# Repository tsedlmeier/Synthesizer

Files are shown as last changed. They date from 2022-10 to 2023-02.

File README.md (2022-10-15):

# Projektarbeit-Synthesizer

Dieses Repo ist in erster Linie für den Austausch von Dateien (LTspice-Modelle, Simulationen, Bauteilbibs etc.) gedacht.
Die Ordnerstruktur ist wie folgt: \
[ltspice/lib](./ltspice/lib/): hier könnt ihr eure Bauteilmodelle eintragen. \
[ltspice/<Modul>](./ltspice/): hier kann jeder einen Ordner mit dem Namen seines Moduls (VCO,VCF,VCA,ASMR,Sequencer,Netzteil etc.) erstellen und Simu-Dateien ablegen. 

Ansonsten erstellt jeder einen Ordner mit dem Namen seines Moduls und packt dort
Sachen rein, von denen er denkt, dass andere das sehen sollten.

## Nutzung des Repositorys

### Git-Konfiguration

Falls ihr noch nicht so viel Erfahrung mit Git habt hier ein kleines Intro.
Der Git-Config müsst ihr euren Namen und eure E-Mail-Adresse hinzufügen.

```bash
git config --global user.name "<Vorname> <Nachname>"
git config --global user.email "<verwendete E-Mail>"
```

Ihr solltet noch mit `git remote add origin git@github.com:tsedlmeier/Synthesizer.git` das Repo
unter dem Namen "origin" speichern (wird im weiteren Verlauf einfacher).

### SSH-Key eurem Git-Account hinzufügen

Damit könnt ihr Commits und Pulls durchführen, ohne dabei jedesmal euren Benutzernamen und Passwort
eingeben zu müssen. Dafür gebt ihr im Terminal `ssh-keygen` ein und wählt Pfad zum Key und Paraphrase (kann leer sein also einfach 2x Enter).
Jetzt sollte in eurem Home-Verzeichnis in dem Ordner ".ssh" eine Datei "id_<NAME>.pub" liegen. Den Inhalt
dieser Datei kopiert ihr bei eurem Git-Account im Browser unter "Settings -> SSH and GPG-Keys -> New
SSH-Key". Gebt eurem Key noch einen Namen.

### Klonen des Repos

Um das Repository auf eurem lokalen Rechner zu ziehen, müsst ihr dieses erstmal klonen (vorher Git konfigurieren!!!).

Das geschieht mit `git clone git@github.com:tsedlmeier/Synthesizer.git`.

### Änderungen an den Dateien durchführen

Ihr könnt mit `git checkout -b <BRANCH>` einen neuen Branch erstellen. (Ist für LTspice-Modelle etc.) eventuell etwas Overkill.

Änderungen ins Repo ziehen:

1. `git add <files>` 
2. `git commit -m "<kurze Nachricht an die Anderen was geändert wurde>"`
3. `git push`

### Lokales Repo aktualisieren

Wenn ihr die aktuellen Änderungen runterziehen wollt, dann geht das mit

```bash
git fetch origin
git pull --ff-only origin main
```

Eventuell vorhandene Branches müssen demnach auch aktualisiert werden. Dafür geht ihr in den Branch
und führt den Befehl `git rebase main` aus.

## Häufige Git-Befehle

|Kommando|Beschreibung|
|---|---|
|`git add <Files or Directory>`|Aktualisiert den Index mit den neuen Files|
|`git rm <Files or Directory>`|Entfernt die Files oder Directories vom Index|
|`git commit -m "<Message>"`|Erstellt einen Commit mit der Message, die mit -m angeben wird|
|`git push origin <Branch>`|Pusht die Daten vom Branch zu origin (Remote-Repo). Es sollte ein Pull-Request erzeugt werden|
|`git fetch origin`|Holt sich die Änderungen aus dem Remote-Repo "origin" (aber keine Aktualisierung des lokalen Repos!)|
|`git pull --ff-only origin main`|Aktualisiert den main-Branch des lokalen Repos (**im main-Branch ausführen!**) im Fast-Forward-Mode|
|`git checkout <Branch>`|Wechselt in den angegebenen Branch|
|`git checkout -b <Branch>`|Erstellt den angegebenen Branch und wechselt in diesen|
|`git status`|Zeigt anstehende Änderungen im aktuellen Branch an|
|`git log`|Zeigt die Commit Logs an|

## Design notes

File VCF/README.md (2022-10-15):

# Voltage Controlled Filter 
Hier eine kurze Doku zu meinem VCF. Dieses Markdown wird laufend aktualisiert.
Die Schaltung ist von Ray Wilson und auf der Website [MFOS] (http://musicfromouterspace.com/index.php?MAINTAB=SYNTHDIY&VPW=1344&VPH=561)
zu finden.

- [Anforderungen](#anforderungen)
- [Tiefpass](#tiefpass)
- [Hochpass](#hochpass)
- [CV](#cv)
- [Bauteile](#bauteile)
	<!--- - [Thema 3](#thema3)	-->

# Anforderungen
Folgende Annamen wurden getroffen:
- Eingangs CV V<sub>pp</sub> =~ 10V

| Parameter | Wert |
| --- | --- |
| `Gain` | `1 (0dB)` |
| `Cut-Off Frequenz ` | `100Hz - 10kHz` |
| `Resonanz (Q-Faktor)` | `TBD` |

# Tiefpass
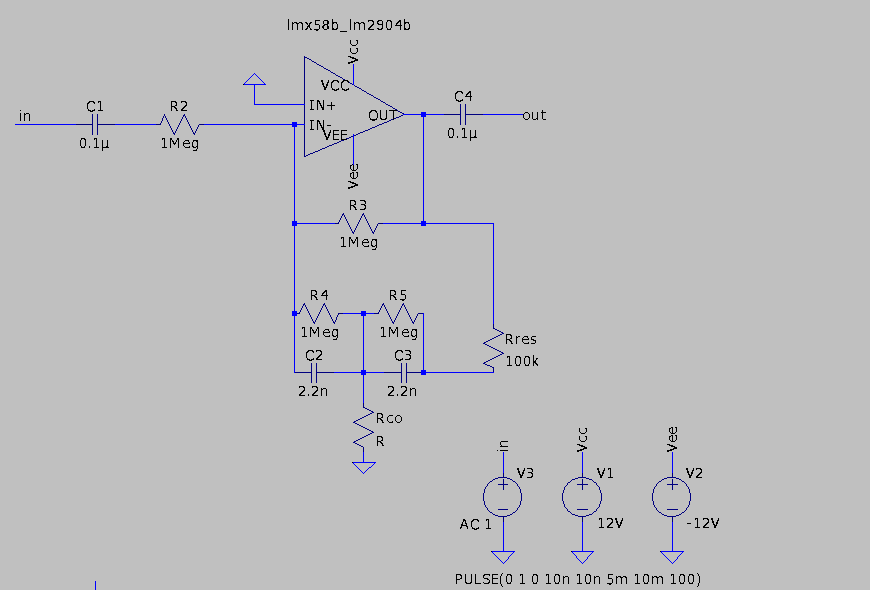
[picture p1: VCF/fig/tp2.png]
tp2

Es handelt sich um einen Aktiven Tiefpass 2. Ordnung mit einem Gain von 1.
Die Cut-Off Frequenz kann über den Rco eingestellt werden, indem er die Brücke aus den Kondensatoren C2 und C3 
näher bzw. weiter nach Ground zieht. Dieser wird später durch einen VCR (Voltage Controlled Resistor) ersetzt.
C1 wird für das Blocken von DC-Anteilen des Eingangssignals eingesetzt.
# Hochpass
# CV
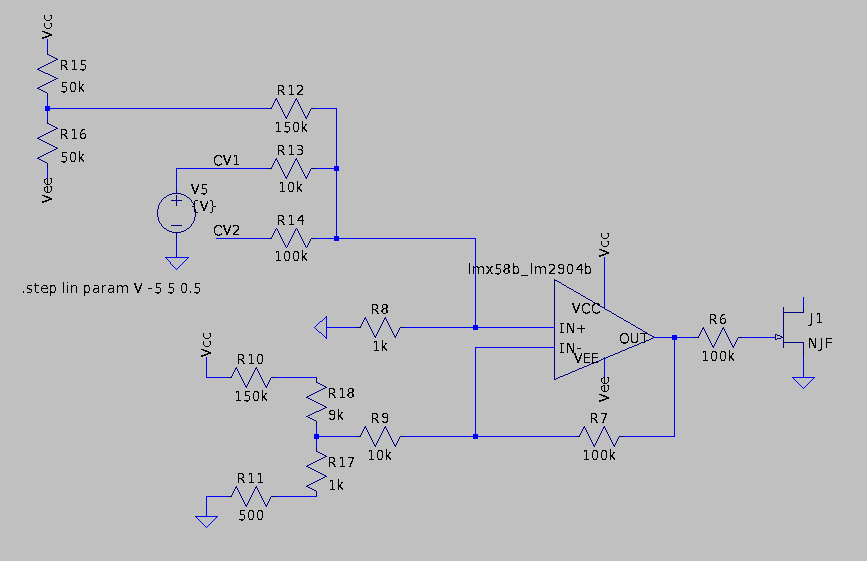
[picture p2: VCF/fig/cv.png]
cv

Hier handelt es sich um eine Schaltung für einen VCR (Voltage Controlled Resistor).
Dabei wird ein NJFET im ohmschen-Bereich betrieben.
Der 100k-Spannungsteiler aus R15 und R16 determinieren die Spannung V<sub>GS</sub> des NJFETs. 
Um den Spannungsbereich zu dieses Spannungsteilers einzustellen, wird ein weiterer Spannungsteiler aus R18 und R17 eingesetzt.
Zusammen mit R7 und R9, die den Verstärkunsfaktor des OPVs bestimmen, kann der Spannungsbereich von V<sub>GS</sub> eingestellt werden.
Diese Werte müssen auf den spezifisch verwendeten JFET abgestimmt werden.

# Bauteile
| Bauteil | Wert |
| --- | --- |
| `20x R` | `100 - 1MOhm` |
| `10x C` | `2.2nF - 1uF` |
| `4x OPV` | `LM358` |
| `1x NJFET` | `PN4391 NFET` |
| `4x Poti` | `100k` |
| `4x Klinke` | `3.5mm` |

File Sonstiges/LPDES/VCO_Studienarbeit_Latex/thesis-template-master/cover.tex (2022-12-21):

\thispagestyle{empty}
\pdfbookmark[1]{Cover}{cov}
\begin{titlepage}

\begin{center}

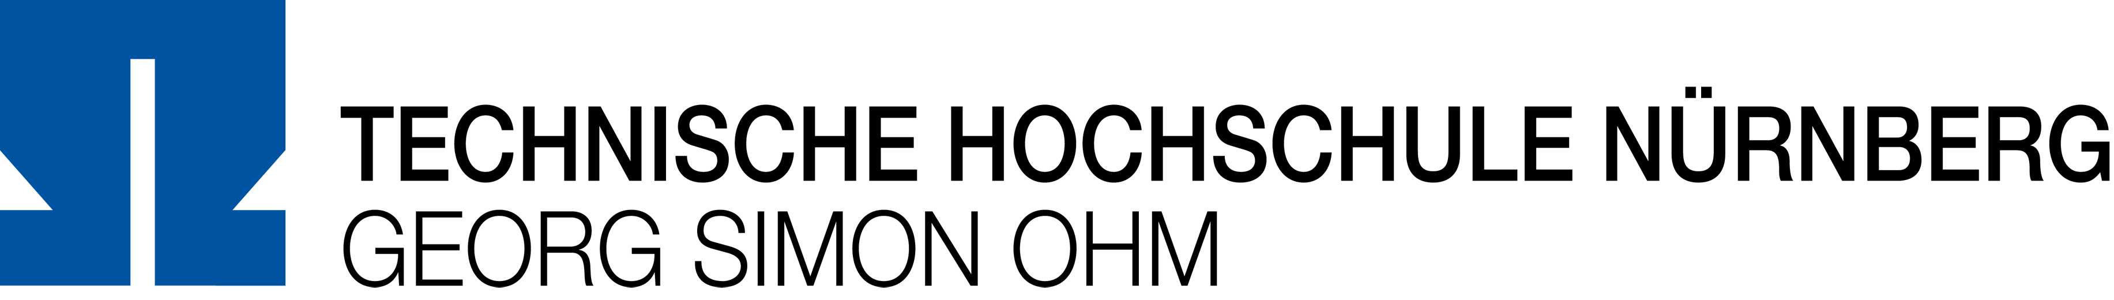
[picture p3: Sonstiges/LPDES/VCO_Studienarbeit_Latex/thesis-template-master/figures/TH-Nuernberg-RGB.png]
\\[1cm]
\LARGE{Fakultät Elektrotechnik Feinwerktechnik Informationstechnik}\\[2cm]

\huge
\textbf{\titel}\\[1cm]
%
\Large
\artderarbeit~im \studiengang\\[1cm]
%
\large
vorgelegt von

\Large
\autor\\[0.5cm]
\small

\vspace*{\fill}

\large
\begin{tabular}{p{3cm}p{8cm}}\\
%Ausgabe:  & \quad \ausgabe\\[1.2ex]
Abgabe: & \quad \abgabe\\[1.2ex]
Prüfer:  & \quad \erstgutachter\\[1.2ex]
%discomment "Betreuer" and "Unternehmen" for a thesis in a company
%Betreuer: & \quad \betreuer\\
%Unternehmen: & \quad \unternehmen
\end{tabular}
\end{center}

\begin{center}
\copyright\,\the\year
\end{center}

\vspace{-0.5cm}
\singlespacing
\small

\end{titlepage}

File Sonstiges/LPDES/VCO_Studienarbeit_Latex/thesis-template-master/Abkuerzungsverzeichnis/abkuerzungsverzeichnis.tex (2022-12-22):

\chapter{Abkürzungsverzeichnis}

%Erklärungen bündig
\setlist[description]{labelwidth=2cm}
\begin{acronym}
	\acro{ADSR}{\textit{Attack Decay Sustain Release}}
	 \acro{ERC}{\textit{Electrical Rule Check}}
	 \acro{DRC}{\textit{Design Rule Check}}
	\acro{LFO}{\textit{Low Frequency Oscillator}}
	\acro{VCA}{\textit{Voltage Controlled Amplifier}}
	\acro{VCF}{\textit{Voltage Controlled Filter}}
	\acro{VCO}{\textit{Voltage Controlled Oscillator}}
\end{acronym}

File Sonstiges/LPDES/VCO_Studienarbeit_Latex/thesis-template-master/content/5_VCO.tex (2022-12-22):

\chapter{VCO}
\label{ch:VCO}
\section{Allgemeines}

Der VCO stellt die Basis aller analogen Synthesizers da. 
Mit einem spannungsgesteuerten Oszillator lassen sich verschiedene Signale generieren, deren Frequenz sich mit der angelegten Steuerspannung verändert.
Analoge Synthesizer orientieren sich oft am 1V/Oktave-Standard.
Dieser besagt, dass sich die Frequenz des Signals mit jedem Volt verdoppelt.
Dies ist von Vorteil, da das Verhältnis zwischen Musiknoten und deren zugeordneten Frequenzen ebenfalls exponentiell ist.
Die tiefste C-Note entspricht beispielsweise einer Frequenz von 16,35 Hz.
Wenn man eine Oktave nach oben geht, verdoppelt sich die Frequenz beim nächsten C auf etwa 32 Hz. Typische Signale bei analogen Synthesizern können der Abbildung \ref{fig:Waveforms} entnommen werden. \cite{MakeSynth}

\begin{figure}[h]
	\centering
	\setlength{\fboxsep}{1pt} %Abstand der Linien zur Abbildung
	\setlength{\fboxrule}{1pt} %Dicke der Linie
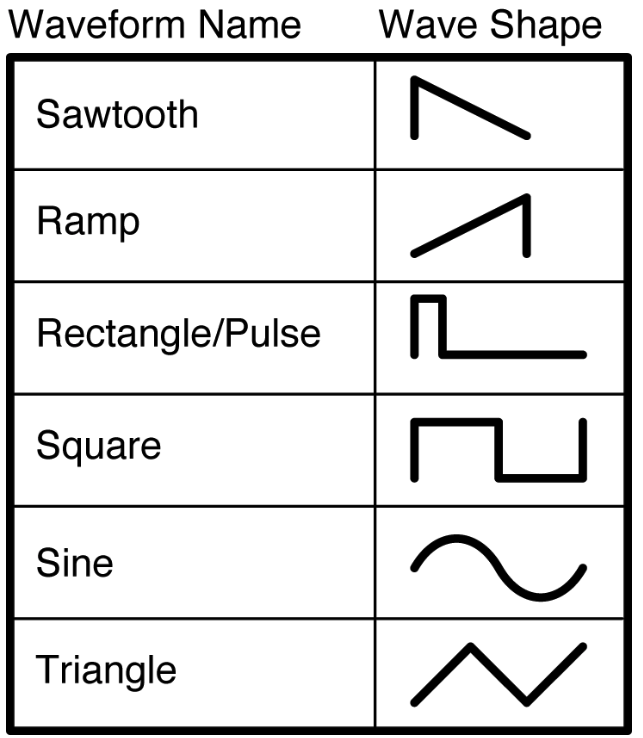
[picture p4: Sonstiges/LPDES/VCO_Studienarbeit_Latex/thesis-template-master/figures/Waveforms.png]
	\fbox{}
	\caption{Typische Signale bei analogen Synthesizern \cite{MakeSynth}}
	\label{fig:Waveforms}
\end{figure}

Bei dieser Umsetzung des VCOs wurde sich auf die Realisierung eines Sägezahn- und eines Rechtecksignals konzentriert, da diese aufgrund ihrem hohen Oberwellenanteil markant-hörbare Geräusche erzeugen.
Ein Sinussignal hingegen stellt einen harmonischen Verlauf dar, der sich ebenfalls im Klang äußert.
Hörbare Schwingungen werden mithilfe einer Oszillatorschaltung realisiert, auf die im Folgenden näher eingegangen wird.

\begin{figure}[h]
	\centering
	\setlength{\fboxsep}{1pt} %Abstand der Linien zur Abbildung
	\setlength{\fboxrule}{1pt} %Dicke der Linie
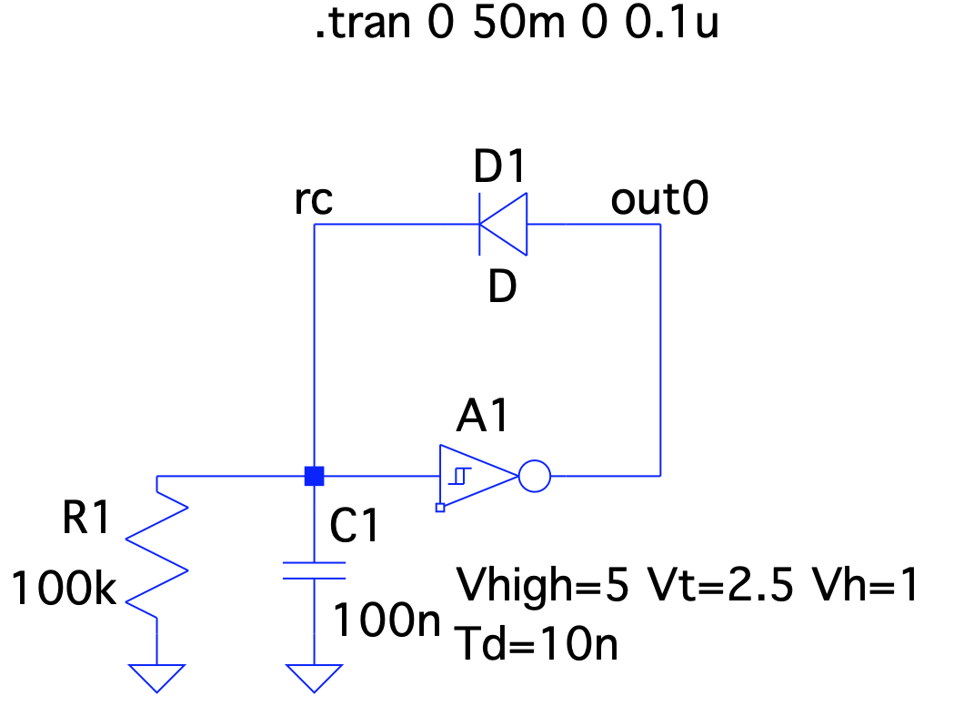
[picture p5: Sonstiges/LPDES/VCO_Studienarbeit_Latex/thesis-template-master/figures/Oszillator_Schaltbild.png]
	\fbox{}
	\caption{Oszillatorschaltung}
	\label{fig:Oszillatorschaltung}
\end{figure}

Um die Oszillatorschaltung (vgl. Abbildung \ref{fig:Oszillatorschaltung}), die den Kern des VCOs darstellt, zu verstehen, erfolgt die Betrachtung des Punktes \textit{rc}.
Zu Beginn liegt keine Spannung an, weil der Kondensator leer ist und noch kein Strom durch die Diode fließt. 
Das bedeutet, dass am Ausgang des Schmitt-Trigger-Inverters eine Spannung anliegt, da der Eingang unter dem unteren Eingangsschwellenwert liegt. 
Dadurch erfolgt ein Stromfluss vom Ausgang des Schmitt-Triggers über die Diode zu dem Punkt \textit{rc}. 
Da der Kondensator zunächst leer ist, fließt der ganze Strom in diesen hinein.
Während sich der Kondensator auflädt, steigt die Spannung an dem Punkt \textit{rc} rapide an.
Dieser Spannungsanstieg wird vom Schmitt-Trigger-Eingang registriert. 
Als Reaktion darauf fällt der Ausgang auf 0 V ab, sobald der Kondensator aufgeladen ist und die Spannung die obere Eingangsschwelle überschreitet.
Das bedeutet, dass kein zusätzlicher Strom durch die Diode fließt und sich der Kondensator wieder entlädt. 
Da der Widerstand die Strommenge begrenzt, die durchfließen kann, wird der Kondensator nicht sofort entladen. 
Auf dem Spannungsdiagramm entsteht also ein langsamer Abfall. 
Das geht so lange, bis der untere Schwellenwert des Schmitt-Trigger-Inverters erreicht wird. 
Sobald diese Schwelle auf dem Weg nach unten unterschritten ist, beginnt der Zyklus von neuem.
Die Simulation der Schaltung ergibt den Spannungsverlauf am Punkt \textit{rc} in Abbildung \ref{fig:Oszillator_Signalverlauf}.

\begin{figure}[h]
	\centering
	\setlength{\fboxsep}{1pt} %Abstand der Linien zur Abbildung
	\setlength{\fboxrule}{1pt} %Dicke der Linie
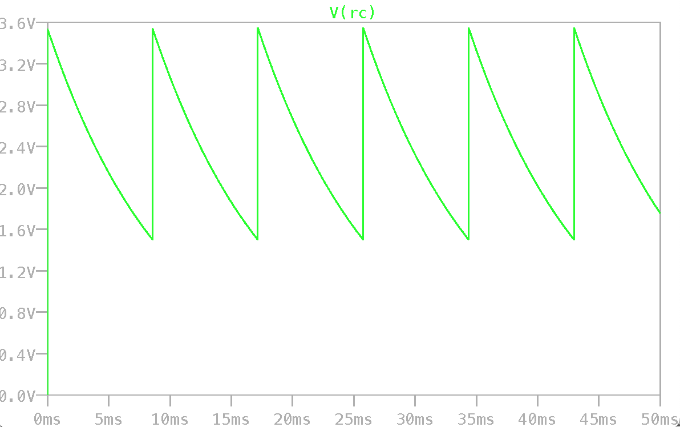
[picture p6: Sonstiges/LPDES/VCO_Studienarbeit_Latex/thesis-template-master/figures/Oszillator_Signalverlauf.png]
	\fbox{}
	\caption{Oszillator Signalverlauf}
	\label{fig:Oszillator_Signalverlauf}
\end{figure}

\newpage

Die Frequenz des entstandenen Sägezahnsignals hängt maßgeblich von dem Entladungsvorgang des Kondensators ab.
Die Geschwindigkeit dieses Entladungsvorganges wird widerum durch genau zwei Faktoren bestimmt: die Kapazität des Kondensators und der Wert des Widerstands.
Um den VCO an die Volt/Oktave-Norm anzupassen, muss die Beziehung zwischen Spannungseingang und Frequenzausgang ebenfalls exponentiell sein, da im Grunde genommen Spannungen auf Musiknoten abgebildet werden. 
Transistoren sind hier besonders geeignet, da das Verhältnis zwischen der an ihrer Basis angelegten Spannung und dem Strom, den sie zwischen Kollektor und Emitter fließen lassen, exponentiell ist.
Die Basisspannung kann mithilfe eines Potentiometers eingestellt werden.
Zu beachten ist allerdings, dass bei einem üblichen NPN-Transistor die Kollektor-Emitter Strecke ab etwa einer BasisSpannung von 600 -- 700 mV niederohmig wird und der Oszillator bei Anliegen dieser Schwellspannung nicht mehr schwingt. 
Liegt keine Spannung an, ist die Kollektor-Emitter Strecke hochohmig und der Oszillator kann ebenfalls nicht mehr schwingen.
Der durch Ausprobieren ermittelte nutzbare Spannungbereich beträgt etwa 350 -- 550 mV.
Dies wird mithilfe eines einstellbaren Spannungsteilers realisiert. 

Die verwendete Schaltung in Abbildung \ref{fig:VCO_Stromlaufplan} ist zu großen Teilen an ein \textit{DIY VCO Kit} von Moritz Klein und Erica Synths angelehnt und wird im Folgenden näher erklärt. \cite{vco_manual}

\section{Schaltplan}
Wie im vorherigen Kapitel erläutert, erfolgt die Veränderung der Frequenz der Sägezahnschwingung (vgl. Abbildung  \ref{fig:Oszillator_Signalverlauf}) mithilfe eines NPN-Transistors, welcher im ersten Bereich des Schaltplans zu sehen ist. 
Der davor geschaltene PNP-Transistor dient zur Temperaturkompensation und fungiert als Emitterfolger, indem die an seiner Basis anliegende Spannung an den Emitter kopiert wird.
Allerdings ist die am Emitter des PNP-Transistors anliegende Spannung um der Schwellspannung des Transistors höher.
Bei Versuchen an der realen Schaltung betrug diese etwa 500 mV.
Um den gewünschten Spannungsbereich an der Basis des NPN-Transistors von etwa 350 -- 550 mV zu erreichen, muss das Potentiometer für die Einstellung der Basisspannung der Transistoren auch negative Spannungswerte liefern.

Aus diesem Grund wird im zweiten Bereich des Schaltplans das Potentiometer VR1 für die grobe Einstellung der Frequenz zwischen der negativen und positiven Versorgunsspannung angeschlossen.
Da die Versorgungsspanung $\pm$12 V beträgt, wird diese mithilfe entsprechender Spannungteiler (R1, R2, R3, R7, R8) um etwa das 50-fache auf ca. -130 -- 20 mV verringert.
Für die Feineinstellung der Frequenz (VR2) wird durch einen größeren Widerstand (R4) ein Teilerfaktor von etwa 500 realisiert, der eine Spannung im Bereich von -10 -- 0 mV liefert.
Mithilfe dem Eingang \textit{CV\_IN} (\textit{Control Voltage In}) kann ein Sequencer mit einem Klinkenkabel angeschlossen werden, der eine Eingangsspannung von 0 -- 5 V liefert.
Um die Volt/Oktave-Norm anzuwenden wird aufgrund von Bauteiltoleranzen zusätzlich ein Präzisiondrehpotentiometer (R8) verwendet, damit das Verhältnis des Spannungsteilers justiert werden kann.
Die Klinkenbuchse \textit{FM\_IN} (\textit{Frequency Modulation In}) stellt im Prinzip einen weiteren \textit{Control Voltage}-Eingang dar, dessen Intensität zusätzlich durch ein Potentiometer eingestellt werden kann. 
An diesen kann beispielsweise ein LFO (\textit{Low Frequency Oscillator}) angeschlossen werden.
Um die Temperaturabhängigkeit der Schaltung zu verbessern, wird weiterhin an allen Eingängen ein NTC-Widerstand angebracht.

Um die resultierende Sägezahnschwingung nach außen führen zu können, wird ein entsprechender Buffer benötigt, der durch einen Operationsverstärker realisiert wird.
Dies ist zwingend notwendig, da ansonsten in die Funktionsweise der Oszillatorschaltung eingegriffen wird. 
Dieser Buffer befindet sich im dritten Bereich des Schaltplans.
Weiterhin wird eine AC-Kopplung mithilfe des Kondensators C2 und dem Widerstand R10 realisiert. 
Diese wird benötigt um eine eventuelle Offset-Spannung der Sägezahnspannung zu entfernen, damit das Signal um den definierten Pegel von 0 V schwingt.

Im vierten Bereich des Schaltplans wird das Rechtecksignal generiert. 
Dies erfolgt durch eine Komperatorschaltung.
An den invertierenden Eingang des Operationsverstärker wird die zu vergleichende Schwellspannung angelegt. 
Wird diese überschritten, liefert der Operationsverstärker 12 V. 
Bei Unterschreitung der Schwellspannung liefert dieser -12 V.
Wird die zu vergleichende Spannung variiert, ändert sich das Pulsbreitenverhältnis.
Zu beachten ist, dass die einstellbare Schwellspannung nicht höher als die Spannung des Signals selber sein darf, da dadurch der Ausgang einen festen Pegel erhält und kein oszillierendes Signal mehr darstellt.
Die Spannung des Sägezahnsignals beträgt an diesem Punkt etwa $\pm$1,5 V.
Durch das Potentiometer VR4 kann die Pulsbreite des Rechtecksignals eingestellt werden.
Mithilfe dem Spannungsteiler (R14, R17) wird die einstellbare Schwellspannung von $\pm$12 V auf etwa $\pm$1,5 V begrenzt, damit sichgerstellt wird, dass die Schwellspannung nicht höher als das Signal ist.
Mithilfe dem Eingang \textit{PWM\_In} kann die Pulsbreite durch ein anderes Signal wie beispielsweise eines LFOs extern moduliert werden.

Im fünften Bereich des Schaltplans erfolgt die Anpassung auf einen definierten Pegel von 10 V peak-to-peak. 
Da die Sägezahnschwingung eine geringe Spannung aufweist, wird diese mithilfe einer nicht invertierenden Verstärkerschaltung vergrößert und an den Klinkenbuchsenausgang \textit{SAW\_OUT} geführt. 
Da der Spannungspegel des Rechtecksignals durch die Komperatorschaltung verstärkt wurde, muss dieser mithilfe eines Spannungsteilers (R15, R18) entsprechend reduziert werden. 
Schließlich wird das Ausgangssignal durch einen Buffer an den Ausgang \textit{PULSE\_OUT} geführt.

Der nicht eingerahmte Bereich im Schaltplan umfasst die Spannungsversorgung. 
Mihilfe von Schottky-Dioden (D2, D3) wird der Verpolungsschutz der Eingangsspannung von $\pm$12 V gewährleistet. 
Durch die Stützkondensatoren (C3 -- C7) wird die Versorgungsspannung sowohl am Eingang der Spannungsversorgung am Wannenstecker als auch an den IC-Pins stabilisiert.
Weiterhin werden nicht verwendete Eingänge des Schmitt-Triggers mit Masse verbunden.

In der folgenden Tabelle werden die Ein- und Ausgabeelemente des VCOs zusammengefasst:

\begin{table}[h]
	\centering
	\caption{Zusammenfassung der Ein- und Ausgabeelemente des VCOs}
	\begin{tabular}{|c|c|p{8cm}|}
		\hline
		Bauteilbezeichnung & Kurzbeschreibung & Funktion \\
		\hline
		VR1 & \textit{Coarse} & Grobeinstellung der Frequenz \\
		\hline
		VR2 & \textit{Fine} & Feineinstellung der Frequenz \\
		\hline
		VR3 & \textit{FM LVL} & Einstellung der Intensität des FM-Eingangs \\
		\hline
		VR4 & \textit{PWM} & Einstellung der Pulsweite\\
		\hline
		VR5 & \textit{PWM LVL} &  Einstellung der Intensität des externen Signals zur Pulsweitenmodulation \\
		\hline
		J2 &  \textit{CV IN} & Eingang der Steuerspannung \\
		\hline
		J3 & \textit{FM IN} & Eingang der Steuerspannung \newline zusätzliche Einstellmöglichkeit der Intensität durch VR3 \\
		\hline
		J4 & \textit{PWM IN} &  Eingang des externen Signals zur Pulsweitenmodulation\\
		\hline
		J5 & \textit{Saw Out} &  Ausgang des generierten Sägezahnsignals\\
		\hline
		J5 & \textit{Pulse Out} &  Ausgang des generierten Rechtecksignals \\
		\hline
	\end{tabular}
\end{table}

Nachdem die Funktionsweise der Schaltung auf einem Breadboard verifiziert wurde, wird ein Platinenlayout erstellt.
Auf die Vorgehensweise bei der Layouterstellung wird im folgenden Kapitel näher eingegangen.

\newpage
\begin{figure}[h]
\centering
\includepdf[angle=270, clip, trim=1cm 0.8cm 0.8cm 0.8cm, scale=0.8] {figures/VCO_Stromlaufplan_v2_unterteilt.pdf}
%\caption{In Bereiche unterteilter Schaltplan des Sequenzers}
\caption{Schaltplan VCO}
\label{fig:VCO_Stromlaufplan}
\end{figure}

\newpage

\section{Platine}
Nachdem der Schaltplan in Fusion 360 erstellt wurde und mit dem ERC (Electrical Rule Check)-Tool validiert wurde, erfolgt die Erstellung des Platinenlayouts (siehe Abbildung \ref{fig:VCO Layout}).
Die äußeren Abmaße der Platine sind in Bezug auf die Höhe eines \textit{Euro Racks} von 128,5 mm beschränkt. 
Gewählt wurde eine Platinenhöhe von 100 mm, damit ausreichend Platz zur Befestigung der Leiterplatte gewährleistet ist.

\begin{figure}[h]
	\centering
	\setlength{\fboxsep}{1pt} %Abstand der Linien zur Abbildung
	\setlength{\fboxrule}{1pt} %Dicke der Linie
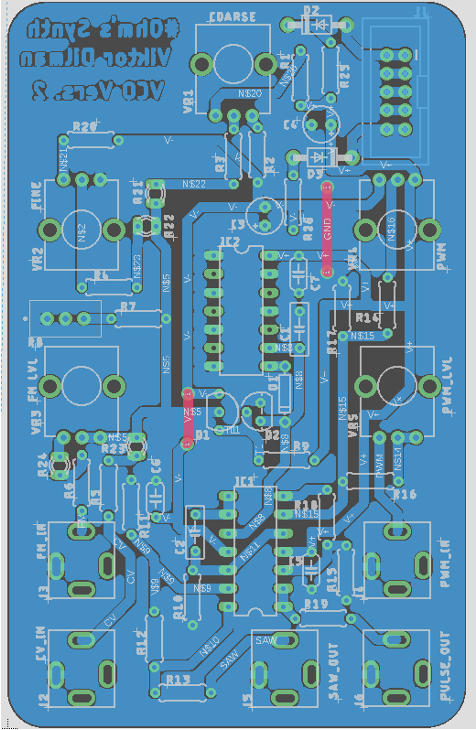
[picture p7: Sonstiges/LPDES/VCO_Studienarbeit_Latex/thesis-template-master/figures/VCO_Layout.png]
	\fbox{}
	\caption{VCO Layout in Fusion 360}
	\label{fig:VCO Layout}
\end{figure}

Die Bauteile wurden einerseits so positioniert, dass die Leiterbahnen möglichst kurz und überschneidungsfrei verlegt werden können.
Andererseits wurden die Potentiometer und Klinkenbuchsen logisch so angeordnet dass die zu einer Einbauklinkenbuchse gehörenden Potentiometer übereinander liegen.
Weiterhin wurde darauf geachtet, dass die Transistoren für die Temperaturkompensation möglichst nah aneinander positioniert werden.
Zudem sind die Stützkondensatoren der ICs möglichst nah an den Versorgungspins der Bauteile zu positionieren.

Bei der Erstellung der Platine wurde darauf geachtet möglichst eine Layer zu verwenden, um die Platine mit einer Platinenfräse herstellen zu können.
Dies ist von Vorteil, da bei der professionellen Anfertigung von Platinen von der Bestellung bis zur Lieferung einige Wochen vergehen können.
Ist der Zugang zu einer Fräse gegeben, kann die erstellte Platine sofort getestet und eventuelle Fehler ausgebessert werden.

Damit die Leiterplatte mit einer Platinenfräse angefertigt werden kann, ist eine relativ dicke Leiterbahnbreite erforderlich. 
Gewählt wurde deshalb eine Leiterbrahnbreite von 50 mil.
An den Stellen, an denen die Leiterbahnen nicht überschneidungsfrei verlegt werden konnten, wurden \textit{Vias} hinzugefügt und die Leiterbahn auf der anderen Seite fortgeführt.
Auf der gefrästen Platinen können diese \textit{Vias} mit Brücken verbunden werden.

Da für die verwendeten Einbauklinkenbuchsen keine passende Bibliothek existiert, musste diese manuell angelegt werden.
Dafür wurde ein Symbol einer ähnlichen Klinkenbuchse verwendet und das Footprint nach dem Datenblatt des Herstellers erstellt wie in Abbildung \ref{fig:Einbauklinkenbuchse in Fusion 360} zu sehen. \cite{cliff}

\begin{figure}[h]

\end{figure}

\begin{figure}[h]
	\centering
	\begin{subfigure}{.5\textwidth}
	\centering
	\setlength{\fboxsep}{1pt} %Abstand der Linien zur Abbildung
	\setlength{\fboxrule}{1pt} %Dicke der Linie
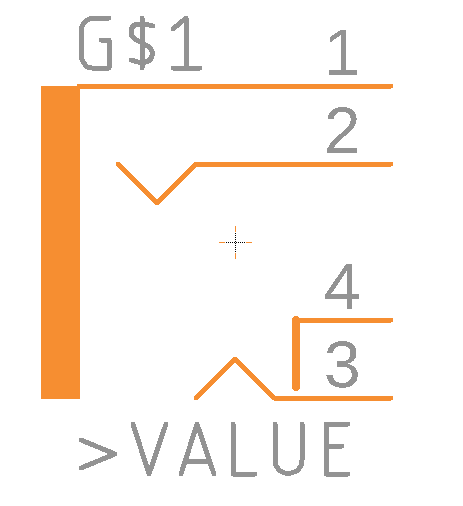
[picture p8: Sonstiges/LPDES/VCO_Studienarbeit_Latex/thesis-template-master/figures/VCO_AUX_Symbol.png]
	\fbox{}
	\caption{Verwendetes Symbol}
	\label{fig:Klinkenbuchse Symbol}
	\end{subfigure}%
	\begin{subfigure}{.5\textwidth}
	\centering
	\setlength{\fboxsep}{1pt} %Abstand der Linien zur Abbildung
	\setlength{\fboxrule}{1pt} %Dicke der Linie
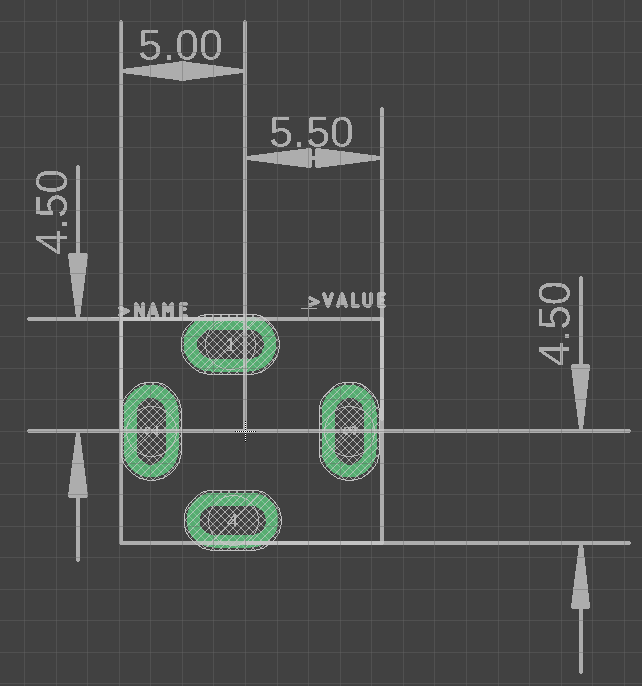
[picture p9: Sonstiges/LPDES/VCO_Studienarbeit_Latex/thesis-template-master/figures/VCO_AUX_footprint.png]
	\fbox{}
	\caption{Erstelltes Footprint}
	\label{fig:Klinkenbuchse Footprint}
	\end{subfigure}
	\caption{Erstellung der Einbauklinkenbuchse in Fusion 360}
	\label{fig:Einbauklinkenbuchse in Fusion 360}
\end{figure}

Nachdem die erstellte Leiterplatte mit dem DRC (\textit{Design Rule Check})-Tool in \textit{Fusion 360} auf Fehlerfreiheit geprüft wurde, erfolgt der Export der \textit{Gerber-Files}.
%\begin{figure}[h]
%	\centering
%	\setlength{\fboxsep}{1pt} %Abstand der Linien zur Abbildung
%	\setlength{\fboxrule}{1pt} %Dicke der Linie
%	\fbox{\includegraphics[width=0.5\textwidth]{figures/Fusion Export Gerber}}
%	\caption{Fusion 360 Gerber Export}
%	\label{fig:Gerber}
%\end{figure}
Die Leiterplatte wurde dabei mit einer Platinenfräse von \textit{Bantam Tools} hergestellt.
%\begin{figure}[h]
%	\centering
%	\setlength{\fboxsep}{1pt} %Abstand der Linien zur Abbildung
%	\setlength{\fboxrule}{1pt} %Dicke der Linie
%	\fbox{\includegraphics[width=0.5\textwidth]{figures/VCO_gefraest}}
%	\caption{VCO Platine gefräst}
%	\label{fig:VCO Fräse}
%\end{figure}
%\newpage
Anschließend erfolgt die Bestückung der Leiterplatte mit den im Stromlaufplan verwendeten Komponenten und das Testen der Platine. 
Ist die Funktion der gefrästen Leiterplatte geprüft, erfolgt die Bestellung bei dem Platinenhersteller \textit{Aisler}. 
In Abbildung \ref{fig:VCO_Front} ist die Vorderseite der Platine zu sehen.
Die Abbildung \ref{fig:VCO_Back} zeigt hingegen die Rückseite der VCO-Leiterplatte. 

\begin{figure}[h]
	\centering
	\begin{subfigure}{.5\textwidth}
		\centering
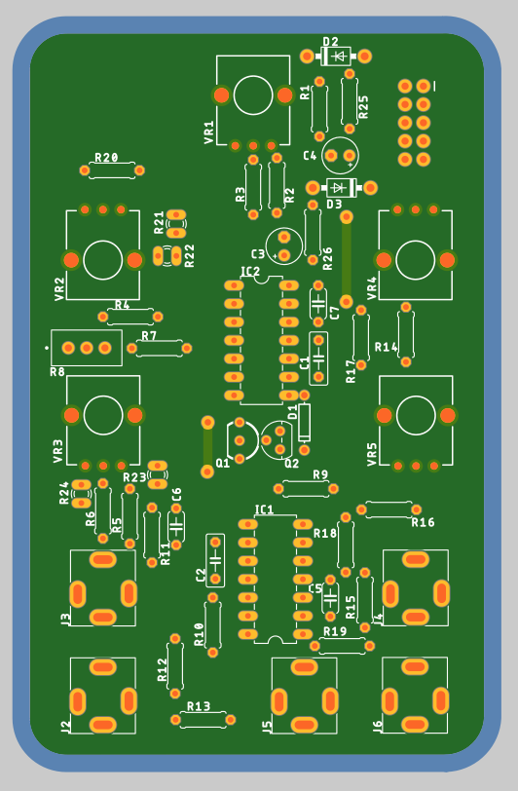
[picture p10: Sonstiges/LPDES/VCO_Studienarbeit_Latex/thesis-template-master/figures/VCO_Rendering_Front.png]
		
		\caption{Vorderseite}
		\label{fig:VCO_Front}
	\end{subfigure}%
	\begin{subfigure}{.5\textwidth}
		\centering
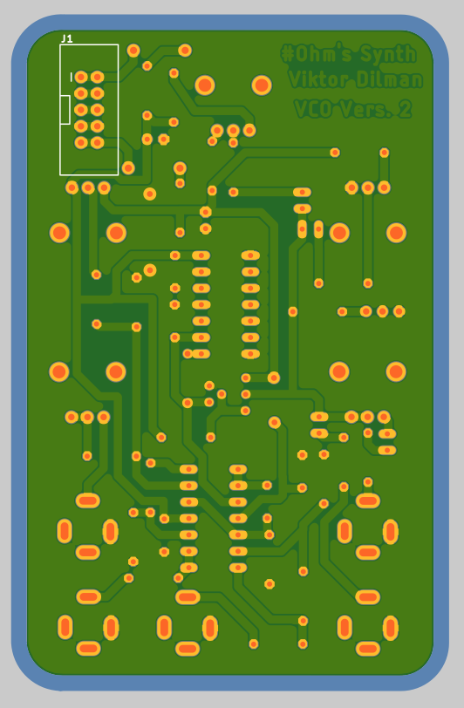
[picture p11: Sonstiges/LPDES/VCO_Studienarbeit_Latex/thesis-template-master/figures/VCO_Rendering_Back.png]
		
		\caption{Rückseite}
		\label{fig:VCO_Back}
	\end{subfigure}
	\caption{VCO Leiterplatte}
	\label{fig:VCO Leiterplatte}
\end{figure}

\newpage
\section{Mechanischer Aufbau}
Mithilfe der \textit{Fusion 360}-Funktionalität der Übertragung einer 2D- auf eine 3D-Leiterplatte wurde eine Abdeckung konstruiert (siehe Abbildung \ref{fig:VCO Frontplattemit 3D-Leiterplatte}).
Dies hat den Vorteil, dass für die Potentiometer und Klinkenbuchsen die Aussparungen an der Frontplatte exakt positioniert werden können.
Die Abdeckplatte wird mithilfe von Gewindeschrauben der Einbauklinkenbuchsen an die Platine befestigt.
Weiterhin werden auf die Potentiometer Abdeckkappen angebracht, die zusätzlichen Halt bieten.
An den Ecken der Frontplatte werden Aussparungen vorhergesehen, um das Modul in einem Eurorack-Gehäuse befestigen zu können.
Schließlich wird die Frontplatte aus Plexiglas mit einem \textit{Laser-Cutter} gefertigt.

\begin{figure}[h]
	\centering
	\setlength{\fboxsep}{1pt} %Abstand der Linien zur Abbildung
	\setlength{\fboxrule}{1pt} %Dicke der Linie
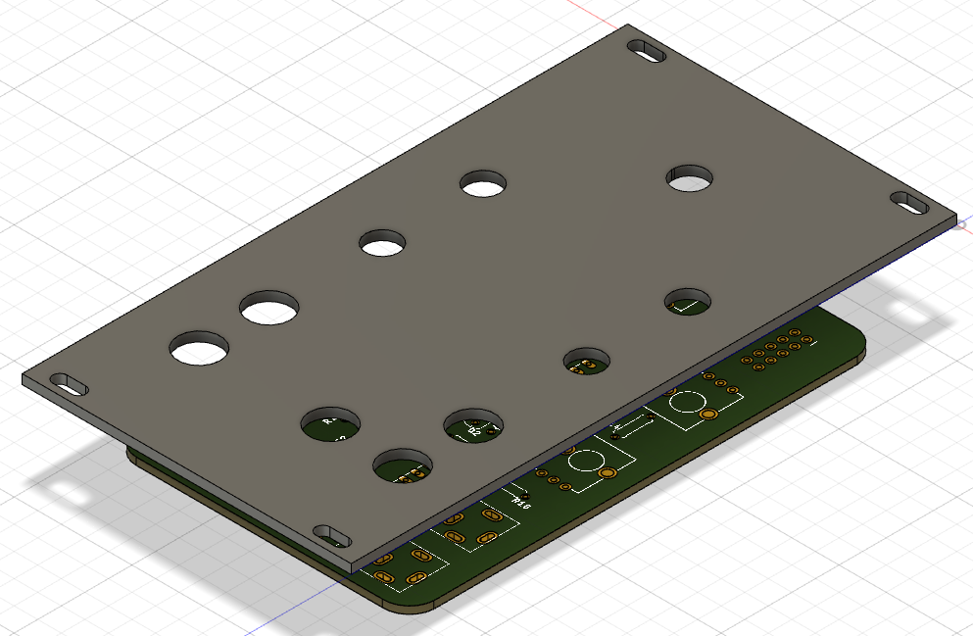
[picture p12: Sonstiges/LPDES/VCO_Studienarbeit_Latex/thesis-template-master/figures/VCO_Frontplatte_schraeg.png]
	\fbox{}
	\caption{VCO Frontplatte}
	\label{fig:VCO Frontplattemit 3D-Leiterplatte}
\end{figure}

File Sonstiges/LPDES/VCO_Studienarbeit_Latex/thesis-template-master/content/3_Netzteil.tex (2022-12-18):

\chapter{Netzteil}
\label{ch:Netzteil}

\section{Allgemeines}
Um eine fehlerfreie Funktion aller weiteren Module zu gewährleisten, ist es wichtig, dass eine geeignete Spannungsversorgung bereitgestellt wird. 
Insbesondere für die Opamp-Schaltungen ist es wichtig, dass eine störfreie symmetrische Spannung bereitgestellt wird. 
Im Bereich der modularen Synthesizer wird hier typischerweise eine Spannung von +/- 12 V benötigt. Diese Spannungspegel werden durch eine geignete Beschaltung von Dioden und Kondensatoren generiert, welche in Abschnitt \ref{sec:netzteil_schaltplan} bzw. \ref{sec:netzteil_umsetzung} genauer erläutert wird. Hierbei wird die für modulare Synthesizer typischerweise eingesetzte Wannenstecker-Belegung verwendet. Diese wird entsprechend in allen Modulen eingesetzt!

\section{Schaltplan}
\label{sec:netzteil_schaltplan}
bla bla bla

\section{Umsetzung}
\label{sec:netzteil_umsetzung}
bla bla bla

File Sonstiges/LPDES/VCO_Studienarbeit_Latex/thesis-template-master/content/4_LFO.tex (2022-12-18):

\chapter{LFO}
\label{ch:LFO}

\section{Allgemeines}
Wie bereits in Kapitel \label{ch:concept} beschrieben, wird der LFO genutzt, um niederfrequente Signale zu erzeugen. 
Diese Signale werden typischerweise zur Steuerung von nachgelagerten Modulen, wie etwa dem LFO (siehe Kapitel \ref{ch:VCO}), verwendet.
Hierdurch kann beispielsweise die Frequenz des VCO angepasst werden. 
Neben der Frequenz, die der LFO ausgibt, ist auch die entsprechende Signalform für den Klang entscheidend. Hier sind beispielsweise Signalformen, wie Dreieck oder Rechteck möglich.

\section{Schaltplan}
Im Folgenden wird näher auf den Schaltplan des LFO eingegangen, welcher in Abbildung \ref{fig:LFO_Stromlaufplan} zu sehen ist. 
Ein Bauteil von zentraler Bedeutung ist hierbei der Vierfach-Operationsverstärker TL074P. In der gezeigten Schaltung wird dieser als Integrator, Schmitt Trigger, Buffer und LED-Treiber verwendet.
Die grundlegende Funktionsweise dieser Funktionsgruppen wurde bereits in Abschnitt \ref{sec:AnalogePrinzipien} erläutert und wird deshalb nicht erneut aufgezeigt.

\newpage
\begin{figure}[h]
\centering
\includepdf[angle=270, clip, trim=1cm 0.8cm 0.8cm 0.8cm, scale=0.8] {figures/Schaltplan_LFO_Kirschner_08_12_22.pdf}
\caption{Fusion360 Schaltplan des LFO}
\label{fig:LFO_Stromlaufplan}
\end{figure}
 
\newpage

\section{Platine}
bla bla bla

\section{Mechanischer Aufbau}
bla bla bla

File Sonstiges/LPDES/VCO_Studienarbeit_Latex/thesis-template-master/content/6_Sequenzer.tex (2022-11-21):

\chapter{Sequenzer}
\label{ch:Sequenzer}
\section{Allgemeines}
Bei dieser Umsetzung eines Sequenzers wurde sich für maximal fünf alternierende Spannungspegel entschieden. In der Literatur ist diese Unterart als 5-Step-Sequencer bekannt, welche wegen ihrer markanten Charakteristik zum Beispiel im bekannten >>Hier Name des Syntis im Labor einsetzten<< Synthesizer eingesetzt wird. >>Als Quelle Manual von genanntem Synti nennen<<. Über zwei in der Handebene verbaute Kippschalter kann alternativ zwischen 3- bzw. 4-Stufen-Betrieb gewählt werden. Welcher Schritt aktuell aktiv ist wird durch Status-LEDs in der Frontplatte angezeigt.\\
Als Spannungsversorgung erhält der Sequenzer \textpm 12 Volt durch das verbaute Netzteil (vgl. Kapitel \ref{ch:Netzteil}). Optional kann ein externes Clock-Signal, beispielsweise von einem LFO (vgl. Kapitel \ref{ch:LFO}), angeschlossen werden. Der eigene Takt wird dadurch überbrückt, wodurch das Modul flexibel eingesetzt werden kann. Des Weiteren kann die Sequenz durch ein externes Signal zurückgesetzt werden. Dadurch wird automatisch wieder bei der ersten Stufe der Sequenz begonnen, wodurch dem Nutzer weiterer musikalischer Freiraum freigeräumt wird.\\
Das Sequenzer-Modul verfügt über drei abgreifbare Ausgangssignale. Ein Clock-Signal, welches über ein Potentiometer in der Handebene parametrisiert werden kann, gibt den internen Takt des Moduls vor, und kann von außerhalb abgegriffen werden. Dessen Spannung toggelt dabei zwischen -12 und +12 Volt. Die Control Voltage (CV) wird zumeist dem VCO (vgl. Kapitel \ref{ch:VCO}) zur weiteren Verarbeitung überreicht. Dabei handelt es sich um eine alternierende Spannungsfolge, welche zwischen 0 und 5 Volt schwanken kann. Die einzelnen Spannungspegel der bis zu fünf Stufen werden durch ein jeweiliges Potentiometer in der Handebene eingestellt. Das dritte Ausgangssignal des Sequenzers bildet der Gate. Ähnlich dem CV wird eine alternierende Spannungsfolge von bis zu fünf Stufen ausgegeben, wobei eine Stufe in zwei Abschnitte geteilt wird. Der erste Abschnitt beträgt, abhängig dem jeweiligen Kippschalter in der Handebene, entweder +12 oder 0 Volt. Der zweite Abschnitt führt immer 0 Volt. Der Gate verhält sich somit ähnlich dem Clock-Signal. Er führt jedoch niemals eine Negative Spannung und seine Stufen sind manuell zuschaltbar. In der Regel wird der Gate als Eingangssignal für den ADSR (vgl. Kapitel xxx) hergenommen.

\section{Schaltplan}
\newpage	%Seite leer beenden und Umbruch

\begin{figure}[h]
	\centering
	\includepdf[angle=270, clip, trim=1.7cm 0.85cm 0.8cm 1.65cm, scale=0.9] {figures/Schaltplan_Sequenzer_Christoph_Kirschner_unterteilt.pdf}
	%\caption{In Bereiche unterteilter Schaltplan des Sequenzers}
	\label{fig:In_Bereiche_unterteilter_Schaltplan_des_Sequenzers}
\end{figure}

\newpage	%Seite leer beenden und Umbruch
Der Schaltplan des Sequenzers lässt sich, wie in Abbildung \ref{fig:In_Bereiche_unterteilter_Schaltplan_des_Sequenzers} gezeigt, in sechs Bereiche unterteilen. Der Bereich eins ist zuständig für das Durchschalten der Zustände. Die wesentliche Komponente ist dabei das Bauteil U1G1. Es handelt sich dabei um einen CD4017 Dekadenzähler, der durch das Toggeln des Clock-Signals die verschiedenen Zustände durchschaltet. Der Sequenzer ist für eine Sequenz von maximal 5 Stufen ausgelegt. Durch die beiden Schalter J11 und J12 kann diese jedoch auf 4 bzw. 3 Stufen reduziert werden, was sich an der Rückführung der jeweiligen Stufen auf den RESET-Pin erkennen lässt. Durch den RESET-Eingang J13 lässt sich zusätzlich ein externes Signal einbinden, was einen Fremd-RESET ermöglicht.\\
Der zweite Bereich des Schaltplans kümmert sich um das Clock-Signal. Dafür wird der Operationsverstärker (OPV) IC1A sowohl über eine Mitkopplung durch R23, als auch über eine Gegenkopplung durch R27 und VR2 betrieben. Der dadurch realisierte Negativ-Impedanz-Konverter läd bzw. entläd den Kondensator C3 in Abhängigkeit des Potentiometers VR2. Das daraus entstehende Clock-Signal wird über einen Buffer (IC1D) geführt und unter anderem über den Klinkenausgang J9 nach außen zur Verfügung gestellt. Der Klinkeneingang J10 ist zusätzlich in der Lage das interne Clock-Signal durch ein extern angelegtes zu übersteuern.\\
Im dritten Abschnitt werden den verschieden Zuständen ihre jeweiligen Spannungen zugewiesen. Um das zu erreichen wird jedes Zustandssignal über ein separates Potentiometer gegen Masse geführt. Der Abgriff wird anschließend durch jeweilige Dioden vor rückfließenden Strömen geschützt und zusammengeführt. Um das Spannungssignal nun zu limitieren, wurden zwei Spannungsteiler R1 und R3 für 0 - 5 Volt sowie R1 und R4 für 0 - 2.5 Volt eingesetzt. Um Bauteiltoleranzen kompensieren zu können wurden zusätzlich zwei Trimmer R5 und R6 verbaut. Zwischen den Spannungsbereichen kann über den Schalter J2 gewechselt werden (default: 0 - 5 Volt). Danach kommt wieder ein Buffer (IC1C) und in Reihe dazu der Widerstand R2. Dieser Widerstand sorgt dafür, dass im Falle eines Kurzschlusses der Fehlerstrom begrenzt und dadurch kein Schaden in der Schaltung entsteht. Der so entstandene CV kann über den Klinkenausgang J5 abgegriffen werden.\\
Der vierte Bereich des Schaltplans (vgl. Abbildung \ref{fig:In_Bereiche_unterteilter_Schaltplan_des_Sequenzers}) ermöglicht das Ablesen des aktiven Zustandes über die Frontplatte. Dafür wird für jeden möglichen Zustand eine LED (D6 - D10) angeschaltet, welche nach außen geführt ist. Die LEDs werden durch eine Emitterschaltung eines 2N3904 NPN Transistor angesteuert. Somit werden die Spannungssignale entlastet und möglichem Schaden vorgebeugt.\\
Die Funktionalität des Gate-Ausgangs wird in Bereich fünf umgesetzt. Die verschiedenen Stufenspannungen des Dekadenzählers aus Bereich eins werden jeweils über einen Kippschalter sowie eine Diode geführt und danach vereint. Die Schalter ermöglichen ein manuelles Zu- bzw. Wegschalten der einzelnen Stufe im resultierenden Gate-Signal. Die Dioden verhindern, wie auch bei der Umsetzung des CV, ein rückfließen der Ströme in die anderen Stufensignale. Nach der Zusammenführung der Signale folgt der Widerstand R20, sowie das über eine Diode begrenzte Clock-Signal. Das Clock-Signal sorgt dafür das der Gate in jedem Zyklus für die halbe Zeit auf 0 Volt gesetzt wird. Durch den Widerstand R20 wird einem Kurzschluss in diesem Pfad vorgebeugt. Der Widerstand R19 verhindert einen undefinierten Zustand sobald ein Stufe durch einen Kippschalter weggeschaltet wird. Allerdings bilden R19 und R20 einen ungewollten Spannungsteiler, der aus den gewünschten +12 Volt +6 Volt macht. Aus diesem Grund wurde ein weiterer OPV als einfacher Komparator verbaut. Die Widerstände R17 und R18 sorgen für eine Vergleichsspannung von 3.8 Volt am nicht-invertierenden Eingang, weshalb bei den anliegenden +6 Volt problemlos durchgeschaltet wird. Der negative Teil der Spannung wird anschließend durch die Diode D17 sowie den Pulldown-Widerstand R21 unterbunden. Um der resultierenden hohen Impedanz sowie der begrenzt möglichen Stromentnahme der aktuellen Schaltung entgegenzuwirken, wurde der Ausgang mit einem BC547 NPN Transistor versehen. Dieser wurde als Kollektorschaltung implementiert sowie, um Kurzschlüsse zu vermeiden, mit einem weiteren Widerstand R32 verbaut. Der Gate kann somit über den Klinkenausgang J14 von außen abgegriffen werden.\\
Der letzte Bereich ist zuständig für die Spannungsversorgung des gesamten Moduls. Das Netzteil (vgl. Kapitel \ref{ch:Netzteil}) versorgt den Sequenzer mit \textpm 12 Volt durch den Euro-Rack-Stecker. Um Verpolung vorzubeugen, wurden zwei Dioden D21 und D22 verbaut. Anschließend werden die beiden Spannungen mit den Kondensatoren C6 und C7 gegen Masse gepuffert. Weitere Pufferkondensatoren wurden in der Versorgung der OPV als auch in der Versorgung des Dekadenzählers vorgesehen. (Quellen: EricaSynt:Sequenzer, elektronik-kompendium.de(Emitterschaltung, Kollektorschaltung))

\section{Platine}
bla bla bla

\section{Mechanischer Aufbau}
bla bla bla

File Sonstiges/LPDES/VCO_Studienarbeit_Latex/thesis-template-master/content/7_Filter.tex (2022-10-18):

\chapter{Filter}
\label{ch:concept}
\section{Allgemeines}

\section{Schaltplan}
bla bla bla

\section{Platine}
bla bla bla

\section{Mechanischer Aufbau}
bla bla bla

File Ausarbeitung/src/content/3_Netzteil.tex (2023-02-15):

\chapter{Netzteil}
\label{ch:Netzteil}

\section{Allgemeines}
Um eine fehlerfreie Funktion aller weiteren Module zu gewährleisten, ist es wichtig, dass eine geeignete Spannungsversorgung bereitgestellt wird. 
Insbesondere für die Opamp-Schaltungen ist es wichtig, dass eine störfreie symmetrische Spannung bereitgestellt wird. 
Im Bereich der modularen Synthesizer wird hier typischerweise eine Spannung von +/- 12 V benötigt. Diese Spannungspegel werden durch eine geignete Beschaltung von Dioden und Kondensatoren generiert, welche in Abschnitt \ref{sec:Netzteil_Schaltplan} bzw. \ref{sec:Netzteil_Umsetzung} bildlich erläutert werden. Hierbei wird die für modulare Synthesizer typischerweise eingesetzte Wannenstecker-Belegung verwendet. Diese wird entsprechend in allen weiteren Modulen eingesetzt!

\newpage

\FloatBarrier
\section{Schaltplan}
\label{sec:Netzteil_Schaltplan}

\begin{figure}[h]
\centering
\setlength{\fboxsep}{1pt} %Abstand der Linien zur Abbildung
\setlength{\fboxrule}{1pt} %Dicke der Linie
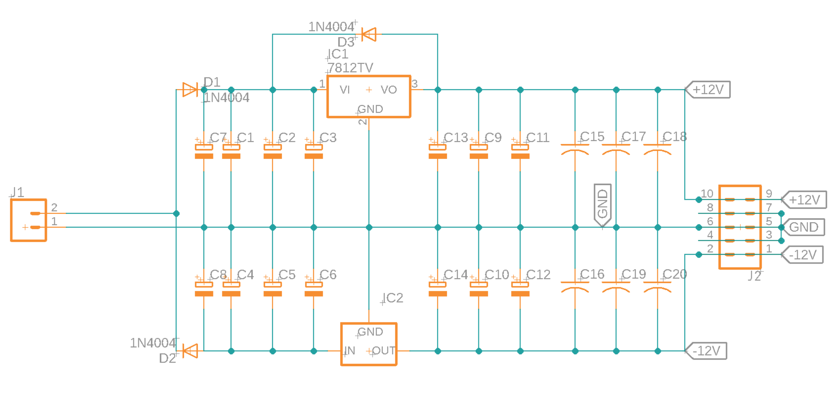
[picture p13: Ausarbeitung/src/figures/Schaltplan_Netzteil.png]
\fbox{}
\caption{Fusion360 Schaltplan des Netzteils}
\label{fig:Netzteil_Schaltplan}
\end{figure}
\FloatBarrier

\FloatBarrier
\section{Umsetzung}
\label{sec:Netzteil_Umsetzung}

\begin{figure}[h]
\setlength{\fboxsep}{1pt} %Abstand der Linien zur Abbildung
\setlength{\fboxrule}{1pt} %Dicke der Linie
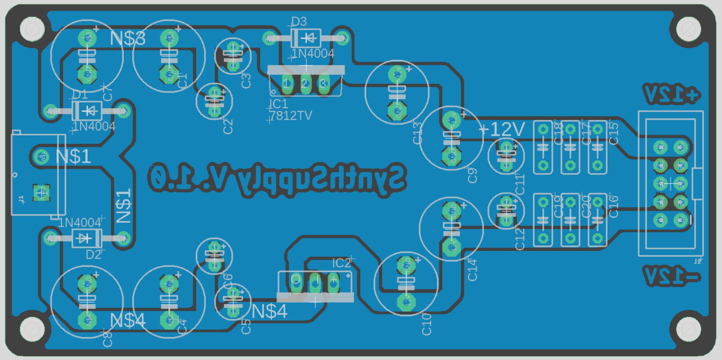
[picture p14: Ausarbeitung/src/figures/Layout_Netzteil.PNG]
\fbox{}
\caption{Fusion360 Schaltplan des Netzteils}
\label{fig:Netzteil_Layout}
\end{figure}
\FloatBarrier

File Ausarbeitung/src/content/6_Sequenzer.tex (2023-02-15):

\chapter{Sequenzer}
\label{ch:Sequenzer}
\section{Allgemeines}
Bei dieser Umsetzung eines Sequenzers wurde sich für maximal fünf alternierende Spannungspegel entschieden. In der Literatur ist diese Unterart als 5-Step-Sequencer bekannt, welcher wegen seiner markanten Charakteristik zum Beispiel auch im bekannten 'Buchla Easel Command ECM-X7' Synthesizer verbaut ist. Über zwei in der Handebene verbaute Kippschalter kann alternativ zwischen 3- bzw. 4-Stufen-Betrieb gewählt werden. Welcher Schritt aktuell aktiv ist wird durch Status-LEDs in der Frontplatte angezeigt.\\
Als Spannungsversorgung erhält der Sequenzer \textpm 12 Volt durch das verbaute Netzteil. Optional kann ein externes Clock-Signal, beispielsweise von einem LFO (vgl. Kapitel \ref{ch:LFO}), angeschlossen werden. Der eigene Takt wird dadurch überbrückt, wodurch das Modul flexibel eingesetzt werden kann. Des Weiteren kann die Sequenz durch ein externes Signal zurückgesetzt werden. Dadurch wird automatisch wieder bei der ersten Stufe der Sequenz begonnen, wodurch dem Nutzer weiterer musikalischer Freiraum freigeräumt wird.\\
Das Sequenzer-Modul verfügt über drei abgreifbare Ausgangssignale. Ein Clock-Signal, welches über ein Potentiometer in der Handebene parametrisiert werden kann, gibt den internen Takt des Moduls vor, und kann von außerhalb abgegriffen werden. Dessen Spannung toggelt dabei zwischen -12 und +12 Volt. Die Control Voltage (CV) wird zumeist dem VCO (vgl. Kapitel \ref{ch:VCO}) zur weiteren Verarbeitung überreicht. Dabei handelt es sich um eine alternierende Spannungsfolge, welche zwischen 0 und 5 Volt schwanken kann. Die einzelnen Spannungspegel der bis zu fünf Stufen werden durch ein jeweiliges Potentiometer in der Handebene eingestellt. Das dritte Ausgangssignal des Sequenzers bildet der Gate. Ähnlich dem CV wird eine alternierende Spannungsfolge von bis zu fünf Stufen ausgegeben, wobei eine Stufe in zwei Abschnitte geteilt wird. Der erste Abschnitt beträgt, abhängig dem jeweiligen Kippschalter in der Handebene, entweder +12 oder 0 Volt. Der zweite Abschnitt führt immer 0 Volt. Der Gate verhält sich somit ähnlich dem Clock-Signal. Er führt jedoch niemals eine Negative Spannung und seine Stufen sind manuell zuschaltbar. In der Regel wird der Gate als Eingangssignal für den ADSR hergenommen.

\newpage
\section{Schaltplan}
Der Schaltplan des Sequenzers lässt sich, wie in Abbildung \ref{fig:Schaltplan_des_Sequenzers} gezeigt, in sechs Bereiche unterteilen. Der Bereich eins ist zuständig für das Durchschalten der Zustände.
Die wesentliche Komponente ist dabei das Bauteil U1G1. Es handelt sich dabei um einen CD4017 Dekadenzähler, der durch das Toggeln des Clock-Signals die verschiedenen Zustände durchschaltet. Der Sequenzer ist für eine Sequenz von maximal 5 Stufen ausgelegt. Durch die beiden Schalter J11 und J12 kann diese jedoch auf 4 bzw. 3 Stufen reduziert werden, was sich an der Rückführung der jeweiligen Stufen auf den RESET-Pin erkennen lässt. Durch den RESET-Eingang J13 lässt sich zusätzlich ein externes Signal einbinden, was einen Fremd-RESET ermöglicht.\\
Der zweite Bereich des Schaltplans kümmert sich um das Clock-Signal. Dafür wird der Operationsverstärker (OPV) IC1A sowohl über eine Mitkopplung durch R23, als auch über eine Gegenkopplung durch R27 und VR2 betrieben. Der dadurch realisierte Negativ-Impedanz-Konverter läd bzw. entläd den Kondensator C3 in Abhängigkeit des Potentiometers VR2. Das daraus entstehende Clock-Signal wird über einen Buffer (IC1D) geführt und unter anderem über den Klinkenausgang J9 nach außen zur Verfügung gestellt. Der Klinkeneingang J10 ist zusätzlich in der Lage das interne Clock-Signal durch ein extern angelegtes zu übersteuern.\\
Im dritten Abschnitt werden den verschieden Zuständen ihre jeweiligen Spannungen zugewiesen. Um das zu erreichen wird jedes Zustandssignal über ein separates Potentiometer gegen Masse geführt. Der Abgriff wird anschließend durch jeweilige Dioden vor rückfließenden Strömen geschützt und zusammengeführt. Um das Spannungssignal nun zu limitieren, wurden zwei Spannungsteiler R1 und R3 für 0 - 5 Volt sowie R1 und R4 für 0 - 2.5 Volt eingesetzt. Um Bauteiltoleranzen kompensieren zu können wurden zusätzlich zwei Trimmer R5 und R6 verbaut. Zwischen den Spannungsbereichen kann über den Schalter J2 gewechselt werden (default: 0 - 5 Volt). Danach kommt wieder ein Buffer (IC1C) und in Reihe dazu der Widerstand R2. Dieser Widerstand sorgt dafür, dass im Falle eines Kurzschlusses der Fehlerstrom begrenzt und dadurch kein Schaden in der Schaltung entsteht. Der so entstandene CV kann über den Klinkenausgang J5 abgegriffen werden.\\
Der vierte Bereich des Schaltplans (vgl. Abbildung \ref{fig:Schaltplan_des_Sequenzers}) ermöglicht das Ablesen des aktiven Zustandes über die Frontplatte. 
Dafür wird für jeden möglichen Zustand eine LED (D6 - D10) angeschaltet, welche nach außen geführt ist. 
Die LEDs werden durch eine Emitterschaltung eines 2N3904 NPN Transistor angesteuert. Somit werden die Spannungssignale entlastet und möglichem Schaden vorgebeugt.\\
Die Funktionalität des Gate-Ausgangs wird in Bereich fünf umgesetzt. Die verschiedenen Stufenspannungen des Dekadenzählers aus Bereich eins werden jeweils über einen Kippschalter sowie eine Diode geführt und danach vereint. Die Schalter ermöglichen ein manuelles Zu- bzw. Wegschalten der einzelnen Stufe im resultierenden Gate-Signal. Die Dioden verhindern, wie auch bei der Umsetzung des CV, ein rückfließen der Ströme in die anderen Stufensignale. Nach der Zusammenführung der Signale folgt der Widerstand R20, sowie das über eine Diode begrenzte Clock-Signal. Das Clock-Signal sorgt dafür das der Gate in jedem Zyklus für die halbe Zeit auf 0 Volt gesetzt wird. Durch den Widerstand R20 wird einem Kurzschluss in diesem Pfad vorgebeugt. Der Widerstand R19 verhindert einen undefinierten Zustand sobald ein Stufe durch einen Kippschalter weggeschaltet wird. Allerdings bilden R19 und R20 einen ungewollten Spannungsteiler, der aus den gewünschten +12 Volt +6 Volt macht. Aus diesem Grund wurde ein weiterer OPV als einfacher Komparator verbaut. Die Widerstände R17 und R18 sorgen für eine Vergleichsspannung von 3.8 Volt am nicht-invertierenden Eingang, weshalb bei den anliegenden +6 Volt problemlos durchgeschaltet wird. Der negative Teil der Spannung wird anschließend durch die Diode D17 sowie den Pulldown-Widerstand R21 unterbunden. Um der resultierenden hohen Impedanz sowie der begrenzt möglichen Stromentnahme der aktuellen Schaltung entgegenzuwirken, wurde der Ausgang mit einem BC547 NPN Transistor versehen. Dieser wurde als Kollektorschaltung implementiert sowie, um Kurzschlüsse zu vermeiden, mit einem weiteren Widerstand R32 verbaut. Der Gate kann somit über den Klinkenausgang J14 von außen abgegriffen werden.\\
Der letzte Bereich ist zuständig für die Spannungsversorgung des gesamten Moduls. Das Netzteil (vgl. Kapitel \ref{ch:Netzteil}) versorgt den Sequenzer mit \textpm 12 Volt durch den Euro-Rack-Stecker. Um Verpolung vorzubeugen, wurden zwei Dioden D21 und D22 verbaut. Anschließend werden die beiden Spannungen mit den Kondensatoren C6 und C7 gegen Masse gepuffert. Weitere Pufferkondensatoren wurden in der Versorgung der OPV als auch in der Versorgung des Dekadenzählers vorgesehen \cite{seq_manual}.

\newpage	%Seite leer beenden und Umbruch

%\begin{figure}[h]
%	\centering
%	\includepdf[angle=270, clip, trim=1.7cm 0.85cm 0.8cm 1.65cm, scale=0.8] {figures/Schaltplan_Sequenzer_Christoph_Kirschner_unterteilt.pdf}
%	\caption{Schaltplan der Sequenzer-Platine}
%	\label{fig:Schaltplan_des_Sequenzers}
%\end{figure}
%\FloatBarrier
%\newpage	%Seite leer beenden und Umbruch

\begin{figure}[h]
	\centering
	\setlength{\fboxsep}{1pt} %Abstand der Linien zur Abbildung
	\setlength{\fboxrule}{1pt} %Dicke der Linie
	\fbox{\includegraphics[angle=270, clip, trim=1.25cm 1.48cm 1.20cm 0.95cm, scale=0.8, width=1\textwidth] {figures/Schaltplan_Sequenzer_Christoph_Kirschner_unterteilt.pdf}}
	\caption{Schaltplan der Sequenzer-Platine}
	\label{fig:Schaltplan_des_Sequenzers}
\end{figure}
\FloatBarrier
\newpage	%Seite leer beenden und Umbruch

\section{Platine}
\begin{figure}[h]
	\centering
	\setlength{\fboxsep}{1pt} %Abstand der Linien zur Abbildung
	\setlength{\fboxrule}{1pt} %Dicke der Linie
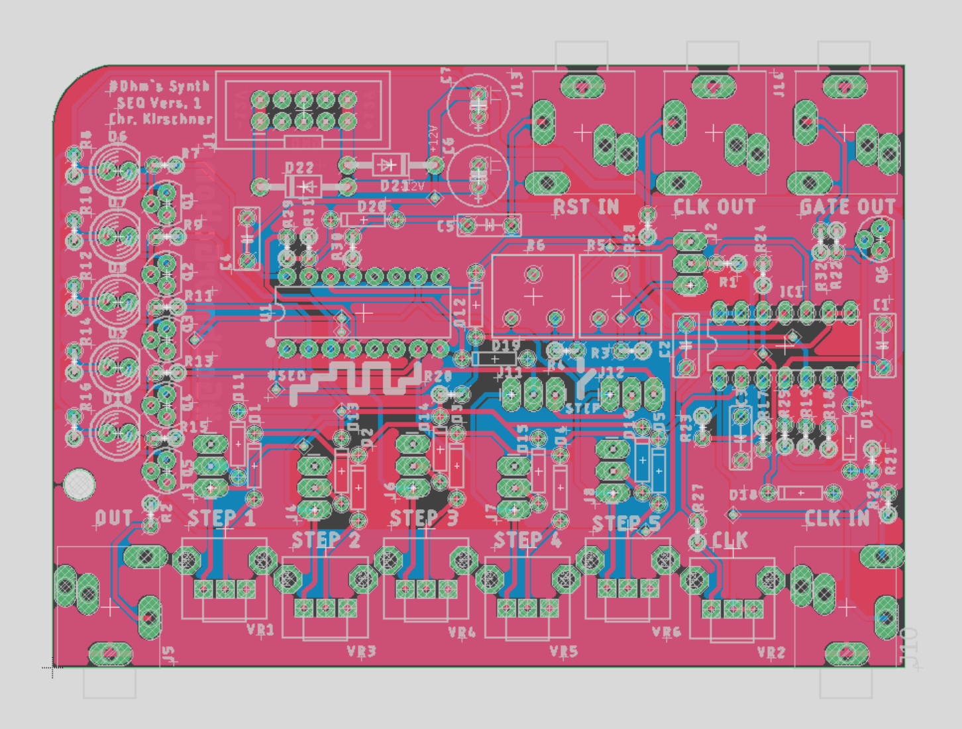
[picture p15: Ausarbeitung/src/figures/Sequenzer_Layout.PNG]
	\fbox{}
	\caption{Ausschnitt des Sequenzer-Platinen-Layouts aus Fusion360}
	\label{fig:PCB_SEQ}
\end{figure}
\FloatBarrier

\section{Mechanischer Aufbau}
\begin{figure}[h]
	\centering
	\setlength{\fboxsep}{1pt} %Abstand der Linien zur Abbildung
	\setlength{\fboxrule}{1pt} %Dicke der Linie
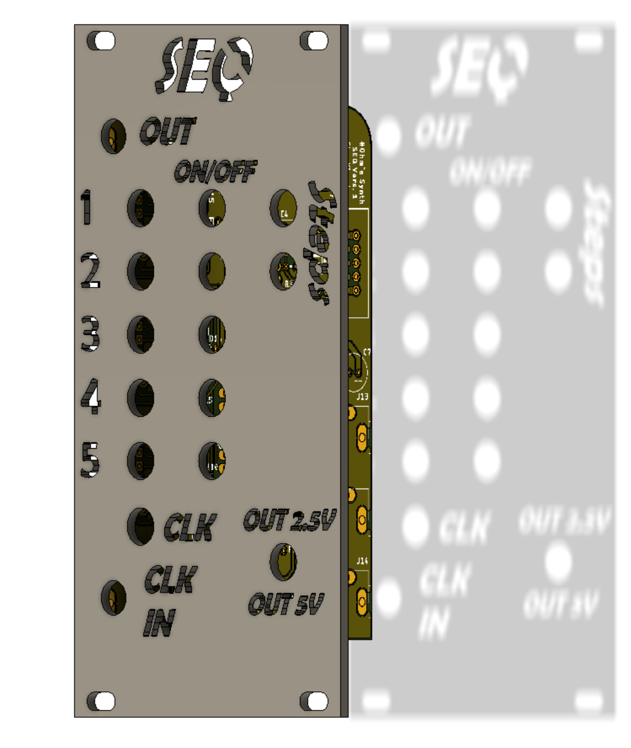
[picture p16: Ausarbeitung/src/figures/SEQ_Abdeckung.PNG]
	\fbox{}
	\caption{3D-Darstellung der Sequenzer-Frontplatte}
	\label{fig:Frontplatte_SEQ}
\end{figure}
\FloatBarrier

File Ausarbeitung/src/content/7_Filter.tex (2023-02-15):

\chapter{Filter}
\label{ch:concept}
\section{Allgemeines}
Neben Oszillatoren wie VCO und LFO stellen der Filter ein wichtiges Element der Klangsynthese dar.
In diesem Kapitel wird eine Realisierungsform eines spanungsgesteuerten Filters VCF vorgestellt. 
Grundsätzlich kann ein Filter bestimmte Frequenzanteile eines Signals ungehindert passieren lassen, während andere Anteile
abgeschwächt werden.
Man unterscheidet zwischen dem sogennanten Durchlassbereich, Übergansbereich und Sperrbereich.

\begin{figure}[h]
	\centering
	\setlength{\fboxsep}{1pt} %Abstand der Linien zur Abbildung
	\setlength{\fboxrule}{1pt} %Dicke der Linie
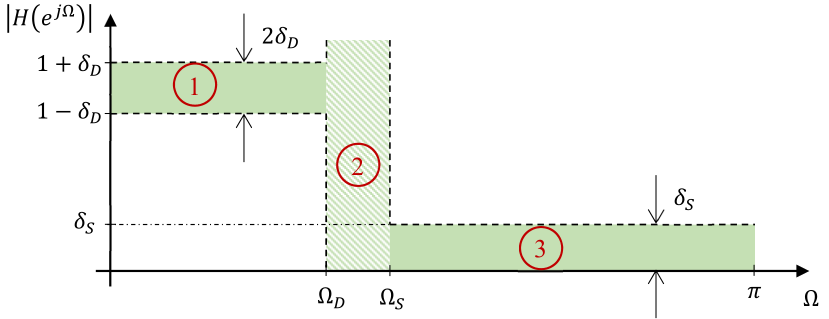
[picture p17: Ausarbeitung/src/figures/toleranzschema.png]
	\fbox{}
	\caption{Frequenzgang eines digitalen Filters}
	\label{fig:toleranzschema}
\end{figure}
Abbildung \ref{fig:toleranzschema} zeigt ein schematisches Schaubild für einen digitalen Filterentwurf, der hier analog adaptiert werden kann.

\textbf{Durchlassbereich:}\\
Der Durchlassbereich wird bis zur Grenzfrequenz $f_{3dB}$ (engl. Cut-Off Frequency) definiert.
Beim VCF kann diese Grenzfrequenz mit einer Steuerspannung und einem Potentiometer verändert werden. \\

\textbf{Übergangsbereich:}\\
Im Übergansbereich will man grundsätzlich meist eines steile Flanke realisieren. Die Flankensteilheit wird normalerweise in dB/Dec bzw. dB/Oct angegeben.
Steile Flanken können ohne weitere tiefergehende Entwurfsmethoden (z.B Cauer, Tschebychef o.Ä) nur mit einer höheren Filterordnung realisiert werden.
Im Übergangsbereich ist außer der Flankensteilheit noch das Resonanzverhalten interessant. Um die Resonanzfrequenz $f_r$ werden Frequenzanteile um einen Faktor Q (Güte) erhöht.  
Es gilt: 
\begin{equation}  \label{eq:1}
  |H(f_r)| = H_0 \cdot Q
\end{equation}
Für Audiofilter hat das Resonanzverhalten eine große Bedeutung, da dieser Fall besonders voll und interessant klingt.\\
\\
\textbf{Sperrbereich:}\\
Frequenzanteile, die sich im Sperrbereich befinden werden werden dann je nach Frequenzwert mit der entsprechenden Flankensteilheit abgeschwächt.

\section{Schaltplan}
Das Eingangssignal geht über die Audiobuchse J3 über einen Eingangskondensator C2, der den DC-Offset des Signals herausfiltert in den Eingang des OPVs.
Der OPV hat eine Leerlaufverstärkung im Durchlassbereich von $-\frac{R2}{R1+R7} = 0.3 = 20 log_{10}(0.3) = -10.456 dB$. Dieser Wert wurde so gewählt,
um bei starker Resonanz keine Eingänge von nachfolgenden Modulen zu zerstören. Das eigentliche Tiefpass-Verhalten wird durch die Kondensatoren C3 und C4, sowie die Widerstände R3 und R4 realisiert. 
Die Grenzfrequenz kann über den einen JFET justiert werden. Dieser fungiert als spanungsgesteuerter Widerstand. Der Drain des JFET liegt Potenzialmäßig zwischen C3 und C4 bzw. R3 und R4 und Ground.
Somit kann das Potenzial dieses Knotens Nieder- bis Hochohmig Richtung Ground gezogen werden. Bei einer Niederhomigen Verbindung (JFET durchgeschalten mit $R_{on} = 100\Omega$) ist die Grenzfrequenz maximal.\\
Mit dem Potentiometer VR2 kann zusätzlich das Resonanzverhalten eingestellt werden. Je niederhomiger der Widerstandswert, desto höher die Resonanzüberhöhung.
Somit muss der JFET in einem sinnvollen Bereich angesteuert werden, indem er auch als Widerstand fungiert. Laut Datenblatt fängt der J113 ab -3V $U_{GS}$ langsam das Leiten an und ist bei -0.5V voll durchgeschalten.
Tests mit dem Steckbrett haben gezeigt, dass der JFET erst bei -1.3V das Leiten anfängt. Es muss also eine Steuerspannung in einem Bereich von +- 4V auf einen Spannungsbereich von -0.5V bis -1.3V abgebildet werden.
Das geschieht mit der Verstärkerschaltung um den 2. OPV. Da das genaue Dimensionieren hier Formelmäßig viel zu komplex wäre, wurde ein Trimmpotentiometer R10 eingesetzt, um den Verstärkungsfaktor des OPVs einzustellen
und somit die Steuerspannung CV auf den Spannungsbereich des JFETs abzustimmen.
Zuätzlich werden die Steuerspannungen CV1 und CV2 noch über R15 über R16 mit einem Offset VR1 gemischt.
Ist keine Steuerspannung angeschlossen kann über VR1 über den oben genannten Mechanismus die Grenzfrequenz des Filters eingestellt werden. \\
\\
Insgesamt ergiebt sich mit der Bauteildimmensionierung ein Tiefpassfilter 2. Ordnung mit einer Flankensteilheit von -20dB/Dec im Sperrbereich. Die Grenzfrequenz kann über das Potentiometer VR1 oder den CV-Eingang in einem Bereich von 100Hz - 6kHz eingestellt werden.

\begin{figure}[h]
	\centering
	\setlength{\fboxsep}{1pt} %Abstand der Linien zur Abbildung
	\setlength{\fboxrule}{1pt} %Dicke der Linie
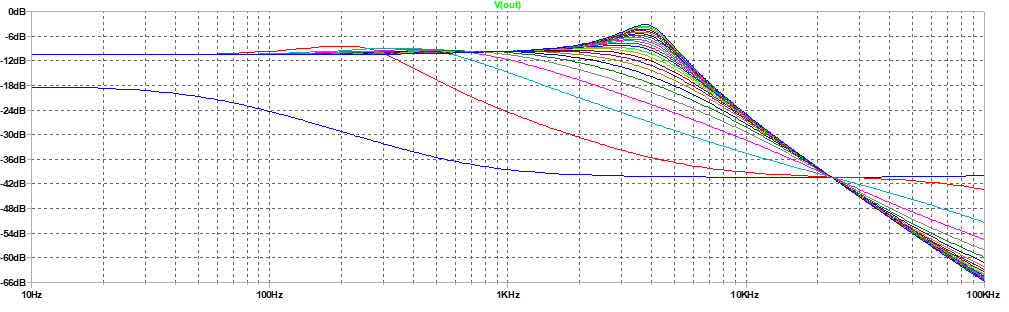
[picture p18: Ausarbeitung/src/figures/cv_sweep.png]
	\fbox{}
	\caption{Frequenzgang des Filters bei CV-Sweep CV1 -4V bis +4V}
	\label{fig:toleranzschema}
\end{figure}

\begin{figure}[h]
	\centering
	\setlength{\fboxsep}{1pt} %Abstand der Linien zur Abbildung
	\setlength{\fboxrule}{1pt} %Dicke der Linie
	\fbox{}
	\caption{Frequenzgang des Filters bei Potentiometer-Sweep VR1 0 bis 100k$\Omega$}
	\label{fig:toleranzschema}
\end{figure}

Hier ist auch gleich eine Schwäche des Filters sichtbar. Trotz des Maximalen Potentiometer-Werts von VR2 ("Resonanz-Poti") geht der Frequenzgang
zwischen 3kHz und 4kHz in eine Resonanz (ca. 6dB Überhöhung $\rightarrow Q = 2$). Die Einstellungen Resonanz und Grenzfrequenz können also nicht komplett unabhängig von einander eingestellt werden.

\begin{figure}[h]
	\centering
	\setlength{\fboxsep}{1pt} %Abstand der Linien zur Abbildung
	\setlength{\fboxrule}{1pt} %Dicke der Linie
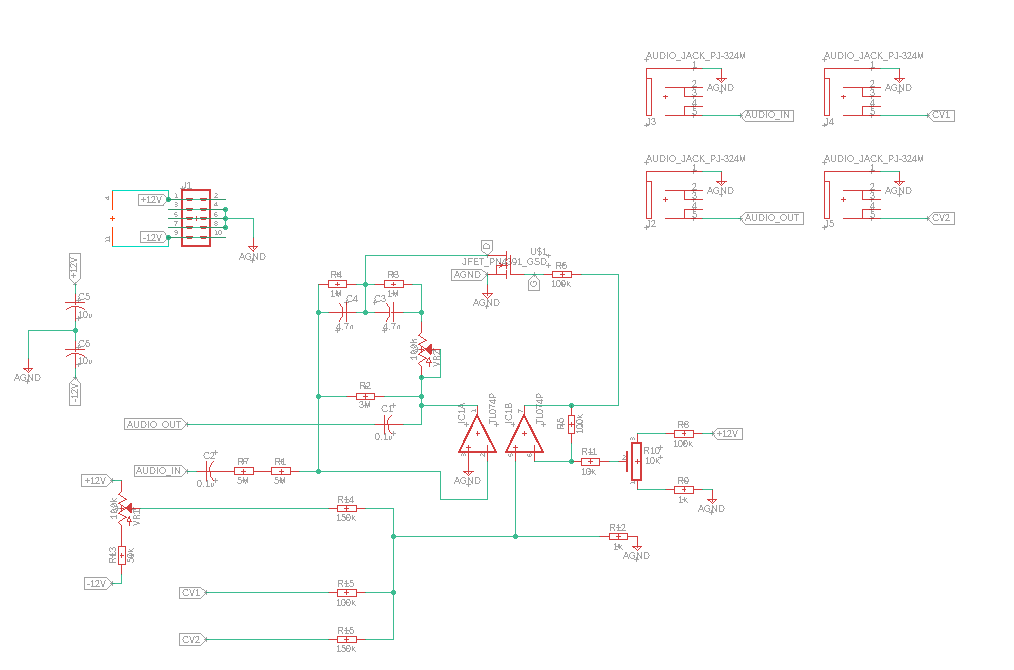
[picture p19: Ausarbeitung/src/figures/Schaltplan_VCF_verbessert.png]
	\fbox{}
	\caption{Schaltplan des VCF}
\end{figure}
\newpage
\section{Platine}
\begin{figure}[h]
	\centering
	\setlength{\fboxsep}{1pt} %Abstand der Linien zur Abbildung
	\setlength{\fboxrule}{1pt} %Dicke der Linie
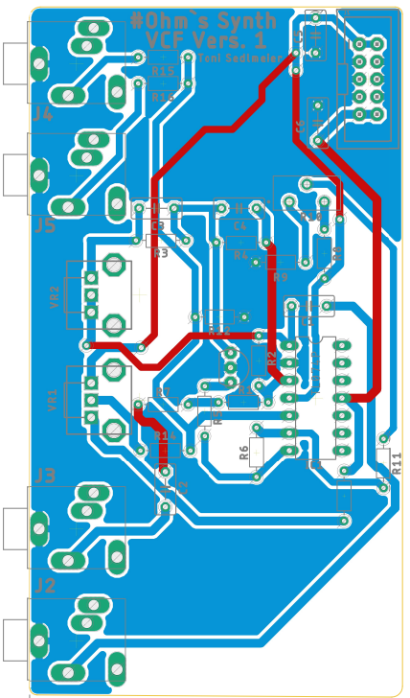
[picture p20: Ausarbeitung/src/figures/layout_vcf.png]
	\fbox{}
	\caption{Platinen-Layout des VCF}
\end{figure}

\section{Mechanischer Aufbau}
\begin{figure}[h]
	\centering
	\setlength{\fboxsep}{1pt} %Abstand der Linien zur Abbildung
	\setlength{\fboxrule}{1pt} %Dicke der Linie
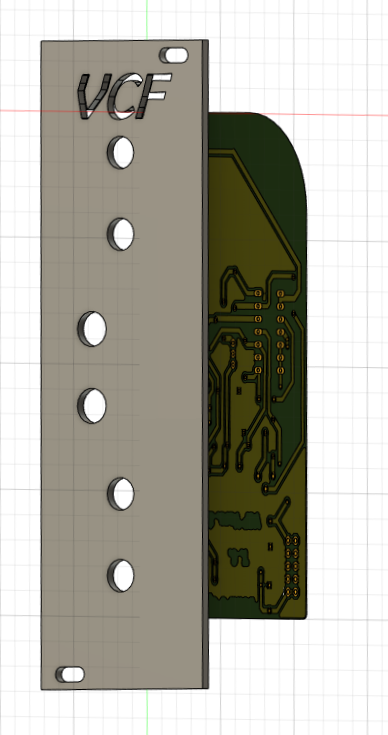
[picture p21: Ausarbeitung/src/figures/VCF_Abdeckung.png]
	\fbox{}
	\caption{3D-Darstellung der VCF-Frontplatte}
\end{figure}

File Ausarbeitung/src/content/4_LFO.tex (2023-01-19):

\chapter{LFO}
\label{ch:LFO}

\section{Allgemeines}
Wie bereits in Kapitel \label{ch:concept} beschrieben, wird der LFO genutzt, um niederfrequente Signale zu erzeugen. 
Diese Signale werden typischerweise zur Steuerung von nachgelagerten Modulen, wie etwa dem LFO (siehe Kapitel \ref{ch:VCO}), verwendet.
Hierdurch kann beispielsweise die Frequenz des VCO angepasst werden. 
Neben der Frequenz, die der LFO ausgibt, ist auch die entsprechende Signalform für den Klang entscheidend. Hier sind beispielsweise Signalformen, wie Dreieck oder Rechteck möglich.

\section{Schaltplan}

Im Folgenden wird näher auf den Schaltplan des LFO eingegangen, welcher in Abbildung \ref{fig:LFO_Stromlaufplan} zu sehen ist \cite{lfo_manual}. 
Ein Bauteil von zentraler Bedeutung ist hierbei der Vierfach-Operationsverstärker TL074P. In der gezeigten Schaltung wird dieser als Integrator, Schmitt Trigger, Buffer und LED-Treiber verwendet.
Die grundlegende Funktionsweise dieser Funktionsgruppen wird in Abschnitt \ref{ch:VCO} erläutert. Aus diesem Grund wird nicht weiter auf die Funktionsweise eines Oszillators eingegangen.

\newpage
\begin{figure}[h]
\centering
\includepdf[angle=270, clip, trim=1cm 0.8cm 0.8cm 0.8cm, scale=0.8] {figures/Schaltplan_LFO_Kirschner_08_12_22.pdf}
\caption{Fusion360 Schaltplan des LFO}
\label{fig:LFO_Stromlaufplan}
\end{figure}
\FloatBarrier
 
\newpage

\section{Platine}

In Abbildung \ref{fig:PCB_LFO_bottom} ist die untere Lage der Leiterplatte in blau dargestellt. 
Beim Erstellen der Platine wurde der Fokus auf die Produzierbarkeit mittels CNC-Fräße gelegt. 
Hierbei ist die Lagenzahl der Platine auf maximal  zwei Lagen begrenzt, wobei nur einlagiges Platinenrohmaterial zur Verfügung stand. 
Um diese Limitation zu umgehen wurde versucht alle Leiterbahnen auf eine Platinen-Lage zu entflechten. 
Da manche Leiterbahnen nicht auf der Unterseite platziert werden konnten, wurden für die restlichen Bahnen auf der Oberseite Verbindungsdrähte verwendet. 
Hierfür wurden jeweils Via-Verbindungen mit größerem Bohrungsdurchmesser vorgesehen.
Der Vorteil dieser Methode ist, dass die Platine ohne Mehraufwand auch professionell produziert werden kann. 
Die beschriebene Vorgehensweise wurde auch bei den übrigen Platinen dieser Projektarbeit angewendet.

\begin{figure}[h]
	\centering
	\setlength{\fboxsep}{1pt} %Abstand der Linien zur Abbildung
	\setlength{\fboxrule}{1pt} %Dicke der Linie
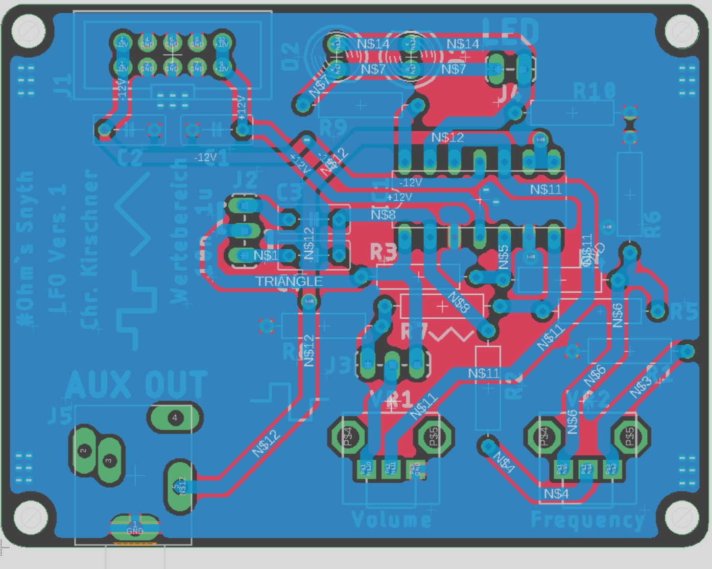
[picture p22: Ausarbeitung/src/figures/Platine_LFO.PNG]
	\fbox{}
	\caption{Ausschnitt des LFO-Platinen-Layouts aus Fusion360 (Unterseite)}
	\label{fig:PCB_LFO_bottom}
\end{figure}
\FloatBarrier

\newpage

Wie bereits beschrieben, wurde die Platine mit einer Platinenfräße angefertigt. Hierbei wurde die CNC-Fräße \grqq{}Othermachine\grqq{} von \grqq{}Bantam Tools\grqq{} verwendet. In Abbildung \ref{fig:bantam_tools_lfo} is ein Ausschnitt aus der Steuer-Software von \grqq{}Bantam Tools\grqq{} gezeigt. Mit Hilfe dieser Software können Gerber-Dateien oder brd-Dateien (Eagle) importiert werden und Fräßabläufe erzeugt werden.

\begin{figure}[h]
	\centering
	\setlength{\fboxsep}{1pt} %Abstand der Linien zur Abbildung
	\setlength{\fboxrule}{1pt} %Dicke der Linie
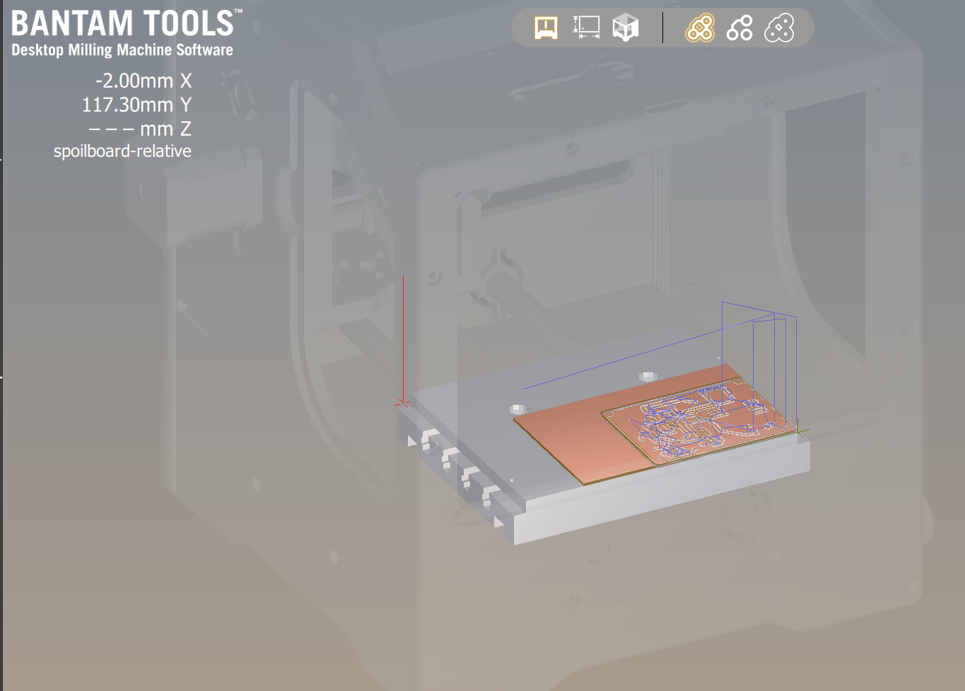
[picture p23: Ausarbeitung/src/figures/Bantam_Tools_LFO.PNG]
	\fbox{}
	\caption{3D-Ansicht der LFO-Platine in Bantam-Tools-Software (Platinen-Fräße) \cite{bantam}}
	\label{fig:bantam_tools_lfo}
\end{figure}
\FloatBarrier

\newpage

\section{Mechanischer Aufbau}
Um die LFO-Platine in einem Rack-System befestigen zu können, ist es nötig eine entsprechende Abdeckplatte mit Montagelöchern an der Platine anzubringen. 
Die Befestigung der Frontplatte an der LFO-Platine wird über das Gewinde an der AUX-Buchse realisiert. Dies hat sich bei lediglich einer Buchse als nicht ausreichend herausgestellt. Aus diesem Grund wurde die Platine zusätzlich mit Epoxit-Kleber an der Abdeckplatte fixiert.

\begin{figure}[h]
	\centering
	\setlength{\fboxsep}{1pt} %Abstand der Linien zur Abbildung
	\setlength{\fboxrule}{1pt} %Dicke der Linie
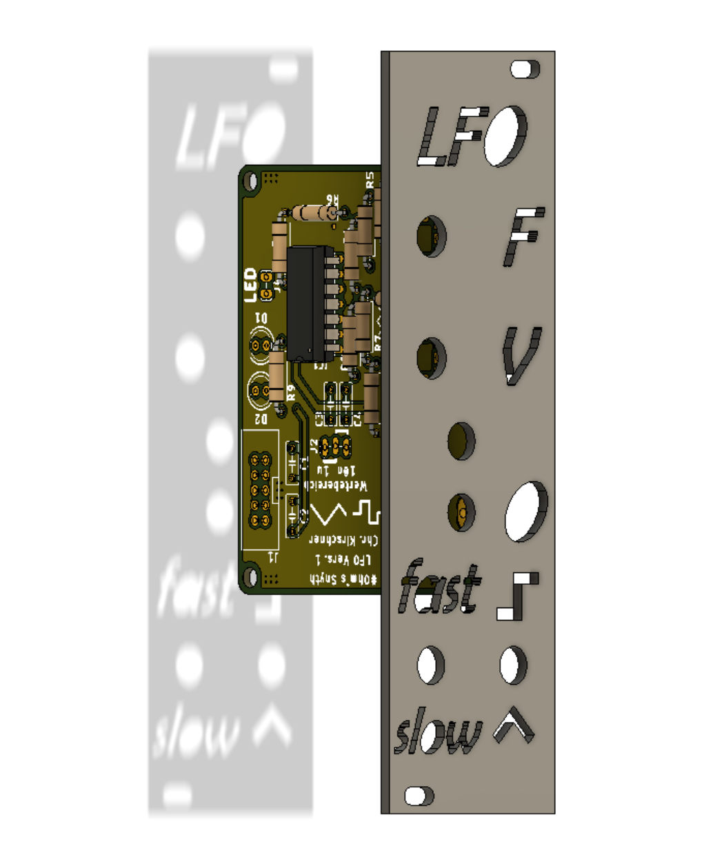
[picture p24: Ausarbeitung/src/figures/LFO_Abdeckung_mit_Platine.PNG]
	\fbox{}
	\caption{3D-Darstellung der LFO-Platine mit Frontplatte}
	\label{fig:Frontplatte_LFO}
\end{figure}
\FloatBarrier

Wie in \ref{fig:Frontplatte_LFO} abgebildet, wurden die Beschriftungen als Ausschnitte in der Frontplatte angebracht. Hierdurch kann die Frontplatte mit einem Lasercutter kostengünstig produziert werden und es ist somit keine weiter Nachbearbeitung der Frontplatte nötig.

Um bereits vor dem Lasercutten der Frontplatte die grundsätzliche Tauglichkeit der Konstruktion erproben zu können, wurde mittels eines 3D-Drucker die Frontplatte gedruckt. Hierbei wurde ein \grqq{}Prusa Mini\grqq{} und die dazugehörende \grqq{}Prusa Sliver\grqq{}-Software verwendet. Ein Ausschnitt dieser Software ist in Abbildung \ref{fig:3DDruck_LFO} zusehen.

\begin{figure}[h]
	\centering
	\setlength{\fboxsep}{1pt} %Abstand der Linien zur Abbildung
	\setlength{\fboxrule}{1pt} %Dicke der Linie
	\fbox{}
	\caption{Ausschnitt aus \grqq{}Prusa Slicer\grqq{} beim Vorbereiten des 3D-Drucks für die LFO-Platine \cite{prusa}}
	\label{fig:3DDruck_LFO}
\end{figure}
\FloatBarrier

Die in diesem Abschnitt aufgezeigte Vorgehensweise beim Prototypen der Abdeckplatte ist exemplarisch für alle Module dieser Projektarbeit. Aus diesem Grund wird in den folgenden Kapiteln nicht näher darauf eingegangen.

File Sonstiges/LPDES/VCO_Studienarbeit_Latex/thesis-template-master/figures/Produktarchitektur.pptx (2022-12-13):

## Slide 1

Funktionsstruktur

Produktstruktur

Erzeugung von Signalen

Sägezahn

Sägezahngenerator

VCO (Voltage Controlled Oscillator)

Rechteck

Rechteckgenerator

Lautstärke

Verstärker

VCA (Voltage Controlled Amplifier)

ADSR
(Attack, Decay, Sustain, Release)

VCF (Voltage Controlled Filter)

Erzeugung verschiedener Klänge

Veränderung von Klangparametern

Hüllkurvengenerator

Synthesizer

Klangform

Tiefpassfilter

Hochpassfilter

Mischer

Audio Mixer

Steuerung von Modulen

Sequenziell

Zähler

Sequencer

LFO (Low Frequency Oscillator)

Periodisch

Oszillator

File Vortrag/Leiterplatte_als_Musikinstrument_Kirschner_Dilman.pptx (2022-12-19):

## Die Leiterplatte als Musikinstrument

Disk Jockey männlich mit einfarbiger Füllung
Stimmgabel Silhouette

von Viktor Dilman
und Christoph Kirschner

Notenschrift mit einfarbiger Füllung

## Agenda

1. Projektvorstellung
2. Architektur eines Synthesizer
3. Exemplarischer Aufbau
4. Low Frequency Oscillator
5. Rapid-Prototyping mit Fusion 360

Technische Hochschule Nürnberg Georg Simon Ohm
www.th-nuernberg.de

Vortrag LPDES – Viktor Dilman, Christoph Kirschner

## 1. Projektvorstellung

- Titel: Entwicklung eines modularen Synthesizers
- Ziel: Erzeugung von Tönen auf elektronischem Wege
- Motivation: Erweiterung des Kenntnisstands bezüglich analoger Schaltungstechnik und Leiterplattendesign


Abb. 1.: Beispielfoto eines modularen Synthesizers [1]

Vortrag LPDES – Viktor Dilman, Christoph Kirschner

## 2. Architektur eines Synthesizer

Produktstruktur

Funktionsstruktur

Erzeugung von Signalen

Sägezahn

Sägezahngenerator

VCO (Voltage Controlled Oscillator)

Rechteck

Rechteckgenerator

VCA (Voltage Controlled Amplifier)

Erzeugung verschiedener Klänge

Lautstärke

Verstärker

Hochpassfilter

Veränderung von Klangparametern

Klangform

Tiefpassfilter

VCF (Voltage Controlled Filter)

Audio Mixer

Synthesizer

Sequenziell

Zähler

Mischer

Sequencer

LFO (Low Frequency Oscillator)

Steuerung von Modulen

Periodisch

Oszillator

Vortrag LPDES – Viktor Dilman, Christoph Kirschner

## 3. Exemplarischer Aufbau

Lautsprecher

Sequencer

VCO

VCF

VCA

LFO

Vortrag LPDES – Viktor Dilman, Christoph Kirschner

## 4.1 Low Frequency Oszillator


Abb. 2.: Schaltplan des LFO aus Fusion 360

Vortrag LPDES – Viktor Dilman, Christoph Kirschner

## 4.1 Low Frequency Oscillator


Abb. 3: Layout des LFO in Fusion 360


Abb. 4: Rendering der LFO-Platine (AISLER)

Vortrag LPDES – Viktor Dilman, Christoph Kirschner

## 3.1 Rapid-Prototyping mit Fusion360


Abb. 5: Export der Gerber-Datei in Fusion 360

Gerber
-Export


Abb. 6: Import der Gerber-Datei in Bantam Tools


Abb. 7: Fertige Prototypen-Platine

Abb. 6: Import der Gerber-Datei in Bantam Tools

Vortrag LPDES – Viktor Dilman, Christoph Kirschner

## 3.1 Rapid-Prototyping mit Fusion360


Video 1: Vorführung Bantam Tools [3]

Vortrag LPDES – Viktor Dilman, Christoph Kirschner

## 3.1 Rapid-Prototyping mit Fusion360


Frontplatten design in Fusion

Abb. 8: Konstruktion der Frontplatte mit 3D-Model der Platine

Vortrag LPDES – Viktor Dilman, Christoph Kirschner

## 3.2 Rapid-Prototyping mit Fusion360


Abb. 9: Export der stl-Datei


Abb. 10: Import der stl-Datei in Prusa Slicer

Vortrag LPDES – Viktor Dilman, Christoph Kirschner

## 3.2 Rapid-Prototyping mit Fusion360


Abb. 11: Moodle-Kurs des CWS [2]

Vortrag LPDES – Viktor Dilman, Christoph Kirschner

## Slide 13

Vielen Dank für Ihre Aufmerksamkeit!
Bock auf Synthie-Sounds ?

Vortrag LPDES – Viktor Dilman, Christoph Kirschner

## Quellen

[1] https://www.ericasynths.lv/shop/diy-kits-1/mki-x-esedu-diy-system
[2] https://elearning.ohmportal.de/course/view.php?id=10566
[3] https://www.youtube.com/watch?v=MNw2Ce_t8-g

Vortrag LPDES – Viktor Dilman, Christoph Kirschner

## Anhang: VCO


Abb.12.: Schaltplan des VCO aus Fusion 360

Vortrag LPDES – Viktor Dilman, Christoph Kirschner

## Anhang: Oszillator


Abb.12.: Oszillatorschaltung


Abb.13.: Simulation der Oszillatorschaltung in LTSpice

Vortrag LPDES – Viktor Dilman, Christoph Kirschner

## Anhang: VCO


Abb. 14: Layout des VCO in Fusion 360


Abb. 15: Rendering der VCO-Platine (AISLER)

Vortrag LPDES – Viktor Dilman, Christoph Kirschner

## Anhang: SEQ


Abb. 16: Schaltplan des Sequencers aus Fusion 360

Vortrag LPDES – Viktor Dilman, Christoph Kirschner

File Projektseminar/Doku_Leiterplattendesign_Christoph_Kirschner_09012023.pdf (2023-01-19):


## Fakultät Elektrotechnik Feinwerktechnik Informationstechnik

# Entwicklung eines modularen Synthesizers

## Dokumentation für das Fach Leiterplattendesign im MSY

vorgelegt von

## Dilman Viktor, Kirschner Christoph

Ausgabe: | 18.10.2022
Abgabe: | 09.01.2023
Prüfer: | Eduard Bluoss

## Inhaltsverzeichnis

ii

## Abkürzungsverzeichnis

ADSR | Attack Decay Sustain Release
ERC | Electrical Rule Check
DRC | Design Rule Check
LFO | Low Frequency Oscillator
VCA | Voltage Controlled Amplifier
VCF | Voltage Controlled Filter
VCO | Voltage Controlled Oscillator

iii

## Abbildungsverzeichnis

2.1 Architektur eines modularen Synthesizers | | 3
3.1 Fusion360 Schaltplan des LFO | | 5
3.2 Ausschnitt des LFO-Platinen-Layouts aus Fusion360 (Unterseite) | | 6
3.3 3D-Ansicht der LFO-Platine in Bantam-Tools-Software (Platinen-Fräße) [6] | | 7
3.4 3D-Darstellung der LFO-Platine mit Frontplatte | | 8
3.5 Ausschnitt aus “Prusa Slicer“ beim Vorbereiten des 3D-Drucks für die LFO-Platine [4] | 9
4.1 Typische Signale bei analogen Synthesizern [7] | | 10
4.2 Oszillatorschaltung | | 11
4.3 Oszillator Signalverlauf | | 12
4.4 Schaltplan VCO | | 15
4.5 VCO Layout in Fusion 360 | | 16
4.6 Erstellung der Einbauklinkenbuchse in Fusion 360 | | 17
4.7 VCO Leiterplatte | | 17
4.8 VCO Frontplatte | | 18
5.1 Schaltplan der Sequenzer-Platine | | 20
5.2 Ausschnitt des SEQ-Platinen-Layouts aus Fusion360 | | 22
5.3 3D-Darstellung der SEQ-Platine mit Frontplatte | | 23

iv

## Tabellenverzeichnis

4.1 Zusammenfassung der Ein- und Ausgabeelemente des VCOs | 14

v

## Kapitel 1

## Einleitung

Die Welt der Elektrotechnik ist mehr denn je im Umbruch und Wandel. Um für diese Herausforderungen gerüstet zu sein, ist es fundamental mit den Grundlagen dieses breitgefächerten Themengebietes bestens vertraut zu sein. Besonders im Bereich der analogen Schaltungstechnik ist es jedoch oft schwierig ein tieferes Verständnis für Vorgänge in komplexen Aufbauten zu erlangen. Die Mathematik bietet zwar meist sehr akkurate Mittel, um eine Schaltung ausreichend zu beschreiben, oft reicht dies jedoch für Anfänger nicht aus, um das Verhalten greifbar zu machen. Abhilfe kann hier die Visualisierung oder Simulation der entsprechenden Spannungsverläufe schaffen. Neben der visuellen Analyse kann jedoch auch der Klang von Signalverläufen tieferes Verständnis aufbauen. Durch die Durchführung dieser Projektarbeit soll besonders dieser Aspekt vertieft werden und somit der Wissensstand bezüglich analoger Schaltungstechnik im Allgemeinen ausgebaut werden. Darüber hinaus soll Elektrotechnik durch die elektronische Klangerzeugung für Außenstehende besser erfahrbar gemacht werden.

## Kapitel 2

## Konzepte

## 2.1 Zielsetzung

Wie bereits in Kapitel 1 beschrieben, dient diese Projektarbeit zur Wissenserweiterung im Bereich der analogen Schaltungstechnik. Darüber hinaus soll im Zuge dieser Arbeit ein einsetzbarer modularer Synthesizer gebaut werden, der zu elektronischen Klangerzeugung genutzt werden kann. Der Synthesizer soll aus verschiedenen Modulen bestehen, welche unabhängig von einander genutzt werden können. Der weitere Aufbau wird in Abschnitt 2.2 genauer beschrieben.

## 2.2 Aufbau eines modularen Synthesizers

Wie bereits in Abschnitt 2.1 erläutert, besteht ein modularer Synthesizer aus mehreren vereinzelten Modulen. Diese Module können mit Kabeln verbunden und somit in Interaktion miteinander gebracht werden.

Um eine grundlegende Funktion zu ermöglichen, ist ein Basisumfang an Modulen nötig. Die hierfür nötigen Komponenten oder Module werden im Folgenden aufgelistet und kurz erläutert.

- Netzteil:
Das Netzteil ist elementarer Bestandteil des Synthesizers und stellt die benötigten Spannungslevel zur Versorgung der einzelnen Module bereit. Insbesondere für den Einsatz von Operationsverstärkern sind symmetrische Spannungsversorgungen erforderlich.
- VCO:
Der VCO (Voltage Controlled Oscillator) ist ein spannungsgesteuerter Oszillator und stellt die Basis bei analogen Synthesizern dar. Über eine Steuerspannung kann die Frequenz des

erzeugten Signals und somit die Tonhöhe verändert werden.

- VCA:
Der VCA (Voltage Controlled Amplifier) stellt einen spannungsgesteuerten Verstärker da.

Dieser ermöglicht durch Veränderung der Steuerspannung die Beeinflussung der Lautstärke des Signals.

- ADSR:
ADSR steht für die vier Phasen einer Hüllkurve: Attack, Decay, Sustain und Release. Eingesetzt werden ADSR-Hüllkurven, um den Verlauf von Lautstärke von Tönen zu steuern. Üblicherweise legt man die Hüllkurve an den Steuereingang eines spannungsgesteuerten

Verstärkers (VCA).

Kapitel 2. Konzepte | 3
- VCF:
Der VCF (Voltage Controlled Filter) ermöglicht durch Veränderung der Steuerspannung

die Steuerung des Filterverhaltens. Durch Variieren der Eingangsspannung erfolgt die Veränderung der Filtereckfrequenz. Die Filterung verschiedener Frequenzanteile beeinflusst den Klang des Signals.

- Audio Mixer:
Der Audio Mixer verknüpft verschiedene Signale miteinandern, wodurch neue Signalformen und Klänge generiert werden können.
- Sequenzer:
Der Sequenzer erzeugt seriell alternierende Spannungsfolgen, die durch verschiedene Kippschalter und Potentiometer sowohl die einzelnen Spannungspegel als auch die gesamte Geschwindigkeit des Signals variieren. In der Regel werden die Ausgangssignale des Sequenzers zur Ansteuerung weiterer Module – den sogenannten spannungsgesteuerten-Modulen – hergenommen. Neben den Oszillatoren bildet der Sequenzer somit die Basis der Synthesizer-Module.
- LFO:
Ein LFO (Low Frequency Oscillator) wird genutzt, um niederfrequente Signale zu erzeugen.

Typischerweise wird er LFO genutzt, um andere Module anzusteuern.

Um den groben Aufbau und die dahinter liegende Struktur zu verdeutlichen, ist in Abbildung 2.1 die Architektur eines modularen Synthesizers aufgezeigt.

Erzeugung verschiedener Klänge; Funktionsstruktur; Produktstruktur; Erzeugung von Signalen; Klangform; Periodisch; VCO (Voltage Controlled Oscillator); LFO (Low Frequency Oscillator); Sequencer; VCF (Voltage Controlled Filter); Hochpassfilter; Tiefpassfilter; Rechteck; Rechteckgenerator; Sägezahn; Sägezahngenerator; Veränderung von Klangparametern; Mischer; Audio Mixer; Steuerung von Modulen; Oszillator; Sequenziell; Zähler; Synthesizer; Hüllkurvengenerator; ADSR (Attack, Decay, Sustain, Release); Lautstärke; Verstärker; VCA (Voltage; Controlled Amplifier)

Abbildung 2.1: Architektur eines modularen Synthesizers

## Kapitel 3

## LFO

## 3.1 Allgemeines

Wie bereits in Kapitel beschrieben, wird der LFO genutzt, um niederfrequente Signale zu erzeugen. Diese Signale werden typischerweise zur Steuerung von nachgelagerten Modulen, wie etwa dem LFO (siehe Kapitel 4), verwendet. Hierdurch kann beispielsweise die Frequenz des

VCO angepasst werden. Neben der Frequenz, die der LFO ausgibt, ist auch die entsprechende Signalform für den Klang entscheidend. Hier sind beispielsweise Signalformen, wie Dreieck oder Rechteck möglich.

## 3.2 Schaltplan

Im Folgenden wird näher auf den Schaltplan des LFO eingegangen, welcher in Abbildung 3.1 zu sehen ist [1]. Ein Bauteil von zentraler Bedeutung ist hierbei der Vierfach-Operationsverstärker

TL074P. In der gezeigten Schaltung wird dieser als Integrator, Schmitt Trigger, Buffer und LED-Treiber verwendet. Die grundlegende Funktionsweise dieser Funktionsgruppen wird in Abschnitt 4 erläutert. Aus diesem Grund wird nicht weiter auf die Funktionsweise eines Oszillators

eingegangen.


Abbildung 3.1: Fusion360 Schaltplan des LFO

08.12.2022 10:47 f=0.70 C:\WINDOWS\TEMP\Neutron\ElectronFileOutput\8468\sch-1a7677a2-da2a-4e61-bc71-1ba3b3569b34\LFO_Vers_1 v22.sch (Sheet: 1/1)

Kapitel 3. LFO | 6

## 3.3 Platine

In Abbildung 3.2 ist die untere Lage der Leiterplatte in blau dargestellt. Beim Erstellen der Platine wurde der Fokus auf die Produzierbarkeit mittels CNC-Fräße gelegt. Hierbei ist die Lagenzahl der Platine auf maximal zwei Lagen begrenzt, wobei nur einlagiges Platinenrohmaterial zur Verfügung stand. Um diese Limitation zu umgehen wurde versucht alle Leiterbahnen auf eine Platinen-Lage zu entflechten. Da manche Leiterbahnen nicht auf der Unterseite platziert werden konnten, wurden für die restlichen Bahnen auf der Oberseite Verbindungsdrähte verwendet. Hierfür wurden jeweils Via-Verbindungen mit größerem Bohrungsdurchmesser vorgesehen. Der Vorteil dieser Methode ist, dass die Platine ohne Mehraufwand auch professionell produziert werden kann. Die beschriebene Vorgehensweise wurde auch bei den übrigen Platinen dieser Projektarbeit angewendet.


Abbildung 3.2: Ausschnitt des LFO-Platinen-Layouts aus Fusion360 (Unterseite)

Kapitel 3. LFO | 7

Wie bereits beschrieben, wurde die Platine mit einer Platinenfräße angefertigt. Hierbei wurde die CNC-Fräße “Othermachine“ von “Bantam Tools“ verwendet. In Abbildung 3.3 is ein Ausschnitt aus der Steuer-Software von “Bantam Tools“ gezeigt. Mit Hilfe dieser Software können Gerber-Dateien oder brd-Dateien (Eagle) importiert werden und Fräßabläufe erzeugt werden.


Abbildung 3.3: 3D-Ansicht der LFO-Platine in Bantam-Tools-Software (Platinen-Fräße) [6]

Kapitel 3. LFO | 8

## 3.4 Mechanischer Aufbau

Um die LFO-Platine in einem Rack-System befestigen zu können, ist es nötig eine entsprechende Abdeckplatte mit Montagelöchern an der Platine anzubringen. Die Befestigung der Frontplatte an der LFO-Platine wird über das Gewinde an der AUX-Buchse realisiert. Dies hat sich bei lediglich einer Buchse als nicht ausreichend herausgestellt. Aus diesem Grund wurde die Platine zusätzlich mit Epoxit-Kleber an der Abdeckplatte fixiert.


Abbildung 3.4: 3D-Darstellung der LFO-Platine mit Frontplatte

Wie in 3.4 abgebildet, wurden die Beschriftungen als Ausschnitte in der Frontplatte angebracht. Hierdurch kann die Frontplatte mit einem Lasercutter kostengünstig produziert werden und es ist somit keine weiter Nachbearbeitung der Frontplatte nötig.

Um bereits vor dem Lasercutten der Frontplatte die grundsätzliche Tauglichkeit der Konstruktion erproben zu können, wurde mittels eines 3D-Drucker die Frontplatte gedruckt. Hierbei wurde ein “Prusa Mini“ und die dazugehörende “Prusa Sliver“-Software verwendet. Ein Ausschnitt dieser Software ist in Abbildung 3.5 zusehen.

Kapitel 3. LFO | 9


Abbildung 3.5: Ausschnitt aus “Prusa Slicer“ beim Vorbereiten des 3D-Drucks für die LFO-Platine [4]

Die in diesem Abschnitt aufgezeigte Vorgehensweise beim Prototypen der Abdeckplatte ist exemplarisch für alle Module dieser Projektarbeit. Aus diesem Grund wird in den folgenden Kapiteln nicht näher darauf eingegangen.

## Kapitel 4

## VCO

## 4.1 Allgemeines

Der VCO stellt die Basis aller analogen Synthesizers da. Mit einem spannungsgesteuerten Oszillator lassen sich verschiedene Signale generieren, deren Frequenz sich mit der angelegten Steuerspannung verändert. Analoge Synthesizer orientieren sich oft am 1V/Oktave-Standard. Dieser

besagt, dass sich die Frequenz des Signals mit jedem Volt verdoppelt. Dies ist von Vorteil, da das Verhältnis zwischen Musiknoten und deren zugeordneten Frequenzen ebenfalls exponentiell ist. Die tiefste C-Note entspricht beispielsweise einer Frequenz von 16,35 Hz. Wenn man eine Oktave nach oben geht, verdoppelt sich die Frequenz beim nächsten C auf etwa 32 Hz. Typische Signale bei analogen Synthesizern können der Abbildung 4.1 entnommen werden. [7]


Abbildung 4.1: Typische Signale bei analogen Synthesizern [7]

Bei dieser Umsetzung des VCOs wurde sich auf die Realisierung eines Sägezahn- und eines Rechtecksignals konzentriert, da diese aufgrund ihrem hohen Oberwellenanteil markant-hörbare Geräusche erzeugen. Ein Sinussignal hingegen stellt einen harmonischen Verlauf dar, der sich ebenfalls im Klang äußert. Hörbare Schwingungen werden mithilfe einer Oszillatorschaltung realisiert, auf die im Folgenden näher eingegangen wird.

Kapitel 4. VCO | 11


Abbildung 4.2: Oszillatorschaltung

Um die Oszillatorschaltung (vgl. Abbildung 4.2), die den Kern des VCOs darstellt, zu verstehen,

erfolgt die Betrachtung des Punktes rc. Zu Beginn liegt keine Spannung an, weil der Kondensator leer ist und noch kein Strom durch die Diode fließt. Das bedeutet, dass am Ausgang des Schmitt-Trigger-Inverters eine Spannung anliegt, da der Eingang unter dem unteren Eingangsschwellenwert liegt. Dadurch erfolgt ein Stromfluss vom Ausgang des Schmitt-Triggers über die Diode zu dem Punkt rc. Da der Kondensator zunächst leer ist, fließt der ganze Strom in diesen hinein. Während sich der Kondensator auflädt, steigt die Spannung an dem Punkt rc rapide an. Dieser Spannungsanstieg wird vom Schmitt-Trigger-Eingang registriert. Als Reaktion darauf fällt der Ausgang auf 0 V ab, sobald der Kondensator aufgeladen ist und die Spannung die obere Eingangsschwelle überschreitet. Das bedeutet, dass kein zusätzlicher Strom durch die Diode fließt und sich der Kondensator wieder entlädt. Da der Widerstand die Strommenge begrenzt, die durchfließen kann, wird der Kondensator nicht sofort entladen. Auf dem Spannungsdiagramm entsteht also ein langsamer Abfall. Das geht so lange, bis der untere Schwellenwert des Schmitt-Trigger-Inverters erreicht wird. Sobald diese Schwelle auf dem Weg nach unten unterschritten ist, beginnt der Zyklus von neuem. Die Simulation der Schaltung ergibt den Spannungsverlauf am Punkt rc in Abbildung 4.3.

Kapitel 4. VCO | 12


Abbildung 4.3: Oszillator Signalverlauf

Die Frequenz des entstandenen Sägezahnsignals hängt maßgeblich von dem Entladungsvorgang des Kondensators ab. Die Geschwindigkeit dieses Entladungsvorganges wird widerum durch genau zwei Faktoren bestimmt: die Kapazität des Kondensators und der Wert des Widerstands. Um den VCO an die Volt/Oktave-Norm anzupassen, muss die Beziehung zwischen Spannungs-

eingang und Frequenzausgang ebenfalls exponentiell sein, da im Grunde genommen Spannungen auf Musiknoten abgebildet werden. Transistoren sind hier besonders geeignet, da das Verhältnis zwischen der an ihrer Basis angelegten Spannung und dem Strom, den sie zwischen Kollektor und Emitter fließen lassen, exponentiell ist. Die Basisspannung kann mithilfe eines Potentiometers eingestellt werden. Zu beachten ist allerdings, dass bei einem üblichen NPN-Transistor die Kollektor-Emitter Strecke ab etwa einer BasisSpannung von 600 – 700 mV niederohmig wird und der Oszillator bei Anliegen dieser Schwellspannung nicht mehr schwingt. Liegt keine Spannung an, ist die Kollektor-Emitter Strecke hochohmig und der Oszillator kann ebenfalls nicht mehr schwingen. Der durch Ausprobieren ermittelte nutzbare Spannungbereich beträgt etwa 350 – 550 mV. Dies wird mithilfe eines einstellbaren Spannungsteilers realisiert.

Die verwendete Schaltung in Abbildung 4.4 ist zu großen Teilen an ein DIY VCO Kit von Moritz Klein und Erica Synths angelehnt und wird im Folgenden näher erklärt. [3]

## 4.2 Schaltplan

Wie im vorherigen Kapitel erläutert, erfolgt die Veränderung der Frequenz der Sägezahnschwingung (vgl. Abbildung 4.3) mithilfe eines NPN-Transistors, welcher im ersten Bereich des Schalt-

plans zu sehen ist. Der davor geschaltene PNP-Transistor dient zur Temperaturkompensation und fungiert als Emitterfolger, indem die an seiner Basis anliegende Spannung an den Emitter kopiert wird. Allerdings ist die am Emitter des PNP-Transistors anliegende Spannung um der Schwellspannung des Transistors höher. Bei Versuchen an der realen Schaltung betrug diese etwa 500 mV. Um den gewünschten Spannungsbereich an der Basis des NPN-Transistors von etwa

Kapitel 4. VCO | 13

350 – 550 mV zu erreichen, muss das Potentiometer für die Einstellung der Basisspannung der Transistoren auch negative Spannungswerte liefern.

Aus diesem Grund wird im zweiten Bereich des Schaltplans das Potentiometer VR1 für die grobe Einstellung der Frequenz zwischen der negativen und positiven Versorgunsspannung angeschlossen. Da die Versorgungsspanung ±12 V beträgt, wird diese mithilfe entsprechender Spannungteiler (R1, R2, R3, R7, R8) um etwa das 50-fache auf ca. -130 – 20 mV verringert. Für die Feineinstellung der Frequenz (VR2) wird durch einen größeren Widerstand (R4) ein Teilerfaktor von

etwa 500 realisiert, der eine Spannung im Bereich von -10 – 0 mV liefert. Mithilfe dem Eingang CV_IN (Control Voltage In) kann ein Sequencer mit einem Klinkenkabel angeschlossen werden, der eine Eingangsspannung von 0 – 5 V liefert. Um die Volt/Oktave-Norm anzuwenden wird aufgrund von Bauteiltoleranzen zusätzlich ein Präzisiondrehpotentiometer (R8) verwendet, damit das Verhältnis des Spannungsteilers justiert werden kann. Die Klinkenbuchse FM_IN (Frequency Modulation In) stellt im Prinzip einen weiteren Control Voltage-Eingang dar, dessen Intensität

zusätzlich durch ein Potentiometer eingestellt werden kann. An diesen kann beispielsweise ein LFO (Low Frequency Oscillator) angeschlossen werden. Um die Temperaturabhängigkeit der

Schaltung zu verbessern, wird weiterhin an allen Eingängen ein NTC-Widerstand angebracht.

Um die resultierende Sägezahnschwingung nach außen führen zu können, wird ein entsprechender Buffer benötigt, der durch einen Operationsverstärker realisiert wird. Dies ist zwingend notwendig, da ansonsten in die Funktionsweise der Oszillatorschaltung eingegriffen wird. Dieser Buffer befindet sich im dritten Bereich des Schaltplans. Weiterhin wird eine AC-Kopplung mithilfe des Kondensators C2 und dem Widerstand R10 realisiert. Diese wird benötigt um eine eventuelle Offset-Spannung der Sägezahnspannung zu entfernen, damit das Signal um den definierten Pegel von 0 V schwingt.

Im vierten Bereich des Schaltplans wird das Rechtecksignal generiert. Dies erfolgt durch eine Komperatorschaltung. An den invertierenden Eingang des Operationsverstärker wird die zu vergleichende Schwellspannung angelegt. Wird diese überschritten, liefert der Operationsverstärker 12 V. Bei Unterschreitung der Schwellspannung liefert dieser -12 V. Wird die zu vergleichende Spannung variiert, ändert sich das Pulsbreitenverhältnis. Zu beachten ist, dass die einstellbare Schwellspannung nicht höher als die Spannung des Signals selber sein darf, da dadurch der Ausgang einen festen Pegel erhält und kein oszillierendes Signal mehr darstellt. Die Spannung des Sägezahnsignals beträgt an diesem Punkt etwa ±1,5 V. Durch das Potentiometer VR4 kann die Pulsbreite des Rechtecksignals eingestellt werden. Mithilfe dem Spannungsteiler (R14, R17) wird die einstellbare Schwellspannung von ±12 V auf etwa ±1,5 V begrenzt, damit sichgerstellt

wird, dass die Schwellspannung nicht höher als das Signal ist. Mithilfe dem Eingang PWM_In kann die Pulsbreite durch ein anderes Signal wie beispielsweise eines LFOs extern moduliert werden.

Im fünften Bereich des Schaltplans erfolgt die Anpassung auf einen definierten Pegel von 10 V peak-to-peak. Da die Sägezahnschwingung eine geringe Spannung aufweist, wird diese mithilfe einer nicht invertierenden Verstärkerschaltung vergrößert und an den Klinkenbuchsenausgang SAW_OUT geführt. Da der Spannungspegel des Rechtecksignals durch die Komperatorschaltung verstärkt wurde, muss dieser mithilfe eines Spannungsteilers (R15, R18) entsprechend re-

Kapitel 4. VCO | 14

duziert werden. Schließlich wird das Ausgangssignal durch einen Buffer an den Ausgang PUL-SE_OUT geführt.

Der nicht eingerahmte Bereich im Schaltplan umfasst die Spannungsversorgung. Mihilfe von Schottky-Dioden (D2, D3) wird der Verpolungsschutz der Eingangsspannung von ±12 V gewährleistet. Durch die Stützkondensatoren (C3 – C7) wird die Versorgungsspannung sowohl

am Eingang der Spannungsversorgung am Wannenstecker als auch an den IC-Pins stabilisiert. Weiterhin werden nicht verwendete Eingänge des Schmitt-Triggers mit Masse verbunden.

In der folgenden Tabelle werden die Ein- und Ausgabeelemente des VCOs zusammengefasst:

Tabelle 4.1: Zusammenfassung der Ein- und Ausgabeelemente des VCOs

Bauteilbezeichnung | Kurzbeschreibung | Funktion
VR1 | Coarse | Grobeinstellung der Frequenz
VR2 | Fine | Feineinstellung der Frequenz
VR3 | FM LVL | Einstellung der Intensität des FM-Eingangs
VR4 | PWM | Einstellung der Pulsweite
VR5 | PWM LVL | Einstellung der Intensität des externen Signals zur Pulsweitenmodulation
J2 | CV IN | Eingang der Steuerspannung
J3 | FM IN | Eingang der Steuerspannung zusätzliche Einstellmöglichkeit der Intensität durch VR3
J4 | PWM IN | Eingang des externen Signals zur Pulsweitenmo-dulation
J5 | Saw Out | Ausgang des generierten Sägezahnsignals
J5 | Pulse Out | Ausgang des generierten Rechtecksignals

Nachdem die Funktionsweise der Schaltung auf einem Breadboard verifiziert wurde, wird ein Platinenlayout erstellt. Auf die Vorgehensweise bei der Layouterstellung wird im folgenden Kapitel näher eingegangen.


mit Pufferkondensatoren und Verpolungsschutz

Spannungversorgung Spannungsversorgung ICs mit Abblockkondensatoren

zur feinen Ansteuerung des Transistors

Frequency Modulation Eingang (LFO)

Control Voltage Eingang (Sequencer)

Externe Modulation der Pulsbreite

Manuelle Veränderung der Pulsbreite

Digitaleingänge des Scmitt-Triggers auf festes Potenzial setzen (GND)

Anpassung auf 10V peak to peak Generierung des Rechtecksignals

Anpassung auf 10V peak to peak

Kapitel 4. VCO | 16

## 4.3 Platine

Nachdem der Schaltplan in Fusion 360 erstellt wurde und mit dem ERC (Electrical Rule Check)-Tool validiert wurde, erfolgt die Erstellung des Platinenlayouts (siehe Abbildung 4.5). Die äuße-

ren Abmaße der Platine sind in Bezug auf die Höhe eines Euro Racks von 128,5 mm beschränkt. Gewählt wurde eine Platinenhöhe von 100 mm, damit ausreichend Platz zur Befestigung der Leiterplatte gewährleistet ist.


Abbildung 4.5: VCO Layout in Fusion 360

Die Bauteile wurden einerseits so positioniert, dass die Leiterbahnen möglichst kurz und überschneidungsfrei verlegt werden können. Andererseits wurden die Potentiometer und Klinkenbuchsen logisch so angeordnet dass die zu einer Einbauklinkenbuchse gehörenden Potentiometer übereinander liegen. Weiterhin wurde darauf geachtet, dass die Transistoren für die Temperaturkompensation möglichst nah aneinander positioniert werden. Zudem sind die Stützkondensatoren der ICs möglichst nah an den Versorgungspins der Bauteile zu positionieren.

Bei der Erstellung der Platine wurde darauf geachtet möglichst eine Layer zu verwenden, um die Platine mit einer Platinenfräse herstellen zu können. Dies ist von Vorteil, da bei der professionellen Anfertigung von Platinen von der Bestellung bis zur Lieferung einige Wochen vergehen können. Ist der Zugang zu einer Fräse gegeben, kann die erstellte Platine sofort getestet und eventuelle Fehler ausgebessert werden.

Kapitel 4. VCO | 17

Damit die Leiterplatte mit einer Platinenfräse angefertigt werden kann, ist eine relativ dicke Leiterbahnbreite erforderlich. Gewählt wurde deshalb eine Leiterbrahnbreite von 50 mil. An den Stellen, an denen die Leiterbahnen nicht überschneidungsfrei verlegt werden konnten, wurden Vias hinzugefügt und die Leiterbahn auf der anderen Seite fortgeführt. Auf der gefrästen Platinen können diese Vias mit Brücken verbunden werden.

Da für die verwendeten Einbauklinkenbuchsen keine passende Bibliothek existiert, musste diese manuell angelegt werden. Dafür wurde ein Symbol einer ähnlichen Klinkenbuchse verwendet und das Footprint nach dem Datenblatt des Herstellers erstellt wie in Abbildung 4.6 zu sehen. [5]


(a) Verwendetes Symbol | (b) Erstelltes Footprint

Abbildung 4.6: Erstellung der Einbauklinkenbuchse in Fusion 360

Nachdem die erstellte Leiterplatte mit dem DRC (Design Rule Check)-Tool in Fusion 360 auf

Fehlerfreiheit geprüft wurde, erfolgt der Export der Gerber-Files. Die Leiterplatte wurde dabei mit einer Platinenfräse von Bantam Tools hergestellt. Anschließend erfolgt die Bestückung der Leiterplatte mit den im Stromlaufplan verwendeten Komponenten und das Testen der Platine. Ist die Funktion der gefrästen Leiterplatte geprüft, erfolgt die Bestellung bei dem Platinenhersteller Aisler. In Abbildung 4.7a ist die Vorderseite der Platine zu sehen. Die Abbildung 4.7b zeigt hingegen die Rückseite der VCO-Leiterplatte.


(a) Vorderseite | (b) Rückseite

Abbildung 4.7: VCO Leiterplatte

Kapitel 4. VCO | 18

## 4.4 Mechanischer Aufbau

Mithilfe der Fusion 360 -Funktionalität der Übertragung einer 2D- auf eine 3D-Leiterplatte wur-

de eine Abdeckung konstruiert (siehe Abbildung 4.8). Dies hat den Vorteil, dass für die Poten-

tiometer und Klinkenbuchsen die Aussparungen an der Frontplatte exakt positioniert werden können. Die Abdeckplatte wird mithilfe von Gewindeschrauben der Einbauklinkenbuchsen an die Platine befestigt. Weiterhin werden auf die Potentiometer Abdeckkappen angebracht, die zusätzlichen Halt bieten. An den Ecken der Frontplatte werden Aussparungen vorhergesehen, um das Modul in einem Eurorack-Gehäuse befestigen zu können. Schließlich wird die Frontplatte aus Plexiglas mit einem Laser-Cutter gefertigt.


Abbildung 4.8: VCO Frontplatte

## Kapitel 5

## Sequenzer

## 5.1 Allgemeines

Bei dieser Umsetzung eines Sequenzers wurde sich für maximal fünf alternierende Spannungspegel entschieden. In der Literatur ist diese Unterart als 5-Step-Sequencer bekannt, welche wegen ihrer markanten Charakteristik zum Beispiel im bekannten »Hier Name des Syntis im Labor einsetzten« Synthesizer eingesetzt wird. »Als Quelle Manual von genanntem Synti nennen«. Über

zwei in der Handebene verbaute Kippschalter kann alternativ zwischen 3- bzw. 4-Stufen-Betrieb gewählt werden. Welcher Schritt aktuell aktiv ist wird durch Status-LEDs in der Frontplatte angezeigt.
Als Spannungsversorgung erhält der Sequenzer ±12 Volt durch das verbaute Netzteil. Optional kann ein externes Clock-Signal, beispielsweise von einem LFO (vgl. Kapitel 3), angeschlossen

werden. Der eigene Takt wird dadurch überbrückt, wodurch das Modul flexibel eingesetzt werden kann. Des Weiteren kann die Sequenz durch ein externes Signal zurückgesetzt werden. Dadurch wird automatisch wieder bei der ersten Stufe der Sequenz begonnen, wodurch dem Nutzer weiterer musikalischer Freiraum freigeräumt wird.
Das Sequenzer-Modul verfügt über drei abgreifbare Ausgangssignale. Ein Clock-Signal, welches über ein Potentiometer in der Handebene parametrisiert werden kann, gibt den internen Takt des Moduls vor, und kann von außerhalb abgegriffen werden. Dessen Spannung toggelt dabei zwischen -12 und +12 Volt. Die Control Voltage (CV) wird zumeist dem VCO (vgl. Kapitel 4)

zur weiteren Verarbeitung überreicht. Dabei handelt es sich um eine alternierende Spannungsfolge, welche zwischen 0 und 5 Volt schwanken kann. Die einzelnen Spannungspegel der bis zu fünf Stufen werden durch ein jeweiliges Potentiometer in der Handebene eingestellt. Das dritte Ausgangssignal des Sequenzers bildet der Gate. Ähnlich dem CV wird eine alternierende Span-

nungsfolge von bis zu fünf Stufen ausgegeben, wobei eine Stufe in zwei Abschnitte geteilt wird. Der erste Abschnitt beträgt, abhängig dem jeweiligen Kippschalter in der Handebene, entweder +12 oder 0 Volt. Der zweite Abschnitt führt immer 0 Volt. Der Gate verhält sich somit ähnlich dem Clock-Signal. Er führt jedoch niemals eine Negative Spannung und seine Stufen sind manuell zuschaltbar. In der Regel wird der Gate als Eingangssignal für den ADSR hergenommen.

## 5.2 Schaltplan


Abbildung 5.1: Schaltplan der Sequenzer-Platine

Versorgung-Op-Amp: Euro-Rack-Stecker: Versorgung-Dekaden-Zähler:

Kapitel 5. Sequenzer | 21

Der Schaltplan des Sequenzers lässt sich, wie in Abbildung 5.1 gezeigt, in sechs Bereiche unterteilen. Der Bereich eins ist zuständig für das Durchschalten der Zustände. Die wesentliche Komponente ist dabei das Bauteil U1G1. Es handelt sich dabei um einen CD4017 Dekadenzähler, der durch das Toggeln des Clock-Signals die verschiedenen Zustände durchschaltet. Der Sequenzer ist für eine Sequenz von maximal 5 Stufen ausgelegt. Durch die beiden Schalter J11 und J12 kann diese jedoch auf 4 bzw. 3 Stufen reduziert werden, was sich an der Rückführung der jeweiligen Stufen auf den RESET-Pin erkennen lässt. Durch den RESET-Eingang J13 lässt sich zusätzlich ein externes Signal einbinden, was einen Fremd-RESET ermöglicht.
Der zweite Bereich des Schaltplans kümmert sich um das Clock-Signal. Dafür wird der Operationsverstärker (OPV) IC1A sowohl über eine Mitkopplung durch R23, als auch über eine Gegen-

kopplung durch R27 und VR2 betrieben. Der dadurch realisierte Negativ-Impedanz-Konverter läd bzw. entläd den Kondensator C3 in Abhängigkeit des Potentiometers VR2. Das daraus entstehende Clock-Signal wird über einen Buffer (IC1D) geführt und unter anderem über den

Klinkenausgang J9 nach außen zur Verfügung gestellt. Der Klinkeneingang J10 ist zusätzlich in der Lage das interne Clock-Signal durch ein extern angelegtes zu übersteuern.
Im dritten Abschnitt werden den verschieden Zuständen ihre jeweiligen Spannungen zugewiesen. Um das zu erreichen wird jedes Zustandssignal über ein separates Potentiometer gegen Masse geführt. Der Abgriff wird anschließend durch jeweilige Dioden vor rückfließenden Strömen geschützt und zusammengeführt. Um das Spannungssignal nun zu limitieren, wurden zwei Spannungsteiler R1 und R3 für 0 - 5 Volt sowie R1 und R4 für 0 - 2.5 Volt eingesetzt. Um Bauteiltoleranzen kompensieren zu können wurden zusätzlich zwei Trimmer R5 und R6 verbaut. Zwischen den Spannungsbereichen kann über den Schalter J2 gewechselt werden (default: 0 - 5 Volt). Danach kommt wieder ein Buffer (IC1C) und in Reihe dazu der Widerstand R2. Dieser

Widerstand sorgt dafür, dass im Falle eines Kurzschlusses der Fehlerstrom begrenzt und dadurch kein Schaden in der Schaltung entsteht. Der so entstandene CV kann über den Klinkenausgang J5 abgegriffen werden.
Der vierte Bereich des Schaltplans (vgl. Abbildung 5.1) ermöglicht das Ablesen des aktiven Zustandes über die Frontplatte. Dafür wird für jeden möglichen Zustand eine LED (D6 - D10)

angeschaltet, welche nach außen geführt ist. Die LEDs werden durch eine Emitterschaltung eines 2N3904 NPN Transistor angesteuert. Somit werden die Spannungssignale entlastet und möglichem Schaden vorgebeugt.
Die Funktionalität des Gate-Ausgangs wird in Bereich fünf umgesetzt. Die verschiedenen Stufenspannungen des Dekadenzählers aus Bereich eins werden jeweils über einen Kippschalter sowie eine Diode geführt und danach vereint. Die Schalter ermöglichen ein manuelles Zu- bzw. Wegschalten der einzelnen Stufe im resultierenden Gate-Signal. Die Dioden verhindern, wie auch bei der Umsetzung des CV, ein rückfließen der Ströme in die anderen Stufensignale. Nach der Zusammenführung der Signale folgt der Widerstand R20, sowie das über eine Diode begrenzte Clock-Signal. Das Clock-Signal sorgt dafür das der Gate in jedem Zyklus für die halbe Zeit auf 0 Volt gesetzt wird. Durch den Widerstand R20 wird einem Kurzschluss in diesem Pfad vorgebeugt. Der Widerstand R19 verhindert einen undefinierten Zustand sobald ein Stufe durch einen Kippschalter weggeschaltet wird. Allerdings bilden R19 und R20 einen ungewollten Spannungsteiler, der aus den gewünschten +12 Volt +6 Volt macht. Aus diesem Grund wurde ein weiterer OPV als einfacher Komparator verbaut. Die Widerstände R17 und R18 sorgen für eine Vergleichsspannung von 3.8 Volt am nicht-invertierenden Eingang, weshalb bei den anliegenden

Kapitel 5. Sequenzer | 22

+6 Volt problemlos durchgeschaltet wird. Der negative Teil der Spannung wird anschließend durch die Diode D17 sowie den Pulldown-Widerstand R21 unterbunden. Um der resultierenden hohen Impedanz sowie der begrenzt möglichen Stromentnahme der aktuellen Schaltung entgegenzuwirken, wurde der Ausgang mit einem BC547 NPN Transistor versehen. Dieser wurde als Kollektorschaltung implementiert sowie, um Kurzschlüsse zu vermeiden, mit einem weiteren Widerstand R32 verbaut. Der Gate kann somit über den Klinkenausgang J14 von außen abgegriffen werden.
Der letzte Bereich ist zuständig für die Spannungsversorgung des gesamten Moduls. Das Netzteil (vgl. Kapitel ??) versorgt den Sequenzer mit ±12 Volt durch den Euro-Rack-Stecker. Um Verpo-

lung vorzubeugen, wurden zwei Dioden D21 und D22 verbaut. Anschließend werden die beiden Spannungen mit den Kondensatoren C6 und C7 gegen Masse gepuffert. Weitere Pufferkondensatoren wurden in der Versorgung der OPV als auch in der Versorgung des Dekadenzählers vorgesehen [2].

## 5.3 Platine


Abbildung 5.2: Ausschnitt des SEQ-Platinen-Layouts aus Fusion360

Kapitel 5. Sequenzer | 23

## 5.4 Mechanischer Aufbau


Abbildung 5.3: 3D-Darstellung der SEQ-Platine mit Frontplatte

## Literaturverzeichnis

[1] David Haillant. LFO MANUAL. url: https : / / www . davidhaillant . com / category /

electronic-projects/simple-lfo/ (https://www.davidhaillant.com/category/electronic-projects/simple-lfo/) (besucht am 21. 12. 2022).

[2] Erica Synths Moritz Klein. SEQ MANUAL v1. url: https://www.ericasynths.lv/shop/

diy-kits-1/edu-diy-sequencer/ (https://www.ericasynths.lv/shop/diy-kits-1/edu-diy-sequencer/) (besucht am 21. 12. 2022).

[3] Erica Synths Moritz Klein. VCO MANUAL v2. url: https : / / www . ericasynths . lv /

media/VCO_MANUAL_v2.pdf (https://www.ericasynths.lv/media/VCO_MANUAL_v2.pdf) (besucht am 21. 12. 2022).

[4] Prusa. Prusa Printers Webseite. url: https : / / www . prusa3d . com / de/ (https://www.prusa3d.com/de/) (besucht am
21. 12. 2022).
[5] Reichelt. Datenblatt Einbau-Klinkenbuchse CLIFF FC681374V. url: https://cdn-reichelt.

de/documents/datenblatt/C160/CLIFFFC681374V.pdf (https://cdn-reichelt.de/documents/datenblatt/C160/CLIFFFC681374V.pdf) (besucht am 21. 12. 2022).

[6] Bantam Tools. Bantam Tools Webseite. url: https://www.bantamtools.com/ (besucht am 21. 12. 2022).
[7] Ray Wilson. Make: Analog Synthesizers. 2013.

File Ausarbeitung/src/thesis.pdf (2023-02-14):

## Fakultät Elektrotechnik Feinwerktechnik Informationstechnik

# Entwicklung eines modularen Synthesizers

## Projektarbeit im MSY

vorgelegt von

Altaher Ahmad, Balbach Thomas, Dilman Viktor, Kirschner Christoph,

## Sedlmeier Toni

Ausgabe: | 18.10.2022
Abgabe: | –
Prüfer: | Prof. Dr.Alexander von Hoffmann

## Inhaltsverzeichnis

ii

Inhaltsverzeichnis | iii

iii

## Abkürzungsverzeichnis

ADSR | Attack Decay Sustain Release
ERC | Electrical Rule Check
DRC | Design Rule Check
LFO | Low Frequency Oscillator
VCA | Voltage Controlled Amplifier
VCF | Voltage Controlled Filter
VCO | Voltage Controlled Oscillator
VCR | Voltage Controlled Resistor

iv

## Abbildungsverzeichnis

2.1 Architektur eines modularen Synthesizers | | 3
4.1 Fusion360 Schaltplan des LFO | | 6
4.2 Ausschnitt des LFO-Platinen-Layouts aus Fusion360 (Unterseite) | | 7
4.3 3D-Ansicht der LFO-Platine in Bantam-Tools-Software (Platinen-Fräße) [7] | | 8
4.4 3D-Darstellung der LFO-Platine mit Frontplatte | | 9
4.5 Ausschnitt aus “Prusa Slicer“ beim Vorbereiten des 3D-Drucks für die LFO-Platine [5] 10
5.1 Typische Signale bei analogen Synthesizern [8] | | 11
5.2 Oszillatorschaltung | | 12
5.3 Oszillator Signalverlauf | | 13
5.4 Schaltplan VCO | | 16
5.5 VCO Layout in Fusion 360 | | 17
5.6 Erstellung der Einbauklinkenbuchse in Fusion 360 | | 18
5.7 VCO Leiterplatte | | 18
5.8 VCO Frontplatte | | 19
6.1 Schaltplan der Sequenzer-Platine | | 21
6.2 Ausschnitt des SEQ-Platinen-Layouts aus Fusion360 | | 23
6.3 3D-Darstellung der SEQ-Platine mit Frontplatte | | 24
7.1 Frequenzgang eines digitalen Filters | | 25
7.2 Frequenzgang des Filters bei CV-Sweep CV1 -4V bis +4V | | 26
7.3 Frequenzgang des Filters bei Potentiometer-Sweep VR1 0 bis 100kΩ | | 27
7.4 Scaltplan des VCF | | 27
7.5 Platinen-Layout des VCF | | 28
7.6 3D-Darstellung der VCF-Frontplatte | | 28
8.1 Ausschnitt des Mischer-Schaltplanes aus Fusion360 [2] | | 30
8.2 Ausschnitt des Mischer-Platinen-Layouts aus Fusion360 (Unterseite) | | 31

v

## Tabellenverzeichnis

5.1 Zusammenfassung der Ein- und Ausgabeelemente des VCOs | 15

vi

## Kapitel 1

## Einleitung

Die Welt der Elektrotechnik ist mehr denn je im Umbruch und Wandel. Um für diese Herausforderungen gerüstet zu sein, ist es fundamental mit den Grundlagen dieses breitgefächerten Themengebietes bestens vertraut zu sein. Besonders im Bereich der analogen Schaltungstechnik ist es jedoch oft schwierig ein tieferes Verständnis für Vorgänge in komplexen Aufbauten zu erlangen. Die Mathematik bietet zwar meist sehr akkurate Mittel, um eine Schaltung ausreichend zu beschreiben, oft reicht dies jedoch für Anfänger nicht aus, um das Verhalten greifbar zu machen. Abhilfe kann hier die Visualisierung oder Simulation der entsprechenden Spannungsverläufe schaffen. Neben der visuellen Analyse kann jedoch auch der Klang von Signalverläufen tieferes Verständnis aufbauen. Durch die Durchführung dieser Projektarbeit soll besonders dieser Aspekt vertieft werden und somit der Wissensstand bezüglich analoger Schaltungstechnik im Allgemeinen ausgebaut werden. Darüber hinaus soll Elektrotechnik durch die elektronische Klangerzeugung für Außenstehende besser erfahrbar gemacht werden.

## Kapitel 2

## Konzepte

## 2.1 Zielsetzung

Wie bereits in Kapitel 1 beschrieben, dient diese Projektarbeit zur Wissenserweiterung im Bereich der analogen Schaltungstechnik. Darüber hinaus soll im Zuge dieser Arbeit ein einsetzbarer modularer Synthesizer gebaut werden, der zu elektronischen Klangerzeugung genutzt werden kann. Der Synthesizer soll aus verschiedenen Modulen bestehen, welche unabhängig von einander genutzt werden können. Der weitere Aufbau wird in Abschnitt 2.2 genauer beschrieben.

## 2.2 Aufbau eines modularen Synthesizers

Wie bereits in Abschnitt 2.1 erläutert, besteht ein modularer Synthesizer aus mehreren vereinzelten Modulen. Diese Module können mit Kabeln verbunden und somit in Interaktion miteinander gebracht werden.

Um eine grundlegende Funktion zu ermöglichen, ist ein Basisumfang an Modulen nötig. Die hierfür nötigen Komponenten oder Module werden im Folgenden aufgelistet und kurz erläutert.

- Netzteil:
Das Netzteil ist elementarer Bestandteil des Synthesizers und stellt die benötigten Spannungslevel zur Versorgung der einzelnen Module bereit. Insbesondere für den Einsatz von Operationsverstärkern sind symmetrische Spannungsversorgungen erforderlich.
- VCO:
Der VCO (Voltage Controlled Oscillator) ist ein spannungsgesteuerter Oszillator und stellt die Basis bei analogen Synthesizern dar. Über eine Steuerspannung kann die Frequenz des

erzeugten Signals und somit die Tonhöhe verändert werden.

- VCA:
Der VCA (Voltage Controlled Amplifier) stellt einen spannungsgesteuerten Verstärker da.

Dieser ermöglicht durch Veränderung der Steuerspannung die Beeinflussung der Lautstärke des Signals.

- ADSR:
ADSR steht für die vier Phasen einer Hüllkurve: Attack, Decay, Sustain und Release. Eingesetzt werden ADSR-Hüllkurven, um den Verlauf von Lautstärke von Tönen zu steuern. Üblicherweise legt man die Hüllkurve an den Steuereingang eines spannungsgesteuerten

Verstärkers (VCA).

Kapitel 2. Konzepte | 3
- VCF:
Der VCF (Voltage Controlled Filter) ermöglicht durch Veränderung der Steuerspannung

die Steuerung des Filterverhaltens. Durch Variieren der Eingangsspannung erfolgt die Veränderung der Filtereckfrequenz. Die Filterung verschiedener Frequenzanteile beeinflusst den Klang des Signals.

- Audio Mixer:
Der Audio Mixer verknüpft verschiedene Signale miteinandern, wodurch neue Signalformen und Klänge generiert werden können.
- Sequenzer:
Der Sequenzer erzeugt seriell alternierende Spannungsfolgen, die durch verschiedene Kippschalter und Potentiometer sowohl die einzelnen Spannungspegel als auch die gesamte Geschwindigkeit des Signals variieren. In der Regel werden die Ausgangssignale des Sequenzers zur Ansteuerung weiterer Module – den sogenannten spannungsgesteuerten-Modulen – hergenommen. Neben den Oszillatoren bildet der Sequenzer somit die Basis der Synthesizer-Module.
- LFO:
Ein LFO (Low Frequency Oscillator) wird genutzt, um niederfrequente Signale zu erzeugen.

Typischerweise wird er LFO genutzt, um andere Module anzusteuern.

Um den groben Aufbau und die dahinter liegende Struktur zu verdeutlichen, ist in Abbildung 2.1 die Architektur eines modularen Synthesizers aufgezeigt.

Erzeugung verschiedener Klänge; Funktionsstruktur; Produktstruktur; Erzeugung von Signalen; Klangform; Periodisch; VCO (Voltage Controlled Oscillator); LFO (Low Frequency Oscillator); Sequencer; VCF (Voltage Controlled Filter); Hochpassfilter; Tiefpassfilter; Rechteck; Rechteckgenerator; Sägezahn; Sägezahngenerator; Veränderung von Klangparametern; Mischer; Audio Mixer; Steuerung von Modulen; Oszillator; Sequenziell; Zähler; Synthesizer; Hüllkurvengenerator; ADSR (Attack, Decay, Sustain, Release); Lautstärke; Verstärker; VCA (Voltage; Controlled Amplifier)

Abbildung 2.1: Architektur eines modularen Synthesizers

## Kapitel 3

## Netzteil

## 3.1 Allgemeines

Um eine fehlerfreie Funktion aller weiteren Module zu gewährleisten, ist es wichtig, dass eine geeignete Spannungsversorgung bereitgestellt wird. Insbesondere für die Opamp-Schaltungen ist es wichtig, dass eine störfreie symmetrische Spannung bereitgestellt wird. Im Bereich der modularen Synthesizer wird hier typischerweise eine Spannung von +/- 12 V benötigt. Diese

Spannungspegel werden durch eine geignete Beschaltung von Dioden und Kondensatoren generiert, welche in Abschnitt ?? bzw. ?? genauer erläutert wird. Hierbei wird die für modulare Synthesizer typischerweise eingesetzte Wannenstecker-Belegung verwendet. Diese wird entsprechend in allen Modulen eingesetzt!

## Kapitel 4

## LFO

## 4.1 Allgemeines

Wie bereits in Kapitel beschrieben, wird der LFO genutzt, um niederfrequente Signale zu erzeugen. Diese Signale werden typischerweise zur Steuerung von nachgelagerten Modulen, wie etwa dem LFO (siehe Kapitel 5), verwendet. Hierdurch kann beispielsweise die Frequenz des

VCO angepasst werden. Neben der Frequenz, die der LFO ausgibt, ist auch die entsprechende Signalform für den Klang entscheidend. Hier sind beispielsweise Signalformen, wie Dreieck oder Rechteck möglich.

## 4.2 Schaltplan

Im Folgenden wird näher auf den Schaltplan des LFO eingegangen, welcher in Abbildung 4.1 zu sehen ist [1]. Ein Bauteil von zentraler Bedeutung ist hierbei der Vierfach-Operationsverstärker

TL074P. In der gezeigten Schaltung wird dieser als Integrator, Schmitt Trigger, Buffer und LED-Treiber verwendet. Die grundlegende Funktionsweise dieser Funktionsgruppen wird in Abschnitt 5 erläutert. Aus diesem Grund wird nicht weiter auf die Funktionsweise eines Oszillators

eingegangen.


Abbildung 4.1: Fusion360 Schaltplan des LFO

08.12.2022 10:47 f=0.70 C:\WINDOWS\TEMP\Neutron\ElectronFileOutput\8468\sch-1a7677a2-da2a-4e61-bc71-1ba3b3569b34\LFO_Vers_1 v22.sch (Sheet: 1/1)

Kapitel 4. LFO | 7
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

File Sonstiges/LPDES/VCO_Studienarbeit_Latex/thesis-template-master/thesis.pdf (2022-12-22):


## Fakultät Elektrotechnik Feinwerktechnik Informationstechnik

# Entwicklung eines modularen Synthesizers:

# Voltage Controlled Oscillator

## Studienarbeit im MSY

vorgelegt von

## Dilman Viktor

Abgabe: | 22.12.2022
Prüfer: | M.Eng. Eduard Bluoss

## Inhaltsverzeichnis

ii

## Abkürzungsverzeichnis

ADSR | Attack Decay Sustain Release
ERC | Electrical Rule Check
DRC | Design Rule Check
LFO | Low Frequency Oscillator
VCA | Voltage Controlled Amplifier
VCF | Voltage Controlled Filter
VCO | Voltage Controlled Oscillator

iii

## Abbildungsverzeichnis

2.1 Architektur eines modularen Synthesizers | | 3
3.1 Typische Signale bei analogen Synthesizern [3] | | 4
3.2 Oszillatorschaltung | | 5
3.3 Oszillator Signalverlauf | | 6
3.4 Schaltplan VCO | | 9
3.5 VCO Layout in Fusion 360 | | 10
3.6 Erstellung der Einbauklinkenbuchse in Fusion 360 | | 11
3.7 VCO Leiterplatte | | 11
3.8 VCO Frontplatte | | 12

iv

## Tabellenverzeichnis

3.1 Zusammenfassung der Ein- und Ausgabeelemente des VCOs | 8

v

## Kapitel 1
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

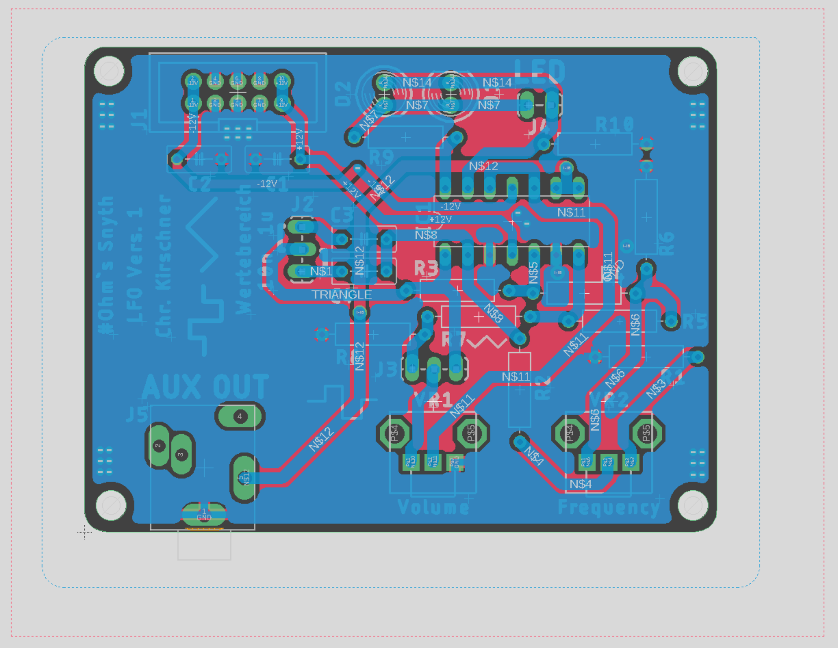
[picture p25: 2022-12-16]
Sonstiges/LPDES/VCO_Studienarbeit_Latex/thesis-template-master/figures/Platine_LFO.PNG

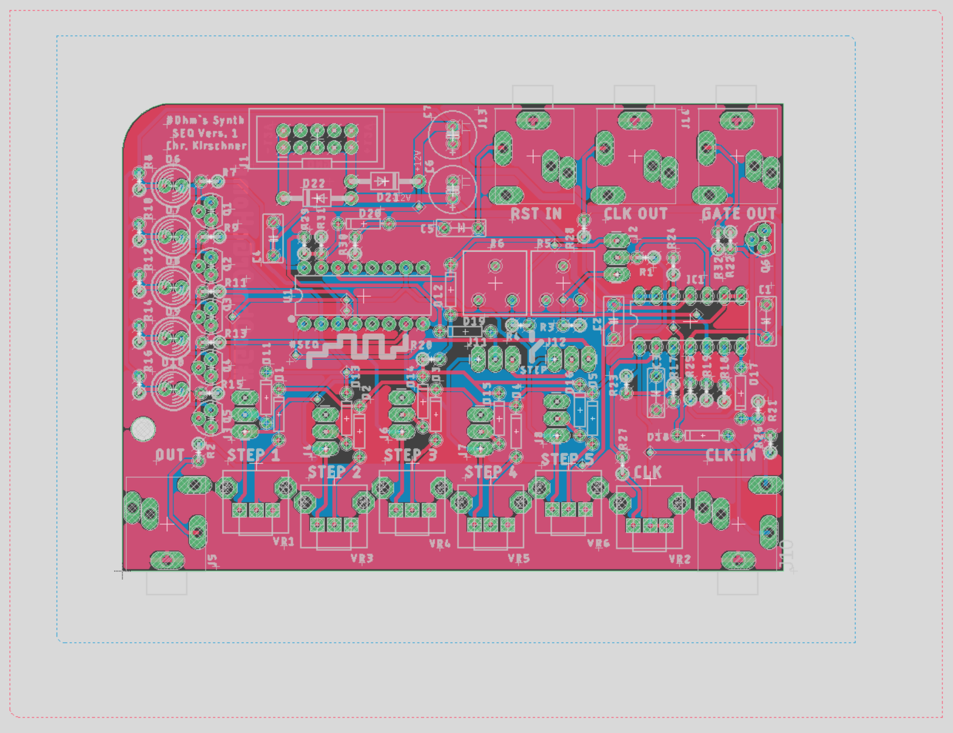
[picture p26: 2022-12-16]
Sonstiges/LPDES/VCO_Studienarbeit_Latex/thesis-template-master/figures/Sequenzer_Layout.PNG

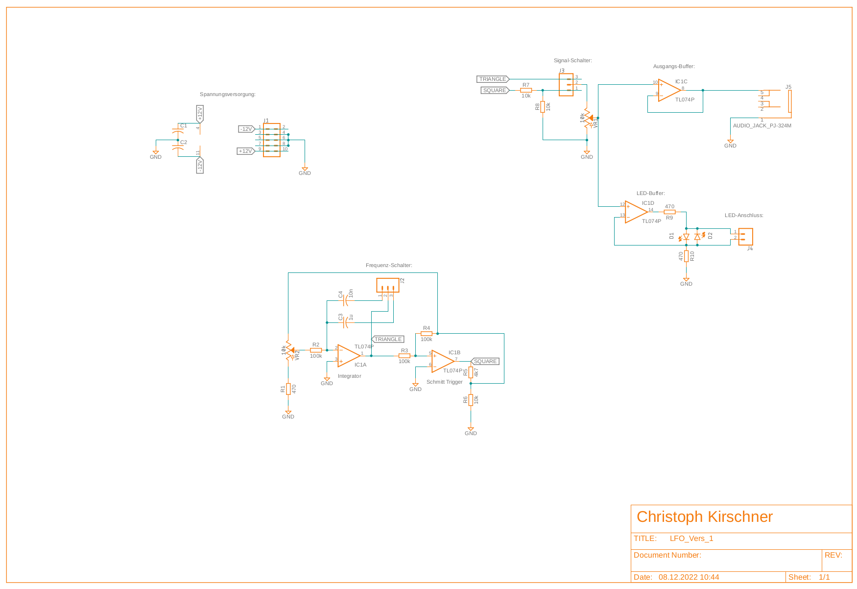
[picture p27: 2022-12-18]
Sonstiges/LPDES/VCO_Studienarbeit_Latex/thesis-template-master/figures/LFO_Schaltplan.png

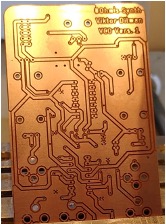
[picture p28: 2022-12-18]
Sonstiges/LPDES/VCO_Studienarbeit_Latex/thesis-template-master/figures/VCO_gefraest.jpg

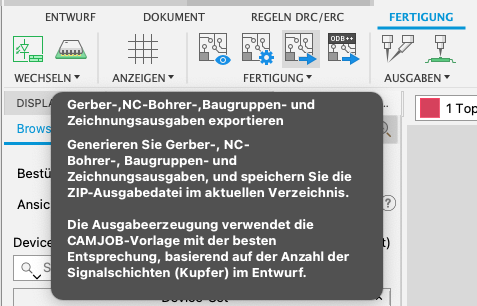
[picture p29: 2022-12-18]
Sonstiges/LPDES/VCO_Studienarbeit_Latex/thesis-template-master/figures/Fusion Export Gerber.png

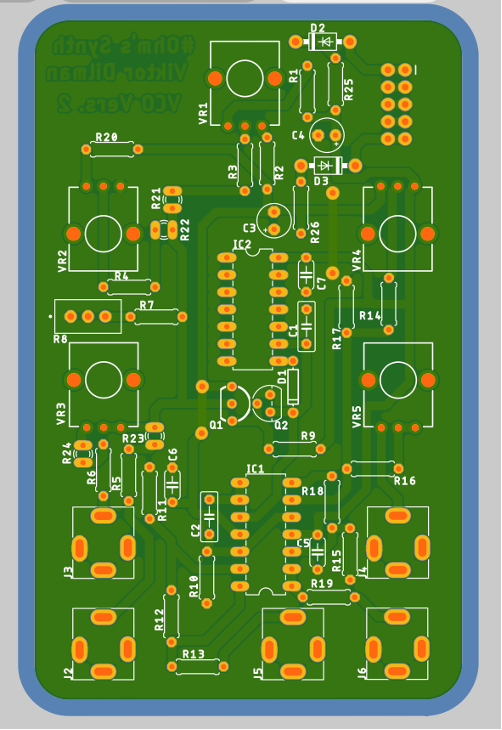
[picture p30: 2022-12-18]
Sonstiges/LPDES/VCO_Studienarbeit_Latex/thesis-template-master/figures/VCO_Rendering.png

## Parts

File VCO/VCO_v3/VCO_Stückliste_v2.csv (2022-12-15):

Part | Value | Device | Package | Description | CATEGORY | DESCRIPTION | IC_MAX | MANUFACTURER | MF | MPN | OC_FARNELL | OC_NEWARK | OPERATING_TEMP | OPERATING_TEMPERATURE | PART_STATUS | POPULARITY | PROD_ID | ROHS_COMPLIANCE | ROHS_COMPLIANT | SERIES | SF_ID | SF_SKU | SPICEPREFIX | SUB-CATEGORY | THERMALLOSS | TYPE | VALUE | VCEO_MAX
C1 | 2.2n | C-EU050-025X075 | C050-025X075 | CAPACITOR, European symbol |  |  |  |  |  |  |  |  |  |  |  | 29 |  |  |  |  |  |  | C
C2 | 1u | C-EU050-025X075 | C050-025X075 | CAPACITOR, European symbol |  |  |  |  |  |  |  |  |  |  |  | 29 |  |  |  |  |  |  | C
C3 | 47uFx16V | CPOL-EUE2.5-5 | E2,5-5 | POLARIZED CAPACITOR, European symbol |  |  |  |  |  |  |  |  |  |  |  | 16 |  |  |  |  |  |  | C
C4 | 47uFx16V | CPOL-EUE2.5-5 | E2,5-5 | POLARIZED CAPACITOR, European symbol |  |  |  |  |  |  |  |  |  |  |  | 16 |  |  |  |  |  |  | C
C5 | 0.1uF | C-EU050-024X044 | C050-024X044 | CAPACITOR, European symbol |  |  |  |  |  |  |  |  |  |  |  | 33 |  |  |  |  |  |  | C
C6 | 0.1uF | C-EU050-024X044 | C050-024X044 | CAPACITOR, European symbol |  |  |  |  |  |  |  |  |  |  |  | 33 |  |  |  |  |  |  | C
C7 | 0.1uF | C-EU050-024X044 | C050-024X044 | CAPACITOR, European symbol |  |  |  |  |  |  |  |  |  |  |  | 33 |  |  |  |  |  |  | C
D1 |  | DIODEDO-1N4148 | DO-1N4148 | Diode
D2 |  | SCHOTTKY-DIODEDO41-7 | DO41-7 | Schottky Diode
D3 |  | SCHOTTKY-DIODEDO41-7 | DO41-7 | Schottky Diode
IC1 | TL074P | TL074P | DIL14 | OP AMP |  |  |  |  |  |  |  |  |  |  |  | 0
IC2 | CD40106B | CD40106B | DIL14 | Hex schmitt trigger INVERTER | IC_Logic | CD40106BE |  |  |  |  |  |  |  |  |  |  |  |  |  |  |  |  |  | Inverter
J1 |  | CONN_05X2SHD | 2X5-SHROUDED | Multi connection point. Often used as Generic Header-pin footprint for 0.1 inch spaced/style header connections |  |  |  |  |  |  |  |  |  |  |  |  | CONN-08671 |  |  |  | PRT-08506
J2 |  | AUDIO_JACK_3.5MM_PTH | AUDIO-JACK | Audio Jack |  |  |  |  |  |  |  |  |  |  |  |  | CONN-08774 |  |  |  | PRT-08032
J3 |  | AUDIO_JACK_3.5MM_PTH | AUDIO-JACK | Audio Jack |  |  |  |  |  |  |  |  |  |  |  |  | CONN-08774 |  |  |  | PRT-08032
J4 |  | AUDIO_JACK_3.5MM_PTH | AUDIO-JACK | Audio Jack |  |  |  |  |  |  |  |  |  |  |  |  | CONN-08774 |  |  |  | PRT-08032
J5 |  | AUDIO_JACK_3.5MM_PTH | AUDIO-JACK | Audio Jack |  |  |  |  |  |  |  |  |  |  |  |  | CONN-08774 |  |  |  | PRT-08032
J6 |  | AUDIO_JACK_3.5MM_PTH | AUDIO-JACK | Audio Jack |  |  |  |  |  |  |  |  |  |  |  |  | CONN-08774 |  |  |  | PRT-08032
Q1 | BC558 | TRANSISTOR_PNPBC558 | TO-92-AMMO | Generic PNP BJT |  |  |  |  |  |  |  |  |  |  |  |  |  |  |  |  |  |  | Q
Q2 | NPN | NPN_TO92-EBC | TO92 | NPN - Generic | Transistor |  |  |  |  |  |  |  |  |  |  |  |  |  |  |  |  |  |  | BJT |  | NPN | NPN
R1 | 100k | R-EU_0207/7 | 0207/7 | RESISTOR, European symbol |  |  |  |  |  |  |  |  |  |  |  | 46 |  |  |  |  |  |  | R
R2 | 33k | R-EU_0207/7 | 0207/7 | RESISTOR, European symbol |  |  |  |  |  |  |  |  |  |  |  | 46 |  |  |  |  |  |  | R
R3 | 100k | R-EU_0207/7 | 0207/7 | RESISTOR, European symbol |  |  |  |  |  |  |  |  |  |  |  | 46 |  |  |  |  |  |  | R
R4 | 1M | R-EU_0207/7 | 0207/7 | RESISTOR, European symbol |  |  |  |  |  |  |  |  |  |  |  | 46 |  |  |  |  |  |  | R
R5 | 100k | R-EU_0207/7 | 0207/7 | RESISTOR, European symbol |  |  |  |  |  |  |  |  |  |  |  | 46 |  |  |  |  |  |  | R
R6 | 100k | R-EU_0207/7 | 0207/7 | RESISTOR, European symbol |  |  |  |  |  |  |  |  |  |  |  | 46 |  |  |  |  |  |  | R
R7 | 1k5 | R-EU_0207/7 | 0207/7 | RESISTOR, European symbol |  |  |  |  |  |  |  |  |  |  |  | 46 |  |  |  |  |  |  | R
R8 | 1k | PV36W | PV36W | Rectangular Trimmer Potentiometers - PV36 Series | Resistor | Lead Sealed Type Multiturn PV36 Series |  | BOURNS |  | PV36W |  |  |  | -55 to +125 °C | Active |  |  | RoHS Compliant |  | PV36 |  |  |  | Trimpot |  | Lead Sealed
R9 | 1M | R-EU_0207/7 | 0207/7 | RESISTOR, European symbol |  |  |  |  |  |  |  |  |  |  |  | 46 |  |  |  |  |  |  | R
R10 | 100k | R-EU_0207/7 | 0207/7 | RESISTOR, European symbol |  |  |  |  |  |  |  |  |  |  |  | 46 |  |  |  |  |  |  | R
R11 | 47k | R-EU_0207/7 | 0207/7 | RESISTOR, European symbol |  |  |  |  |  |  |  |  |  |  |  | 46 |  |  |  |  |  |  | R
R12 | 100k | R-EU_0207/7 | 0207/7 | RESISTOR, European symbol |  |  |  |  |  |  |  |  |  |  |  | 46 |  |  |  |  |  |  | R
R13 | 1k | R-EU_0207/7 | 0207/7 | RESISTOR, European symbol |  |  |  |  |  |  |  |  |  |  |  | 46 |  |  |  |  |  |  | R
R14 | 100k | R-EU_0207/7 | 0207/7 | RESISTOR, European symbol |  |  |  |  |  |  |  |  |  |  |  | 46 |  |  |  |  |  |  | R
R15 | 68k | R-EU_0207/7 | 0207/7 | RESISTOR, European symbol |  |  |  |  |  |  |  |  |  |  |  | 46 |  |  |  |  |  |  | R
R16 | 68k | R-EU_0207/7 | 0207/7 | RESISTOR, European symbol |  |  |  |  |  |  |  |  |  |  |  | 46 |  |  |  |  |  |  | R
R17 | 14k | R-EU_0207/7 | 0207/7 | RESISTOR, European symbol |  |  |  |  |  |  |  |  |  |  |  | 46 |  |  |  |  |  |  | R
R18 | 100k | R-EU_0207/7 | 0207/7 | RESISTOR, European symbol |  |  |  |  |  |  |  |  |  |  |  | 46 |  |  |  |  |  |  | R
R19 | 1k | R-EU_0207/7 | 0207/7 | RESISTOR, European symbol |  |  |  |  |  |  |  |  |  |  |  | 46 |  |  |  |  |  |  | R
R20 | 100k | R-EU_0207/7 | 0207/7 | RESISTOR, European symbol |  |  |  |  |  |  |  |  |  |  |  | 46 |  |  |  |  |  |  | R
R21 | 10k | NTC640 | P640 | PHILIPS NTC |  |  |  |  |  |  | unknown | unknown |  |  |  | 3
R22 | 10k | NTC640 | P640 | PHILIPS NTC |  |  |  |  |  |  | unknown | unknown |  |  |  | 3
R23 | 10k | NTC640 | P640 | PHILIPS NTC |  |  |  |  |  |  | unknown | unknown |  |  |  | 3
R24 | 10k | NTC640 | P640 | PHILIPS NTC |  |  |  |  |  |  | unknown | unknown |  |  |  | 3
R25 | 10 | R-EU_0207/7 | 0207/7 | RESISTOR, European symbol |  |  |  |  |  |  |  |  |  |  |  | 46 |  |  |  |  |  |  | R
R26 | 10 | R-EU_0207/7 | 0207/7 | RESISTOR, European symbol |  |  |  |  |  |  |  |  |  |  |  | 46 |  |  |  |  |  |  | R
VR1 | 100k | POTENTIOMETER-PTH-9MM-1/20W-20%-KIT | POT-PTH-ALPS-KIT | Potentiometer (Pot) |  |  |  |  |  |  |  |  |  |  |  |  | RES-09177 |  |  |  |  | COM-09288 |  |  |  |  | 10k
VR2 | 100k | POTENTIOMETER-PTH-9MM-1/20W-20%-KIT | POT-PTH-ALPS-KIT | Potentiometer (Pot) |  |  |  |  |  |  |  |  |  |  |  |  | RES-09177 |  |  |  |  | COM-09288 |  |  |  |  | 10k
VR3 | 1M | POTENTIOMETER-PTH-9MM-1/20W-20%-KIT | POT-PTH-ALPS-KIT | Potentiometer (Pot) |  |  |  |  |  |  |  |  |  |  |  |  | RES-09177 |  |  |  |  | COM-09288 |  |  |  |  | 10k
VR4 | 100k | POTENTIOMETER-PTH-9MM-1/20W-20%-KIT | POT-PTH-ALPS-KIT | Potentiometer (Pot) |  |  |  |  |  |  |  |  |  |  |  |  | RES-09177 |  |  |  |  | COM-09288 |  |  |  |  | 10k
VR5 | 250k | POTENTIOMETER-PTH-9MM-1/20W-20%-KIT | POT-PTH-ALPS-KIT | Potentiometer (Pot) |  |  |  |  |  |  |  |  |  |  |  |  | RES-09177 |  |  |  |  | COM-09288 |  |  |  |  | 10k

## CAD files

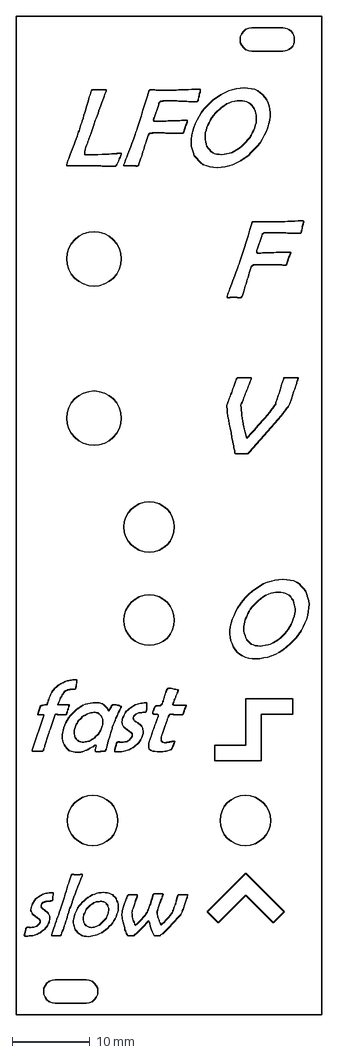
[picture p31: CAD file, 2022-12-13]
Frontplatte/LFO_Frontplatte_Vers_2.dxf
39.3 x 128.5 mm

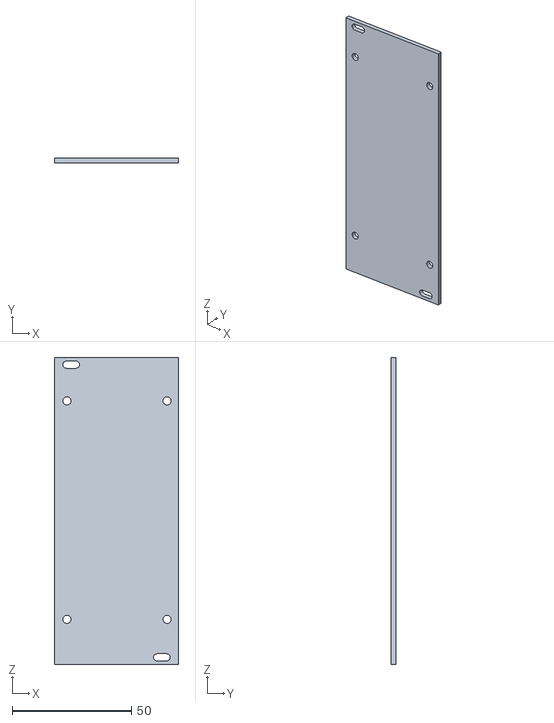
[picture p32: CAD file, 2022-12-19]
Netzteil/Abdeckung_Netzteil_19.12.22.stl
52.0 x 2.00 x 128.5

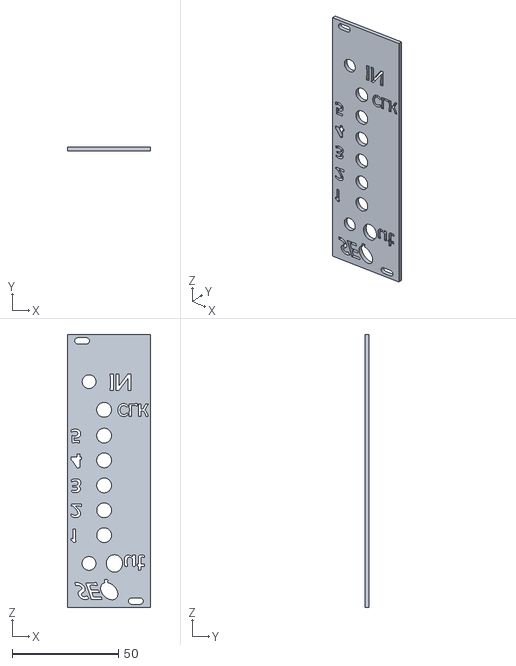
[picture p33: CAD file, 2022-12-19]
SEQ/Frontplatte_Sequenzer_19.12.22.stl
39.3 x 2.00 x 128.5

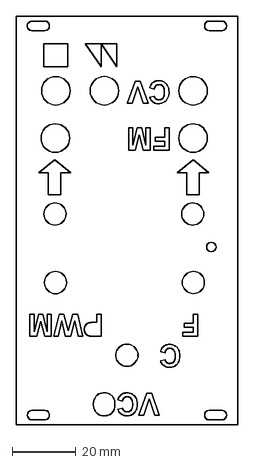
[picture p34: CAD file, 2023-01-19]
VCO/VCO_v3/Frontplatte/Frontplatte_mit_Beschriftung.dxf
69.8 x 128.5 mm

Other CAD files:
Frontplatte/VCF_Frontplatte_Vers_1.stl
Frontplatte/Abdeckung_Vorlage_8HP.f3d
Frontplatte/VCF_Abdeckung_v7.f3z
Frontplatte/VCF_Frontplatte_Vers_1.dxf
LFO/LFO_Vers_1_v31.f3z
Mixer/Mixer _schaltplan _2.14.23 (1).f3z
Mixer/Mixer v18.f3z
VCF/Archivdatei_VCF_v4_22_11_22.f3z
VCF/VCF_Frontplatte_Vers_1 v1.f3d

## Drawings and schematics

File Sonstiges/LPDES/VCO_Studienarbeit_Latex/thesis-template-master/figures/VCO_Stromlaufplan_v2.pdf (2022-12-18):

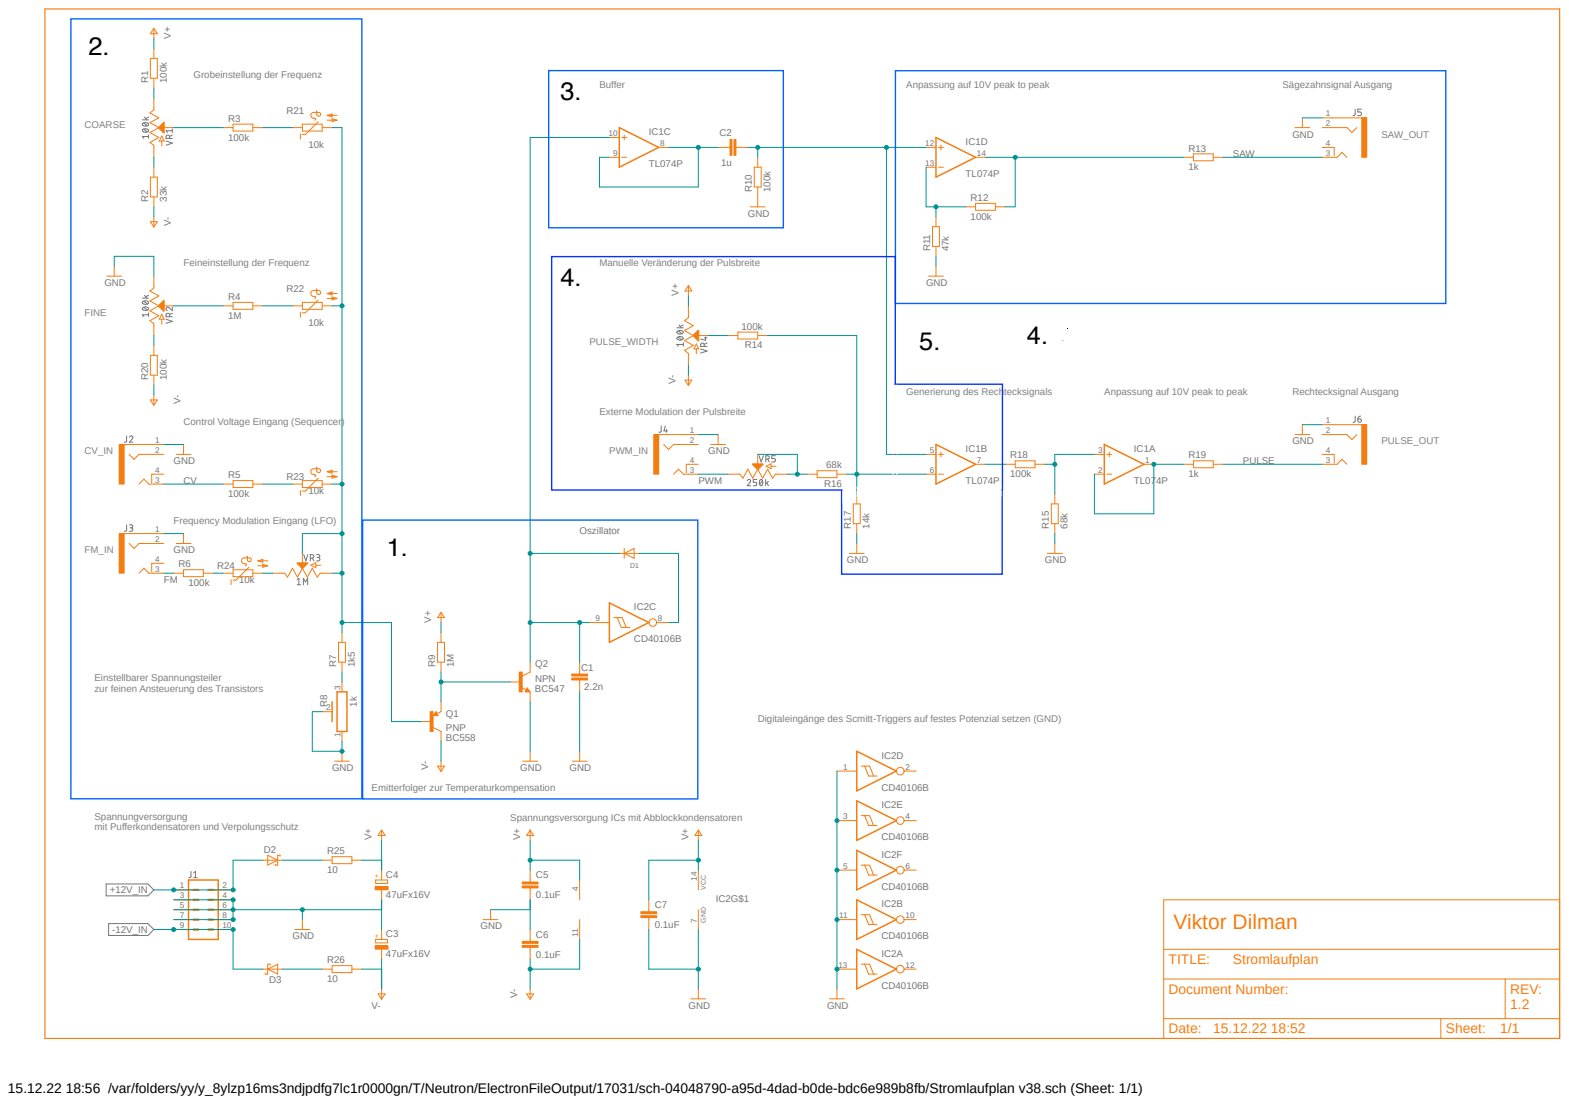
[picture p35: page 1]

Anpassung auf 10V peak to peak

Manuelle Veränderung der Pulsbreite

Externe Modulation der Pulsbreite

Control Voltage Eingang (Sequencer)

Einstellbarer Spannungsteiler
zur feinen Ansteuerung des Transistors

Digitaleingänge des Scmitt-Triggers auf festes Potenzial setzen (GND)

Spannungversorgung
mit Pufferkondensatoren und Verpolungsschutz

Spannungsversorgung ICs mit Abblockkondensatoren

Document Number: | REV: 1.2

Date: 15.12.22 18:52 | Sheet: 1/1

15.12.22 18:56 /var/folders/yy/y_8ylzp16ms3ndjpdfg7lc1r0000gn/T/Neutron/ElectronFileOutput/17031/sch-04048790-a95d-4dad-b0de-bdc6e989b8fb/Stromlaufplan v38.sch (Sheet: 1/1)

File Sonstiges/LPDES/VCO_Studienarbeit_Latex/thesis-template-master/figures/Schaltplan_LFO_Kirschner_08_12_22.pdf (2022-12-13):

# 1 R¹

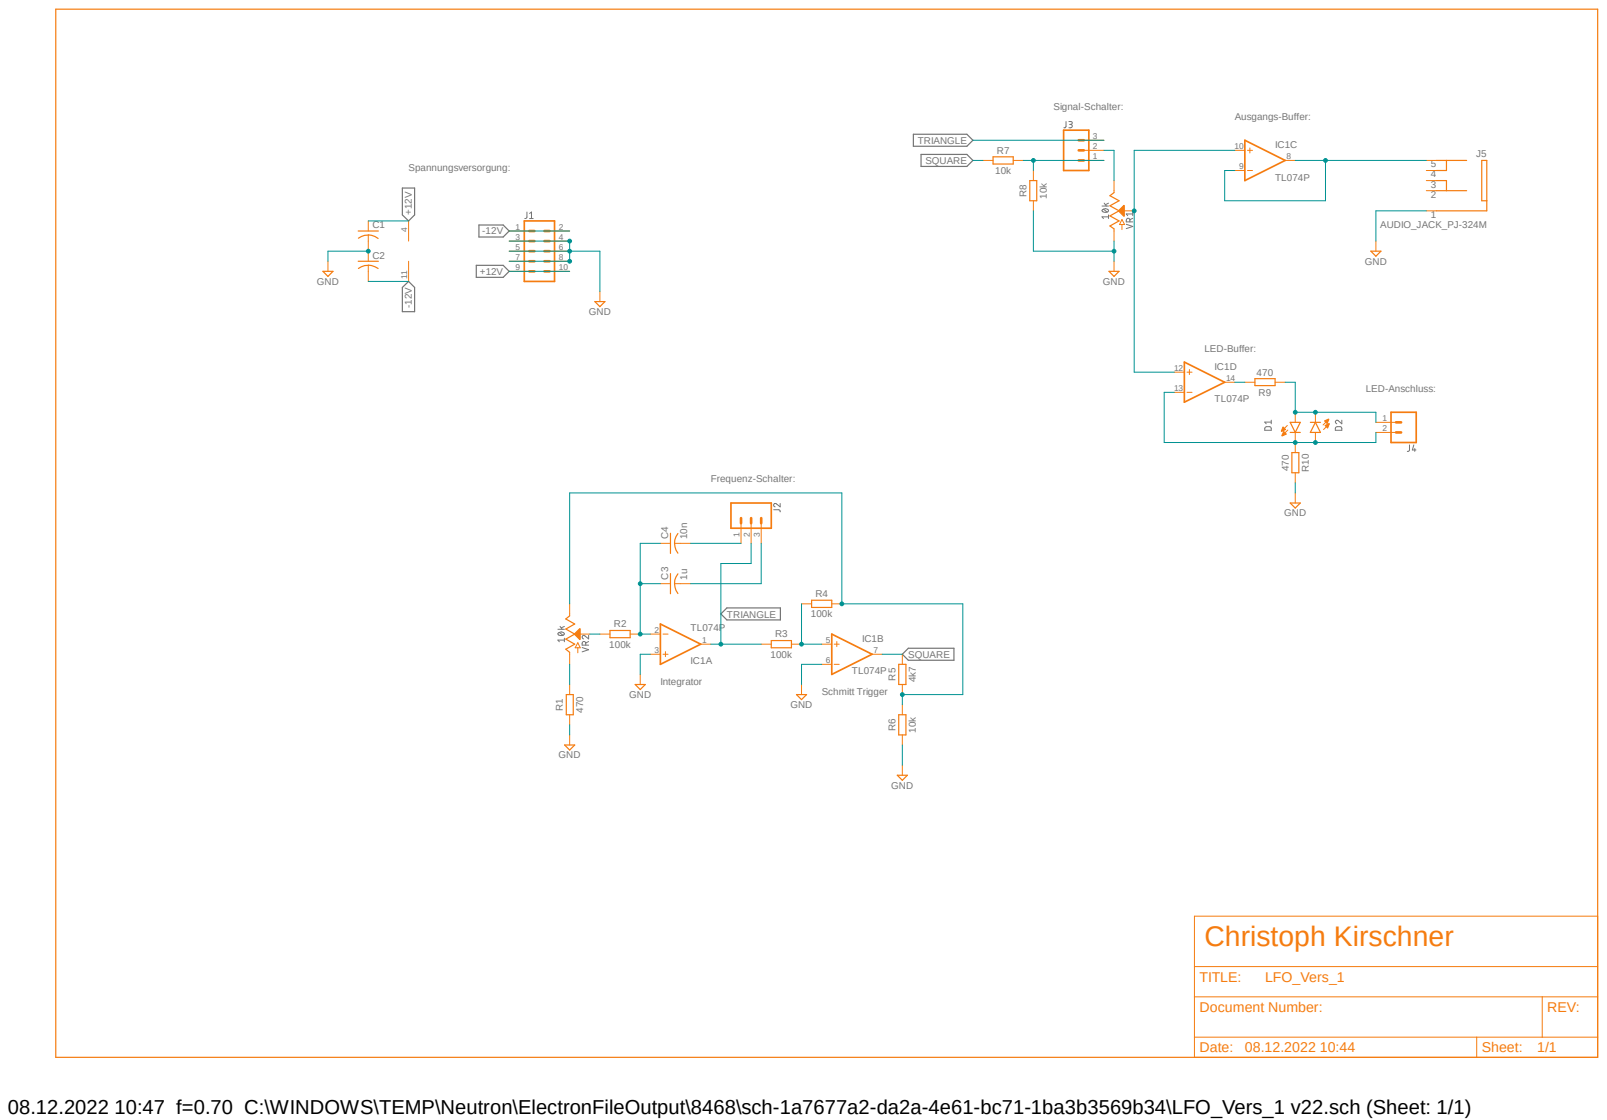
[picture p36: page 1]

Document Number: | REV:

Date: 08.12.2022 10:44 | Sheet: 1/1

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

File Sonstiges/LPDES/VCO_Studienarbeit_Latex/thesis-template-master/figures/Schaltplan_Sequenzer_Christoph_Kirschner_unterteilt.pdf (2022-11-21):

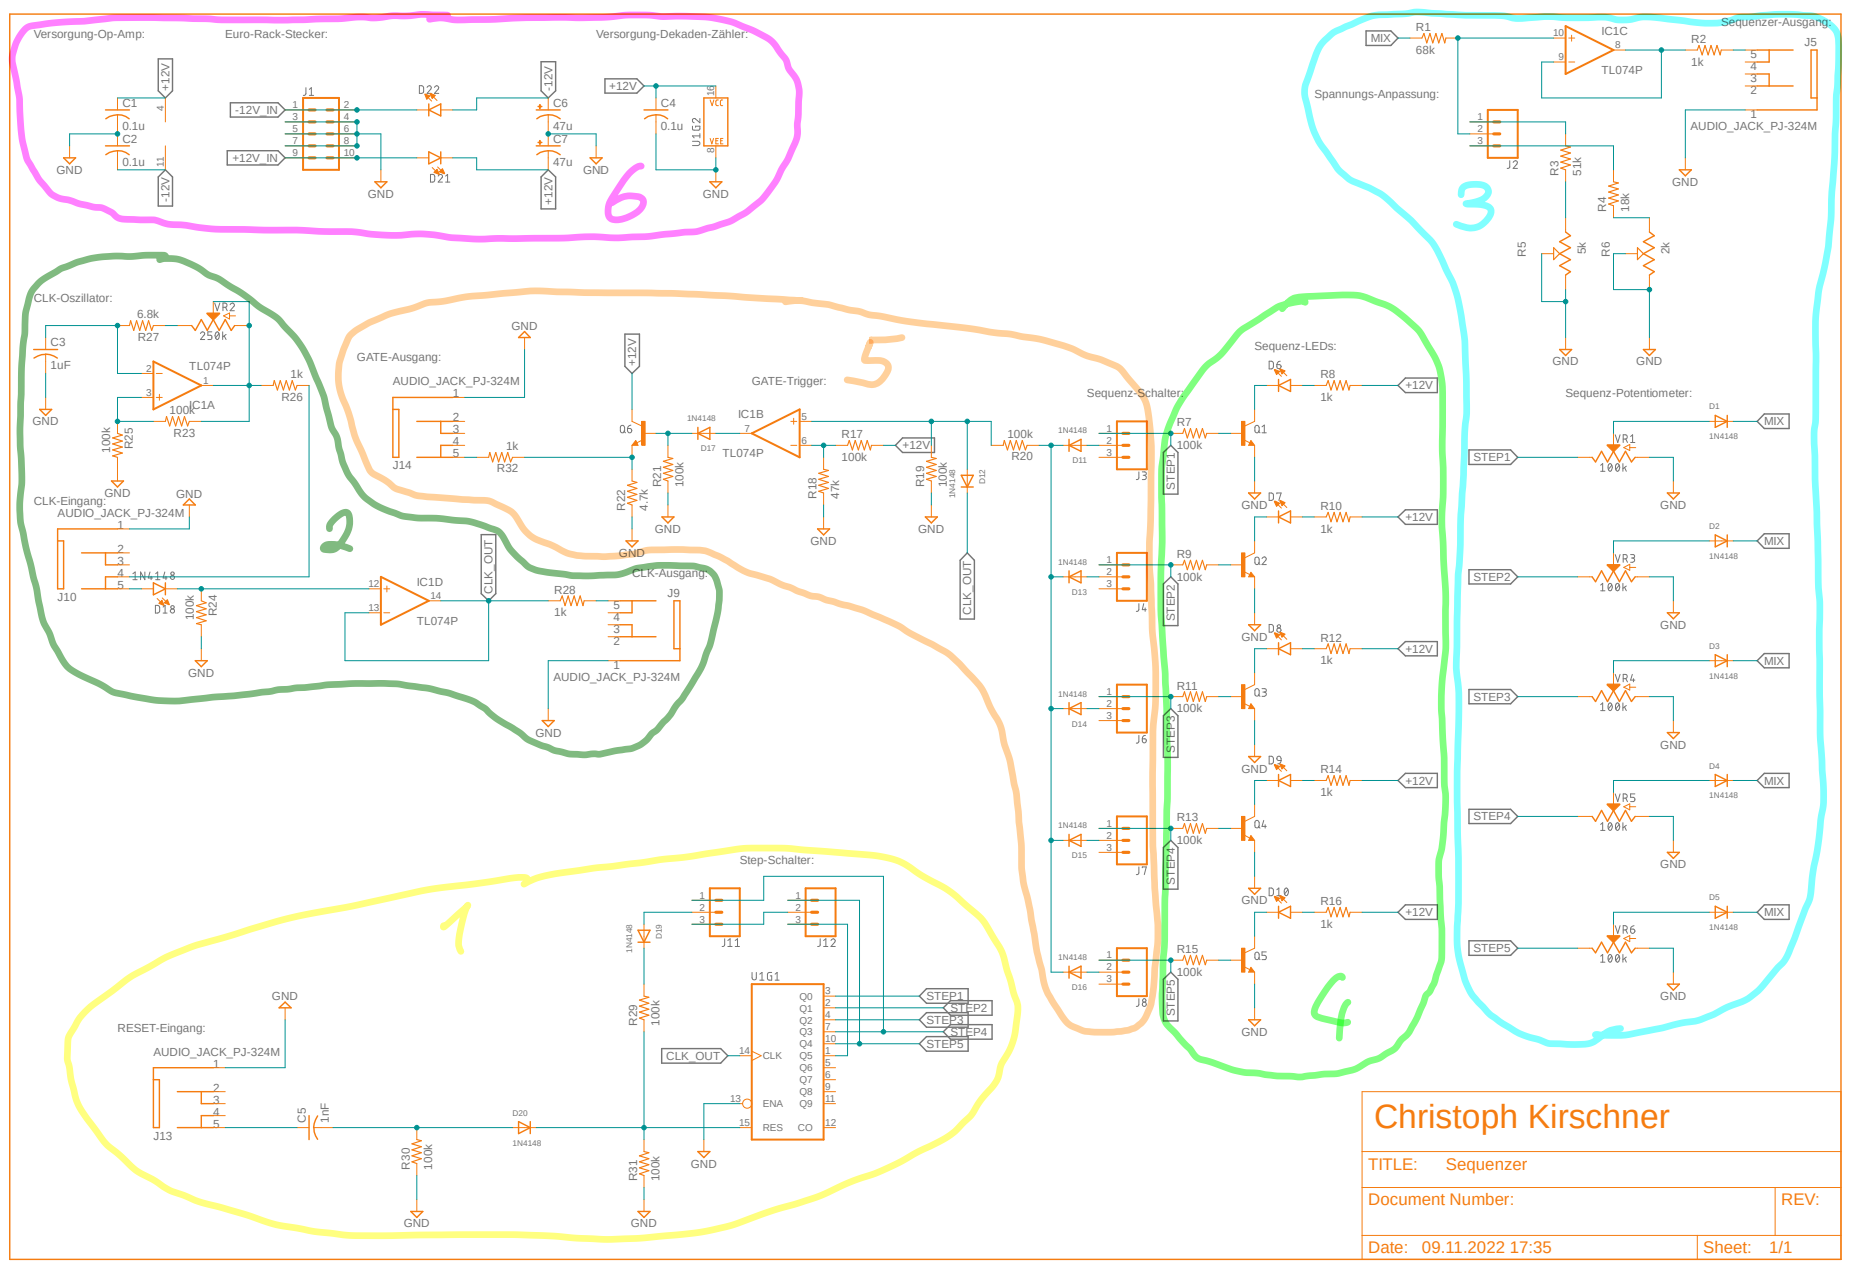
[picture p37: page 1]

Document Number: | REV:

Date: 09.11.2022 17:35 | Sheet: 1/1

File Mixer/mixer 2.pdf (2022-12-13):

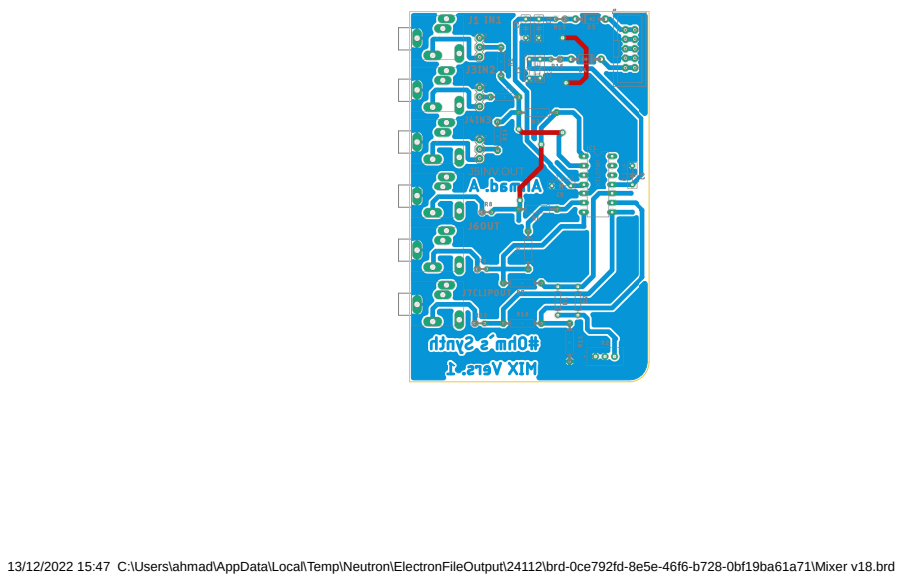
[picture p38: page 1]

13/12/2022 15:47 C:\Users\ahmad\AppData\Local\Temp\Neutron\ElectronFileOutput\24112\brd-0ce792fd-8e5e-46f6-b728-0bf19ba61a71\Mixer v18.brd

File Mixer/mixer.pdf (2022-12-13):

1

2

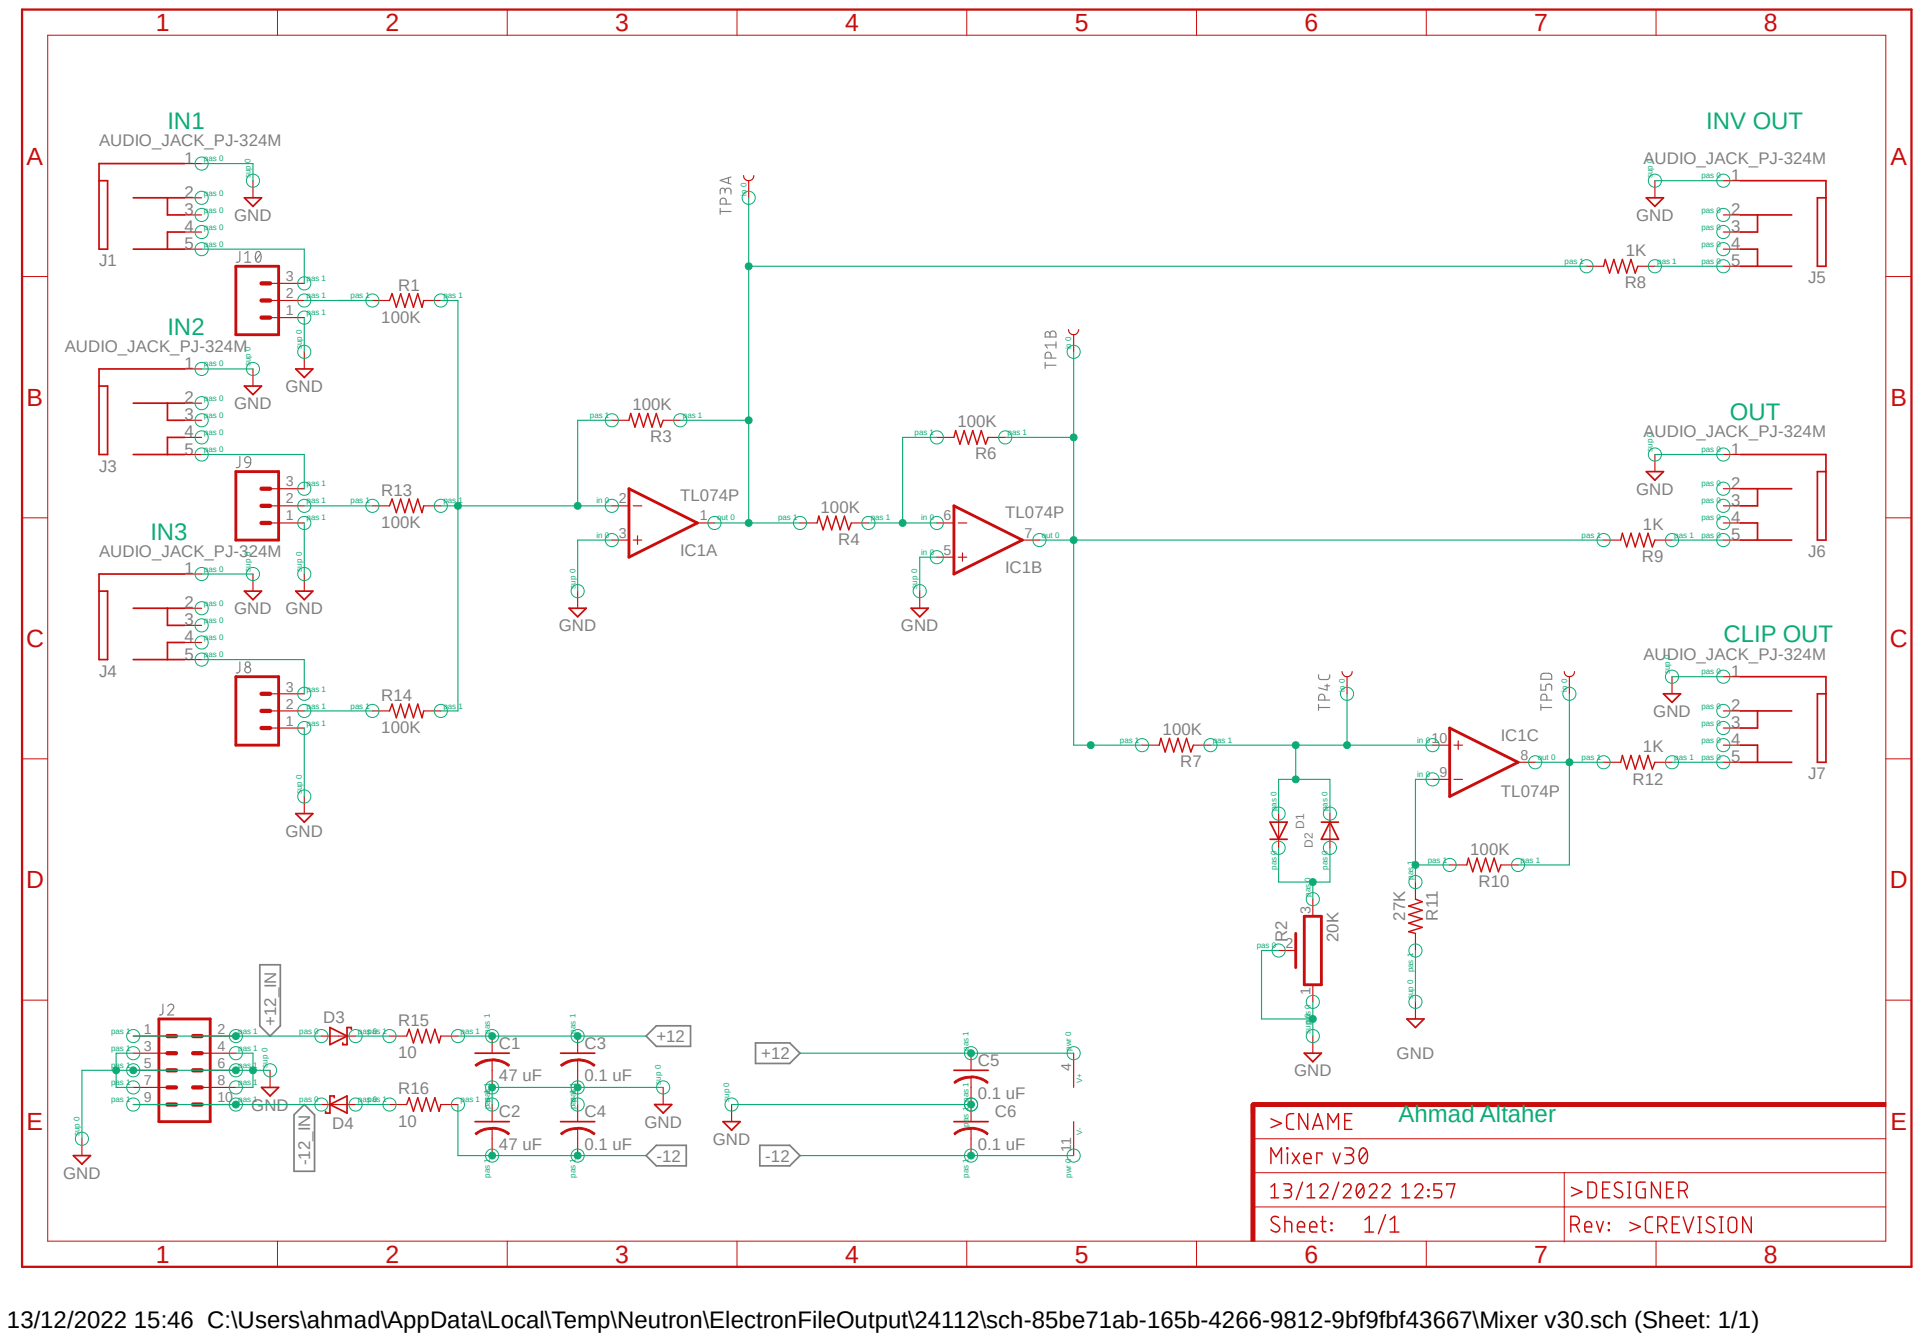
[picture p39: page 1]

pas 0 io 0 sup 0 sup 0 sup 0 sup 0 sup 0

13/12/2022 15:46 C:\Users\ahmad\AppData\Local\Temp\Neutron\ElectronFileOutput\24112\sch-85be71ab-165b-4266-9812-9bf9fbf43667\Mixer v30.sch (Sheet: 1/1)

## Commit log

2022-09-27 Added Lib for LM358B and Circuit for VCF
2022-09-27 added HP1 Filter
2022-10-15 added Doku vcf.md and editet Values on Resistors of VCF_LP2
2022-10-18 Liste aktualisiert und umbenannt (Ahmad)
2022-10-18 Latex hinzugefügt und Zeitplan etc. (C.K)
2022-10-18 LATEX Files eingebunden und grundlegend angepasst (C.K.)
2022-10-18 Bauteile für Sequencer überarbeiten
    -Widerstände fertig
    -Kondensatoren fertig
    -Dioden fertig
    -Transistoren fertig
2022-10-20 Projektauftrag hinzugefuegt (C.K)
    [1_Projektauftrag_modularer_Synthesizer_Vorlage.xlsx]
2022-10-20 Bauteilliste VCO korrigiert, ergänzt und validiert
    Graue Bauteile sind nicht direkt aus der Moritz-Klein Bauteilliste, sollten aber zusätzlich bestellt werden
2022-10-24 worked on Controll Voltage, added NJFET
2022-10-31 Added Projektauftrag Sequenzer
    [1_Projektauftrag_modularer-Synthesizer_Sequenzer_Balbach-Thomas.xlsx]
2022-11-09 Schaltplaene von LFO und SEQ hinzugefuegt C.K.
2022-11-21 Doku - Sequenzer - erste Beschreibung
    -Allgemein beschrieben
    -Schaltplan in Bereiche unterteilt und eingebunden
    -Schaltplan beschrieben
    -Label anderer Kapitel für benötigte Querverweise angepasst
2022-11-21 VCO Platinenlayout
    [VCO_v1.f3z]
2022-11-21 VCO gerber
2022-11-22 Schaltplan/Layout/Archiv von VCF hinzugefuegt
    [Archivdatei_VCF_v4_22_11_22.f3z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]
2022-11-22 VCO Frontplatte
    [VCO_Frontplatte.dxf]
2022-11-28 VCO Stückliste
    [Stückliste_VCO.csv]
2022-12-07 Frontplatte VCF konstruiert
    [VCF_Frontplatte_Vers_1.dxf, VCF_Frontplatte_Vers_1.stl]
2022-12-07 VCO Frontplatte 3D-Druck
    [VCO_Frontplatte_3D_Druck.stl]
2022-12-08 LFO Platine korrigiert und Frontplatte geupdated
    [LFO_Frontplatte_Vers_2.dxf, LFO_Vers_1_v31.f3z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]
2022-12-08 loch für led bei LFO hinzugefügt
    [LFO_Frontplatte_Vers_2.dxf]
2022-12-12 grundlegende Struktur des Vortrags erstellt
2022-12-15 VCO_v2 Gerber, Fusion Elektronikentwurf, Stromlaufplan, Stückliste
    [Stückliste_VCO.csv, VCO_Frontplatte.dxf, VCO_Frontplatte_3D_Druck.stl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]
2022-12-16 bilder erstellt für lfo und seq
2022-12-19 stl und bilder hinzugefügt
    [Abdeckung_Netzteil_19.12.22.stl, Frontplatte_Sequenzer_19.12.22.stl]
2022-12-19 Latex: Produktarchitektur Synthesizer und Kapitel VCO Überarbeitung
2022-12-21 Überarbeitung Kapitel VCO und Hinzufügen Literaturverzeichnis
2022-12-22 Latex: Verzeichnisse + Abkürzungsverzeichnisse hinzugefügt und Ergänzung Kapitel VCO
2022-12-22 Thesis.tex für die Studienarbeit als Vorlage :)
2023-01-09 neu board dateien
    [copper_bottom.gbr, copper_top.gbr, drill_1_16.xln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]
2023-01-19 VCO-Frontplatte mit Beschriftung
    [Frontplatte_mit_Beschriftung.dxf]
2023-02-12 Ausarbeitung Filter begonnen
2023-02-14 Aufräumarbeiten
    [1_Projektauftrag_modularer-Synthesizer_Sequenzer_Balbach-Thomas.xlsx, 1_Projektauftrag_modularer_Synthesizer_Vorlage.xlsx, Abdeckung_Vorlage_8HP.f3d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]
2023-02-14 Aufräumarbeiten die 2.
    [1_Projektauftrag_modularer-Synthesizer_Sequenzer_Balbach-Thomas.xlsx, 1_Projektauftrag_modularer_Synthesizer_Vorlage.xlsx, Abdeckung_Vorlage_8HP.f3d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]
2023-02-14 VCO_v3_Projekt für die Abgabe
    Wannenstecker richtig herum gedreht
    [Frontplatte_mit_Beschriftung.dxf, Stückliste_VCO.csv, VCO_Frontplatte.dxf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]
2023-02-15 Mixer schaltplan
    [Mixer v22.02.15.23.f3z]
2023-02-15 mixer layout
    [Mixer _schaltplan _2.14.23 (1).f3z]
2023-02-15 Änderungen in Doku eingepflegt
    [VCF_Frontplatte_Vers_1 v1.f3d]
